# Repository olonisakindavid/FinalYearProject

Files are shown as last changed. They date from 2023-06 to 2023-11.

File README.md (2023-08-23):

# Portable Incubator For Detection Of Coliform In Water Using IoT

## Project Image

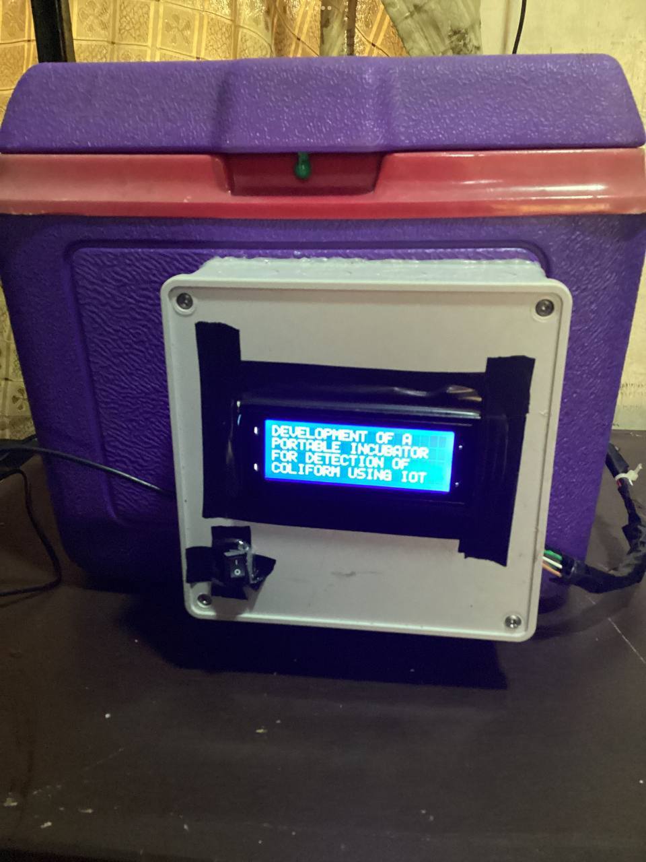
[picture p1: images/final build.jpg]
Project Image


## Description

This repository contains the project "Portable Incubator For Detection Of Coliform In Water Using IoT" created by Olonisakin David and Oguibe Favour. The project focuses on developing a portable incubator device that utilizes Internet of Things (IoT) technology for the detection of coliform bacteria in water.

## Features

- **IoT Connectivity**: The incubator is equipped with IoT capabilities, allowing real-time data transmission and remote monitoring of incubation processes.

- **Coliform Detection**: The device employs cost-effective techniques for detecting coliform bacteria in water samples, contributing to early water quality assessment.

- **Portability**: The incubator is designed to be easily portable, making it convenient for field applications and areas with limited laboratory infrastructure.

## Incubator Images

<div align="center">
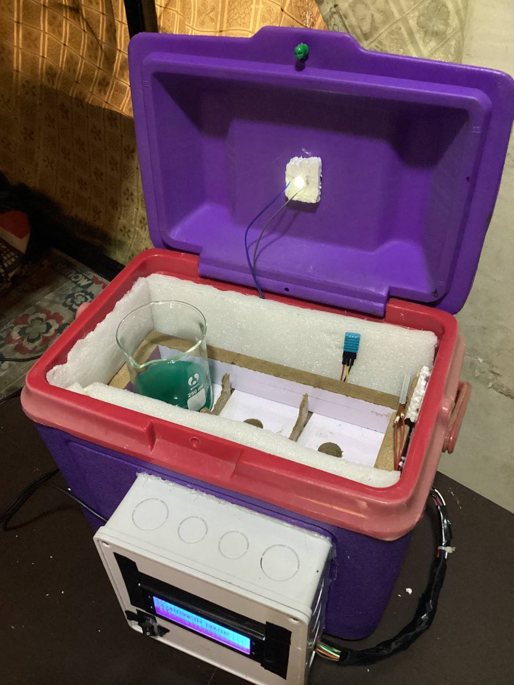
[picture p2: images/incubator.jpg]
Top Open View
  
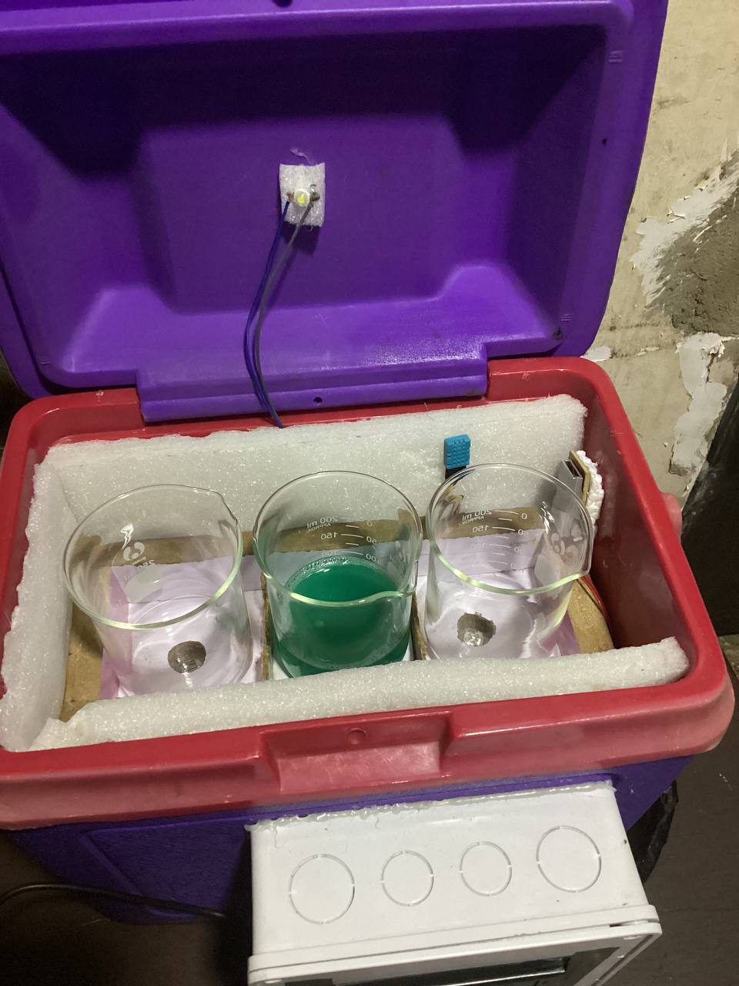
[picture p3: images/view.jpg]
Closed View
  
</div>

## Authors

- Olonisakin David
  Olonisakin David (https://www.linkedin.com/in/olonisakin-david)
- Oguibe Favour
  Oguibe Favour (https://www.linkedin.com/in/favour-oguibe-0a4081195)

## Authors' Image

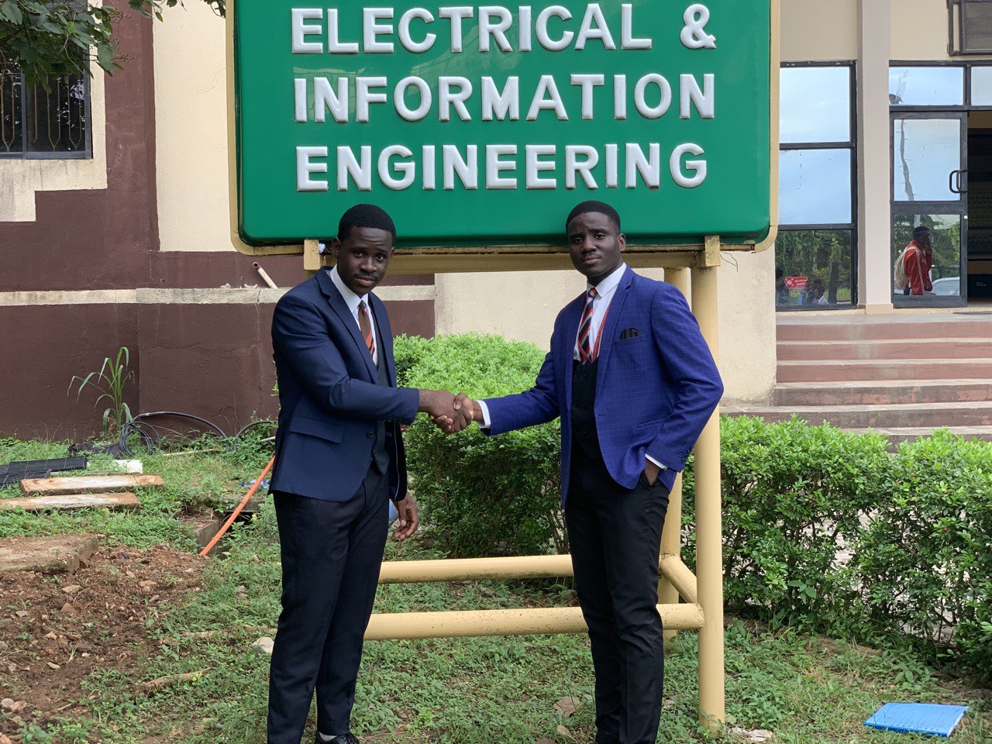
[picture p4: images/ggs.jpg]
Authors' Image


## Blynk Monitoring

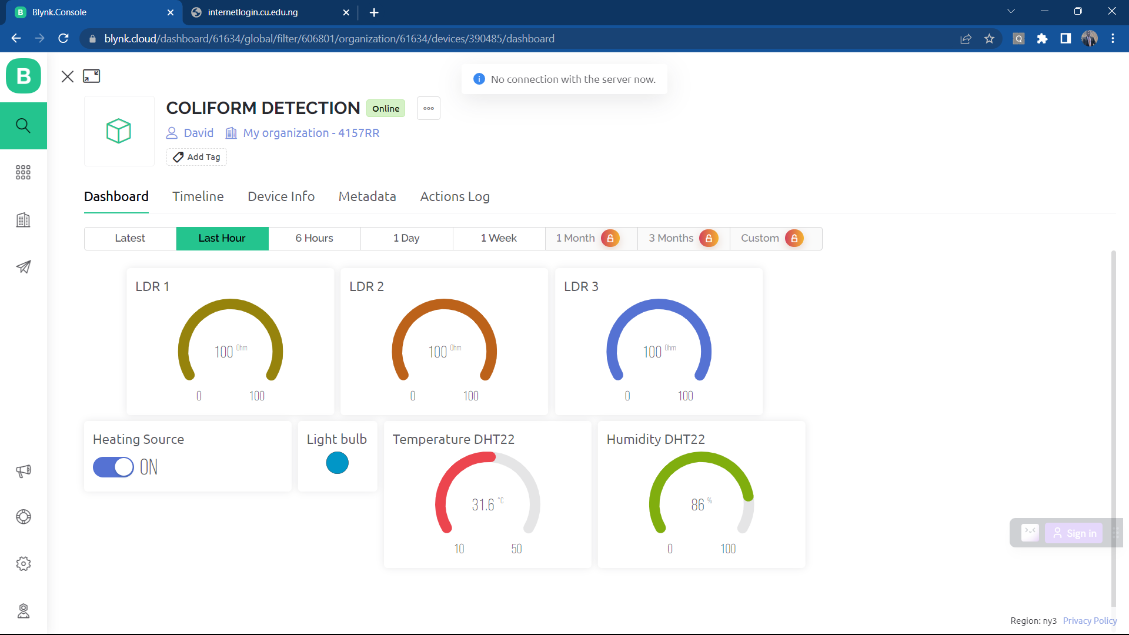
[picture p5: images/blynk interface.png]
Blynk Monitoring


---

**Please Note**: This README will be periodically updated with additional information, usage instructions, and resources as needed.

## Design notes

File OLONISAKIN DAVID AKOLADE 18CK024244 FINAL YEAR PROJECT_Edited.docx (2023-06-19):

DEVELOPMENT OF A PORTABLE INCUBATOR FOR THE DETECTION OF COLIFORM IN WATER USING IOT

BY

OLONISAKIN DAVID AKOLADE

(18CK024244)

A PROJECT REPORT SUBMITTED TO THE DEPARTMENT OF ELECTRICAL & INFORMATION ENGINEERING, IN PARTIAL FULFILLMENT OF THE REQUIREMENTS FOR THE AWARD OF THE BACHELOR OF ENGINEERING DEGREE IN ELECTRICAL AND ELECTRONICS ENGINEERING.

SUPERVISOR:

DR. OSEMWEGIE OMORUYI

JUNE 2023

# DECLARATION

I, OLONISAKIN DAVID AKOLADE (18CK024244), hereby declare that I carried out the work reported in this project in the Department of Electrical and Information Engineering, Covenant University, under the supervision of Dr. Osemwegie Omoruyi. I also solemnly declare that to the best of my knowledge; no part of this report has been submitted here or elsewhere in a previous application for the award of a degree. All sources of knowledge used have been duly acknowledged.

…………………………………………….

OLONISAKIN DAVID AKOLADE

18CK024244

# CERTIFICATION

This is to certify that the project titled “DEVELOPMENT OF A PORTABLE INCUBATOR FOR THE DETECTION OF COLIFORM IN WATER USING IOT” by OLONISAKIN DAVID AKOLADE, meets the requirements and regulations governing the award of the Bachelor of Engineering in Electrical and Electronics Engineering degree of Covenant University and is approved for its contribution to knowledge and literary presentation.

Dr. Osemwegie Omoruyi

(Supervisor) Sign: _________________ Date: ________________

Internal Examiner Sign: _________________ Date: ________________

Dr. Isaac Samuel Sign: _________________ Date: _______________

(Head of Department)

# DEDICATION

This research project is dedicated to my parents, Dr. Rotimi Olonisakin and Mrs. Bolatito Olonisakin who were very understanding and supportive throughout the time taken to complete this project, providing the resources necessary to make this project possible. I also dedicate this project to the countless communities in Nigeria who lack access to clean water.

# ACKNOWLEDGEMENTS

First and foremost, I would like to begin by expressing my deepest gratitude to God for His divine guidance, wisdom, and grace throughout this project. I am forever grateful for His constant presence and blessings in my life.

I would also like to extend my sincere appreciation to my parents for their unwavering love, support, and encouragement. Their sacrifices, guidance, and prayers have been a source of strength and motivation throughout this journey. I am truly blessed to have them as my role models.

I would like to express my heartfelt thanks to my project supervisor, Dr. Osemwegie Omoruyi for His invaluable guidance, expertise, and support. His insightful feedback, constructive criticism, and dedication have been instrumental in shaping the direction and success of this project.

Furthermore, I want to thank the Head of Department, Prof. Isaac Samuel, and all my lecturers for impacting me with knowledge and passing me through various tasks that have, in one way or the other, prepared me for the gallant execution of this project.

Finally, I would also like to acknowledge the support and encouragement of my lovely sisters, Favour and Delight Olonisakin, who have been there for me through thick and thin. Their kind words, motivational messages, and belief in my abilities have helped me to stay focused and motivated.

# ABSTRACT

Having access to clean and safe drinking water is considered a crucial human right, yet millions of individuals continue to live without it. The consumption of water that has been contaminated can increase the risk of experiencing outbreaks of different diseases that are transmitted through water, which are a leading cause of death worldwide. This project aims to develop a portable and low-cost incubator for detecting coliform bacteria in water, which is achieved by using a light-dependent resistor (LDR) and a heating element controlled by an IOT equipped microcontroller (ESP32). The incubator creates a controlled environment for water samples to incubate and for the LDR sensor to detect changes in turbidity, indicating the presence of coliform bacteria. Additionally, a Digital Humidity and Temperature (DHT22) sensor and a heating element helps maintain a temperature range of 35-37°C, the ideal temperature for optimal coliform bacteria growth. The incubator also features a Liquid Crystal Display (LCD) displaying resistance and temperature readings. After the data is collected, it is transferred to the microcontroller and subsequently transmitted to the Blynk application for continuous monitoring and analysis in real-time. The portability and affordability of this incubator makes it appropriate for use in remote areas where access to laboratory equipment is limited. The findings of this study carry significant implications for the advancement of low-cost and portable water quality monitoring systems, potentially leading to improvements in public health.

Keywords: portable incubator, water monitoring, coliform bacteria, light-dependent resistor.

TABLE OF CONTENT

# LIST OF FIGURES

# LIST OF TABLES

# INTRODUCTION

## 1.1 Background of Study

The study was inspired by the need for precise and trustworthy techniques for identifying waterborne infections, especially coliform bacteria, in places with few laboratory facilities. Coliform bacteria are used as a quality gauge for water and are a sign that potentially dangerous diseases may be present. The provision of drinking water is one of the major public health objectives because it is intimately related to human health. Consuming water that contains hazardous chemicals or pathogenic organisms has a major influence on one's health[1].

The lack of low-cost, simple-to-use, and accurate techniques for remote water monitoring and coliform detection is the key issue driving this research. Due to difficulties with transportation, sample storage, and inadequate laboratory facilities, traditional laboratory-based approaches are frequently not practical in remote places. Thus, the creation of a mobile incubator for coliform detection could be the answer to this issue.

The goal of 0074his project is to develop a portable incubator that can quickly and accurately detect coliform bacteria in water using an approach that is both affordable and simple to use. Detection of these organisms consists of, for example, filtering a 100 mL water sample through a membrane followed by incubation of the membrane on selective media at 35 - 37 °C (E. coli) or 44 - 45 °C (TTC) [2] . The issue of restricted access to laboratory facilities for water monitoring and coliform detection can be resolved by the portable incubator, especially in distant locations. The study is important because it may increase access to clean water, especially in locations where waterborne diseases are common. The mobile incubator might also be used for environmental research and monitoring, which would improve water management and public health.

## 1.2 Significance of Study

The development of a portable incubator for remote water monitoring and detection of coliform is an important initiative that can improve access to safe water, particularly in remote areas. Traditional laboratory-based methods for coliform detection are often not feasible in such areas due to transportation, sample storage, and limited laboratory facilities.

This project aims to address the problem of limited access to laboratory facilities by providing a low-cost, easy-to-use, and reliable method for remote water monitoring and coliform detection. The portable incubator is designed to use an LDR and a bulb, where a resistance drop or increase is detected depending on the coliform growth. This data is then sent to the ESP32 for further analysis. Additionally, a DHT 22 sensor is in place to regulate the temperature of the incubator at 35-37 degrees Celsius via the heater. The significance of this study is highlighted below;

1. Improve access to safe water, particularly in remote areas.
2. Enhance public health efforts in identifying and preventing waterborne diseases.
3. Contribute to water management and environmental monitoring research.
4. Increase efficiency in water monitoring by eliminating the need to transport water samples to a laboratory for analysis.
5. Enable citizen science initiatives for community-led efforts towards sustainable water management.

## 1.3 Problem Statement

The current methods for detecting coliform bacteria in water samples require laboratory analysis, which can be time-consuming and resource-intensive. This can limit the ability to effectively monitor water quality, particularly in remote areas. Therefore, there is a need for a portable incubator that can detect coliform bacteria remotely, and enable more efficient and timely water monitoring activities.

## 1.4 Aim and Objectives

Aim: To develop a portable incubator for remote water monitoring and detection of coliform.

Objectives

The objectives of this project are:

i. To design and construct a portable incubator that maintains a temperature range of 35-37°C using a ESP32-powered relay to control the heating element and sensor readings.
ii. To detect coliform bacteria growth using an LDR sensor and a bulb by monitoring the changes in resistance.
iii. To develop a real-time monitoring and data visualization of coliform levels.
iv. To validate the accuracy and effectiveness of the portable incubator in detecting coliform bacteria.

## 1.5 Methodology

The proposed research falls under the field of environmental science and aims to analyze the quality of water samples collected from various sources around Covenant University. The project will utilize the Waterfall model of methodology, an iterative process for creating a system or solving a problem that structures the entire job into segments to ensure precision.

### 1.5.1 Waterfall model of methodology

This project has been completed by following strategy, which is given in Figure 1.1

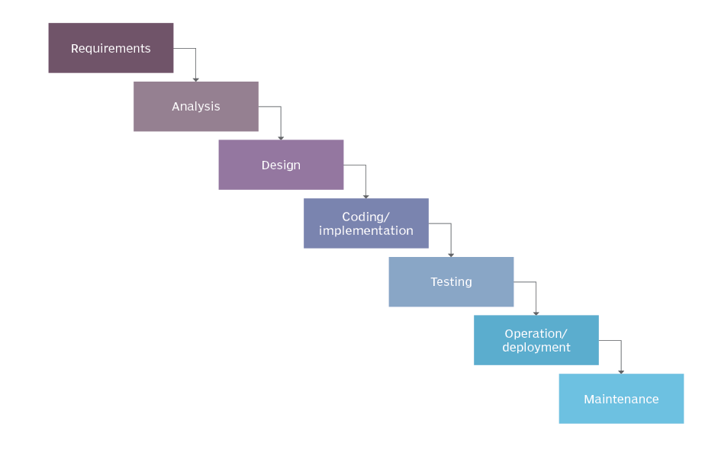
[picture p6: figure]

Figure 1.1: Waterfall model

### 1.5.2 Description of the Waterfall model

The work has been grouped into seven sections;

1 Requirements Gathering Phase: In this phase, the aim and objectives of the project will be defined, and the specific requirements for the research will be gathered.
2 Analysis Phase: In this phase, the water sources around Covenant University will be analyzed, and the most suitable water samples for the experiment will be identified and selected based on specific criteria.
3 Design Phase: In this phase, the portable incubator will be designed, and the DHT22 sensor and LDR will be integrated into the system.
4 Implementation Phase: In this phase, the incubator will be set up, and the selected water samples will be placed in it. The temperature and light exposure within the incubator will be monitored using the DHT22 sensor and LDR, respectively.
5 Testing Phase: In this phase, any changes in the resistance levels of the LDR due to bacterial growth in the water samples will be recorded.
6 Deployment Phase: In this phase, the data collected during the testing phase will be analyzed using statistical methods to determine the presence and concentration of coliform bacteria in the water samples.
7 Maintenance Phase: In this phase, any necessary adjustments to the experiment will be made based on the findings of the study. Finally, conclusions and recommendations will be drawn based on the results obtained.

## 1.6 Scope of Study

The scope of this study is to design and develop a low-cost and portable incubator for remote water monitoring and detection of coliform bacteria. The incubator will utilize a light-dependent resistor (LDR) to detect changes in turbidity, and a DHT22 sensor to maintain a constant temperature of 35-37°C within the incubator. The incubator will be powered by 230 AC – 5V DC power adapter and monitored using ESP32 module. The study will involve designing and constructing the incubator, testing its sensitivity and specificity for detecting turbidity increases, and evaluating its performance in a real-world setting. The study aims to provide a low-cost and effective solution for monitoring water quality in remote areas where access to laboratory equipment is limited.

## 1.7 Limitations of the Study

Limitations associated with this project include:

i. The accuracy of the coliform detection may be affected by factors such as the quality of the water sample or the calibration of the LDR sensor.
ii. The use of an ESP32 microcontroller for data transmission may have limited range and reliability in remote areas with poor internet connectivity.
iii. The incubator may require frequent calibration and maintenance to ensure consistent temperature and humidity levels for accurate readings.
iv. The heating source required to increase the temperature in the incubator uses up a significant amount of power, which makes it impractical to use a battery as a power source.
v. The size and portability of the incubator may limit the amount of water samples that can be tested at once, potentially affecting the scalability of the system.

## 1.8 Project Organization

Chapter One: It provides a general overview of the project, background

information, the project's goal and objectives, the issues it aims to address, and a

brief description of the approach.

Chapter Two: Provides a review of the literature and investigates past relevant

studies on the project's issue. It gives a theoretical framework as well as other ideas

necessary for a complete grasp of the project.

Chapter Three: It discusses the project's methodology, the various components

required with specifications, and the project's design, as well as all of the

components required for innovation, system block diagram representation, and

hardware design.

Chapter Four: It covers the implementation and testing of the project. The project's

practical system design and in-progress photos will be shown. The results of the

project will be discussed.

Chapter Five: The last chapter. It contains the study's conclusions and outcomes. It also displays the project's achievements.

# LITERATURE REVIEW

## 2.1 Introduction

Many researchers have investigated the prevalence of coliform bacteria in various water sources. The existence of coliform bacteria in drinking water is a major public health concern. Although total coliform bacteria are widespread and typically not harmful, the presence of fecal coliforms and E. coli may pose a potential danger to human health. Coliform bacteria are commonly used as water quality indicators and are divided into three categories: total coliforms, fecal coliforms, and E. coli[3] . This chapter provides a comprehensive overview of Coliform bacteria, including the major factors that contribute to their presence in water, the potential health effects of exposure to these bacteria, traditional methods for detecting them in water, relevance of IoT technology in the detection of Coliform bacteria in water and review similar works in the literature.

## 2.2 Coliform Bacteria: A Quick Overview

Coliform bacteria are rod-shaped, non-spore-forming, Gram-negative, oxidase-negative, facultatively anaerobic organisms that have a cell wall appearing pink or red when stained and can survive in both oxygenated and non-oxygenated environments [4]. Coliforms are a type of bacteria that can be found in the digestive systems of animals, including humans, as well as in soil and plants. While generally not harmful, the presence of specific types of coliforms, such as E. coli, in drinking water can indicate that the water may be contaminated with feces, which can pose a risk of infection. If E. coli is found in the water, there is a possibility that other pathogens may also be present, since E. coli itself can be a pathogen. The intestine of warm-blooded mammals is where it typically began [5]. In the past, the presence of the intestinal bacteria known as coliforms has been cited as a sign that a location has been contaminated by sewage from people. Additionally, the feces of affected people contain harmful germs including Shigella and Salmonella[6].

Coliform bacteria are classified into three types that indicate the safety of water and differ in the level of risk. The term "total coliform" encompasses a wide range of bacteria, including those present in fecal matter, which is a subset of all coliforms. E. coli is a type of fecal coliform bacteria. When testing drinking water samples, laboratories check for the presence of total coliform, and if it is detected, the sample is further examined for the presence of E. coli[3] . The presence of total coliform bacteria is commonly observed in nature and does not pose a significant threat. When only total coliform bacteria are detected in drinking water, it suggests that the contamination source is likely environmental [7].

Total Coliform Bacteria: The total coliform bacteria, which are common in the ecosystem and are most commonly found in dirt or plants, are usually safe. If a lab only finds total coliform bacteria in drinking water research, it is likely that the bacteria came from the environment and fecal pollution is rare. However, there is a chance that harmful germs could get inside the system if it is prone to external pollution. As a result, it is vital to find and resolve the contamination's main cause.

Fecal Coliform Bacteria: Fecal coliform bacteria, which are a subgroup of total coliform bacteria, are abundantly found in the intestines and feces of both humans and animals. The identification of fecal coliforms in a water sample is typically indicative of recent fecal contamination, and this poses a higher risk of potential pathogen presence compared to situations where only total coliform bacteria are identified[7].

Escherichia coli: The bulk of E. coli types usually pose little worry and typically live in the guts of humans and warm-blooded animals. E. coli is classed as a subset of fecal coliform germs. However, some kinds of E. coli can make people ill. When E. coli bacteria are found in a potable water sample, it usually means that there has been recent fecal pollution, which boosts the chance that disease-causing germs are present [7]The identification of Escherichia coli in water samples typically indicates fecal matter contamination, along with the potential presence of pathogenic organisms of human origin[7]. Since E. coli can also be a pathogen, there is a possibility that other pathogens will also be present if E. coli is discovered in the water[5]. Escherichia coli bacteria were typically found in sewage discharges from human, animal, and plant sources, in that order. Septic system failure, municipal landfills, and wastewater sludge application to the land are all examples of human sources. Fecal coliform

bacteria also enter from a variety of animal sources, including domestic pets, wildlife, livestock, land application of manure, pasture areas and feedlots[8].

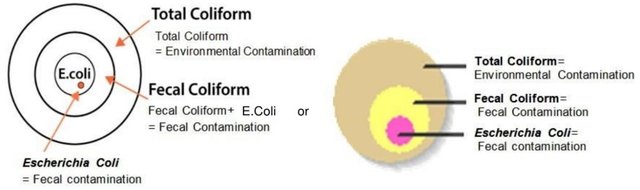
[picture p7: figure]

Figure 2.1: Different Groups of Coliform Bacteria [7]

## 2.3 Significant Factors that promote Coliform Bacteria infestation in water

Water sources containing coliform bacteria pose a significant risk to the public's health and are frequently contaminated by feces due to improper sanitation practices or agricultural activities. It has been claimed that septic tank systems and farm waste are the main contributors to coliform bacteria in drinking water. Septic tank overflow and other related factors contaminating drinking water sources with human feces particularly raise the risk of Coliform contamination. The risk of contracting a waterborne disease can also be increased by the use of pesticides and fertilizers in agriculture, which can reduce the spread of coliform bacteria to water sources. Finding and monitoring coliform bacteria in drinking water is essential for maintaining public health and halting the spread of infectious illnesses.

### 2.3.1 Septic Tank Systems.

One of the most significant issues facing the world today is water contamination. Septic tank effluent intrusion is one of the main sources of groundwater contamination. The main source of harmful viruses and bacteria in the subterranean environment may be septic tank effluent[9]. Contamination of aquifers has become a common problem as a result of excessive groundwater pumping and uncontrolled human wastewater dumping into the groundwater. Groundwater quality can be impacted by residential, business, industrial, and agricultural activities. Groundwater is particularly sensitive in regions with large population densities and extensive human use of the land[10]. Waste is temporarily stored in a septic tank while being pre-treated at that time. There have been reports of septic tanks failing and leaking a lot, harming the ecosystem[11]. Studies have been conducted by various researchers to demonstrate the negative impacts of situating septic tank systems close to drinking water sources. An investigation into groundwater contamination in the Agbowo neighborhood of Ibadan, Nigeria, as well as the effects of septic tank distances from wells was conducted[12]. Septic tanks have been found to fail and leak profusely, causing environmental damage[11] As a result, septic tanks are the primary source of waste that is directly released into groundwater. So, in order to safeguard both the environment and human health, it is essential to monitor water[13]. Replicas of forty (40) ground water samples were collected from groundwater sources at different distances for bacteriological analysis, and it was found that they were all infected with different types of bacteria as well as coliform[12]. The number of feces and total coliforms decreased with increasing distance from septic tanks, and this effect was more pronounced for water supply distance from pollution sources. Because the problem of septic tank contamination of ground water is a national concern rather than a local one in the study region, measures should be taken by developing standards for the isolation of wells from septic tanks and the treatment of well water before use[12]. Consuming groundwater that has been faecally contaminated and not properly treated has been related to disease[14].

Underground water, or the water found below the earth's surface in soil pores and rock formation fractures, has been impacted by the deterioration of the physicochemical and biological qualities of water brought on by industrialization and urbanization, which have grown over time without consideration for the effects on the environment[15]. As a result of population expansion and urbanization, ground and surface water are subject to greater demands. The startling rate of urbanization in Nigeria is reflected in the 10–15% yearly growth rates of the country's main cities[16] hence human activities like enhancing soil fertility, irresponsibly disposing waste, and utilizing pit latrines, soak-away pits, and septic tanks are increasing. In Nigeria, it is challenging to find pipe-borne water, thus many homes have wells that are close by but separate from the septic tank. Only 52% of Nigerians have access to adequate drinking water sources[17]. The most common causes of pollution include the close proximity of septic tanks to wells, the unhygienic use of the wells (for example, some wells have no covers or lids; they are dirty and unkempt, making the water unfit for use, resulting in water-borne diseases), and the unhygienic use of the wells. Additionally, the discharge of solid or liquid waste into pits, abandoned boreholes, stream channels, landfills, or other unlined sites may result in groundwater contamination[18].

The authors of a different study investigated the origins of E. coli contamination in the coastal subtropical climate. They found that septic systems were a substantial source of E. coli and total coliforms in both surface water and sediment. It was evident that septic systems were a substantial source of pollution since there was a positive correlation between the amount of E. coli in sediment and the distance from them. The authors asserted that septic systems are a significant source of fecal contamination in coastal areas and suggested introducing measures to guard against contamination from septic systems[19]. Another study looked at how the presence of septic tanks affects the quality of the borehole water in Port Harcourt, Nigeria[20]. In order to reach their conclusions, the researchers collected water samples from boreholes both close to and distant from septic tanks. Total dissolved solids (TDS), pH, total suspended solids (TSS), and bacterial contamination were all investigated in the water samples (TSS). The researchers found that the water quality in boreholes near sewage tanks was significantly lower than in boreholes farther away from septic tanks. The water samples collected from the vicinity of septic tanks contained higher concentrations of TDS, TSS, and bacterial contamination, including coliform bacteria[20].

Another study used one-way ANOVA (Analysis of Variance) to examine the relationship between fecal coliform contamination and proximity to the septic tank. The results showed that fecal coliform was present in 96 percent of the sampled wells, indicating that the drilled well's biological drinking water quality had been significantly diminished. The excavated well was 53.7 feet away on average from the septic tank. The results of the investigation showed that as the distance between the septic tank and the drilled well rose, the level of fecal coliform contamination dropped. There were strong evidence of fecal pollution in the dug-well water at 50% of the septic tanks within 50 feet[21].

1. Septic tank setback distances from water sources

Since the distance between septic tanks and water sources plays a significant role in the coliform bacteria that cause water to become contaminated, various approaches for estimating setback distances and conditional probabilities have been examined. In the past, the majority of governmental organizations enforced minimum setback distances between septic tanks and drinking-water wells to restrict where septic tanks may be located[22]. How likely is it that a setback distance (such one required by the regulatory body) will be adequate to protect the city's ground water from virus contamination? Given a specific probability level, what setback distance would be necessary to ensure that the ground water would be immune to virus contamination?[23] With little respect for the local geology, hydrology, and meteorology, these setback distances are often required for at least a county-wide area[23]. Various places have different topologies. Therefore, proper setback distance calculations must be made by regulatory agencies in order to ensure that the distance of septic tanks from water sources would give complete assurance that the water is not contaminated with coliform. A study revealed that a setback distance of 40 m would be required for a specific location under consideration in order to be 90% confident that the ground water would be appropriately protected from virus contamination. If one wanted to be 99% sure that the setback was enough to stop viral transmission in places where 15-m distances were first permitted, an 80-m distance would be required[23].

2. Inadequate agriculture practices

Numerous studies have demonstrated how agricultural pollution may significantly contribute to the coliform water contamination. One of the main sources of contamination is the over use of fertilizers, notably those containing nitrogen and phosphorus. According to the National Geographic Society, nutrient contamination brought on by excessive fertilizer use leads to eutrophication, a process that harms both terrestrial and aquatic ecosystems by overburdening them with nutrients[24]. Coliform water contamination is a global problem that threatens the health of both people and animals. Ineffective agricultural techniques have been identified as one of the main sources of this problem. For instance, it is common knowledge that increasing soil fertility with animal manure also increases the quantity of fecal coliform bacteria in the water. Therefore, excessive levels of fecal coliform bacteria and other pathogens can contaminate surface and groundwater when animal dung is improperly handled or applied[25]. Surface water, such as streams and rivers, can be contaminated by runoff from feedlots and farms, and groundwater can be affected by pollutants that seep through the soil layers. People and animals may be exposed to toxins while using contaminated groundwater for irrigation or drinking. Various management strategies can be applied to lessen the quantity of water pollution brought on by agricultural activities. Among these include reduced use of pesticides and fertilizers, conservation tillage, nutrient management programs, and manure management strategies. Additionally, by creating buffer strips or wetlands or increasing irrigation effectiveness, runoff can be reduced and contaminants in surface water can be filtered[26]. Water sources may be impacted by pesticides, herbicides, and fungicides used in agriculture. It is well recognized that these agricultural contaminants deteriorate groundwater and surface water quality[27]. Using contaminated irrigation water and disposing of animal corpses inappropriately are two other poor farming techniques that could cause coliform contamination[28]. Rainfall and flooding are other causes of water contamination. They accomplish this by introducing potentially harmful chemicals and contaminants into water sources from a variety of sources. Studies conducted in the lab and in the field indicate that there are significant numbers of bacteria in water, which are primarily brought on by frequent tidal floods and strong rain events[29]. Inadequate water consumption spurred on by population increase, urban wastewater runoff, hospital waste, and institutional waste are other causes of coliform contamination of water[21].

Poor hygiene habits, such as defecating outside, and poorly maintained wells that have free access make them more susceptible to anthropogenic pollutants[30]

## 2.4 The significance of finding Coliform bacteria in water

Monitoring is the primary line of defense against diseases brought on by dangerous microbes. Effective detection methods are needed in order to control this effect[31].

For the purpose of detecting the presence of contaminants in water, accurate and quick reaction detection technologies are required[32]. Water safety and cleanliness are basic human rights and needs for all living beings[33]. The three most basic uses of water—drinking, food preparation, and personal hygiene—require each person to use at least 7.5 liters of water per day in the home. At least 50 liters of water per person per day are necessary for all requirements related to personal cleanliness, food hygiene, housekeeping, and laundry[34]. However, due to its importance as a way of propagating pathogenic organisms, man is now worried and terrified of it[35]. Animal and human waste is a significant contributor to water pollution, which is extremely hazardous to the health of millions of people worldwide. Waterborne illnesses like cholera, polio, diarrhea, hepatitis, typhoid, dysentery, and gastroenteritis are brought on by these microorganisms that contaminate the water supply[36]–[38]. One of the top 15 global killers is diarrheal disease[39]. More children die from diarrhea than from tuberculosis and malaria combined[34]. Millions of people globally are afflicted by other ailments linked to WASH. Over 800,000 deaths are attributed to inadequate WASH each year, particularly among children under five[40]. Elderly and young people often suffer more from the harmful health effects of drinking water contaminated with E. coli[41]. One of the greatest challenges to advocating for and implementing safe water initiatives is the difficulty of measuring and assessing the microbiological features of water in rural developing communities. Many remote settlements lack the equipment and knowledge necessary to assess the microbiological purity of the water before use. Despite the large number of hazardous microbes, testing for all of them is challenging[42]. In order to reduce the reliance on laboratory testing and avoid the difficulty, expense, and delays associated with sending samples offsite for testing, particularly in situations where the closest laboratory is far away or doesn't have a reliable electricity supply, there is a high desire for simpler, quicker, and less expensive procedures that will allow for more regular testing of water for communities or individual households[43].

## 2.5 Traditional methods of detecting Coliform in water

Drinking water is an oligotrophic system, thus the inability of culture methods to recognize starved and stressed bacterial cells could have serious repercussions by drastically underestimating contamination levels. There are other alternative methods for recognizing coliforms, albeit they are all at different stages of development and implementation. In this overview, cutting-edge and new methodologies are discussed alongside the fundamental principles and accepted practices of traditional methods of Coliform detection. Additionally, based on each method's benefits and drawbacks, the efficacy of finding coliforms in oligotrophic environments, such drinking water, is assessed. Additionally, criteria like detection sensitivity and limit, amount of time needed to collect data, and laboratory costs are taken into account (including skill, labor, and cost)[4].

Traditional methods include membrane filter technique, multiple-tube fermentation technique, enzymatic/defined substrate method and molecular methods.

### 2.5.1 Membrane filter technique

One method for estimating the number of microorganisms in drinking water is the membrane filter technique, which has achieved acceptance in a number of countries. Membrane filter technology is used to keep an eye on water quality. This method comprises running a water sample through a 0.45 mm-pore filter that is sterile and bacteria-retentive. After the filter has been cultivated on a selective medium, the typical colonies on the filter are then counted. Different media and incubation conditions were investigated in order to determine the best procedure for recovering coliforms from water samples. In North America and Europe, respectively, the m-Endo-type media and Tergitol-TTC medium are widely used for drinking water analysis[44]. Coliform bacteria produce yellow-orange colonies on Tergitol-TTC media after 24 to 48 hours of incubation, whereas they produce red colonies with a metallic sheen on an Endo-type medium containing lactose. Although research suggests that m-Endo agar is more effective at producing higher numbers of coliforms, other media, such as MacConkey agar and Teepol medium, have been used in South Africa and the United Kingdom. To determine the number of fecal coliforms present, filters are frequently cultivated for 24 hours at 44.5°C on an improved lactose medium (m-FC)[44].

### 2.5.2 Multiple-tube fermentation technique

Over the past 80 years, the multiple-tube fermentation (MTF) approach has become a popular methodology for enumerating coliforms and monitoring water quality. As part of the technique, a number of tubes with different decimal dilutions of the water sample are introduced. When there is gas generation, acid formation, or significant growth in the test tubes after 48 hours at 35°C, this is a positive presumptive reaction. Lauryl tryptose broths and lactose broths can both be used as presumptive media. Confirmation tests are run on all tubes following the observation of a positive presumptive result. A brilliant green fermentation tube of lactose-bile broth must produce gas within 48 hours at 35°C to pass a confirmation test[4].

The outcomes of the MTF method are expressed using the most probable number (MPN), which is a statistical estimation of the mean number of coliforms. Using this technique, it is possible to determine the coliforms semi-quantitatively. The measurement's level of precision is poor because few tubes were used for the analysis. The likelihood of getting a negative result when using five tubes, each with a volume of 1 ml of the material, is less than 1%.

Despite its limitations, the MTF technique is still widely used and a good way to check water quality. Some of its benefits include simplicity and low expense. However, compared to the defined substrate approach, this technique has a significant disadvantage due to its lengthy incubation period. The MTF technique is a vital instrument for ensuring the safety of drinking water because it can identify both total and fecal coliforms. However, the MTF technique's lack of accuracy, brought on by its reliance on statistical estimates, raises the possibility that it may not be the best technique in circumstances where high precision is required. Alternative approaches with higher accuracy, like PCR-based techniques, may be preferred in such cases.[4]

### 2.5.3 Molecular methods

There are now a variety of molecular methods that can quickly, sensitively, and accurately identify infectious pathogens in clinical samples and assess the microbiological safety of food and water. These methods have been developed over the past 20 years. Without separating or growing the microorganism, these procedures can frequently offer qualitative and quantitative information about the existence and quantity of the targeted microbe in the samples. These methods can also be changed in order to identify a specific pathogenic trait carried by the microorganism. A vast variety of target molecules can be found, with each technique's goal being to give knowledge for the prevention of infectious diseases[45]. The following are the molecular techniques used to find coliforms in drinking water

1. Polymerase chain reaction method

Researchers can swiftly amplify a very little DNA sample (or a portion of it) to a big enough quantity to investigate in detail using the polymerase chain reaction (PCR), which is a technique that is routinely used to produce millions to billions of copies (full or partial) of a given DNA sample[46]. An amplified DNA target segment can now cycle through replication thanks to this reaction. A DNA polymerase (Taq polymerase) catalyzes a chain reaction, and oligonucleotidic primers are utilized in this replication, which can be done in vitro or in situ. The sensitivity of the detection depends on the degree of homology and complementarity between the target and primer as well as the hybridization temperature[44]. The ability to identify coliform bacteria was investigated using gene probe detection and polymerase chain reaction (PCR) amplification of portions of two genes, lacZ and lamB. Salmonella spp. and noncoliform bacteria were not discovered when a section of the lacZ coding area of Escherichia coli was amplified using PCR primers with an annealing temperature of 50 degrees C. However, the procedure did detect E. coli and other coliform bacteria, including Shigella spp. Salmonella, Shigella, and E. coli spp. were all discovered using the selective detection of E. coli by amplification of a section of E. coli lamB using a primer annealing temperature of 50 degrees C[47].

2. Nucleic Acids

Nucleic acid polymers, such as DNA and RNA, are good molecular targets for identifying species and identifying specific phylogenetic sources. Numerous molecular techniques for coliform detection have been developed thanks to the stable genotype properties of nucleic acids[45]. Coliforms in drinking water must be found in order to protect public health, and nucleic acid-based molecular techniques have proven to be a quick, sensitive, and reliable way to do so[44]. Overall, nucleic acid-based molecular approaches provide a number of advantages over traditional culturing methods for the identification of coliforms in drinking water. They don't require labor- or time-intensive culturing methods and can identify coliforms rapidly and precisely. These techniques are essential because they reliably identify the presence and amount of coliforms in water samples, protecting public health, and preventing the spread of infectious diseases [44].

### 2.5.4 Enzymatic method/defined substrate method.

The Colilert-18 is one of the most often used defined substrates for the enzymatic test because it contains the nutritional indicators ONPG and MUG from Defined Substrate Technology (DST), which confirm the presence of E. coli and Coliform bacteria. The US EPA has authorized the reagent as a routine procedure for evaluating treated and tainted water since it may deliver results in just 18 hours. With the use of this reagent, you may attain 100% test accuracy. Colilert-18 reagent will be entirely soluble in water after being shaken into water samples[48]. Other efficient substrates, such those created by the Italian business Liofilchem, are already on the market and are suitable for the detection of coliform in water. Samples are incubated for 18–24 hours at 37°C or for up to 48 hours at room temperature (20–25°C)[49]. Coliforms have the enzyme β-galactosidase, which they use to create gases and acids when the temperature is between 35 and 37 °C, which is ideal for growth[50]. A certain enzyme will produce color or fluorescence when it digests a chromogenic or fluorogenic substrate. These substrates have been used to determine whether or not certain enzymes are present or active in water. In order to identify the presence of b-D-glucuronidase in E. coli, researchers utilized the chromogenic substrate indoxyl-b-D-glucuronide (IBDG). Several commercial tests based on this defined substrate technology were subsequently developed, including Colilert (IDEXX Laboratories, Portland, ME, USA), Colisure (Millipore Corporation, Bedford, MA, USA), and Coli-Quick (IDEXX Laboratories, Portland, ME, USA) (Hach, Loveland, CO, USA)[4].

## 2.6 Internet of Things (IOT): A Quick Overview

The term "Internet of Things" (IoT) refers to a network of actual physical items that have been integrated with sensors, software, and other technologies and are able to communicate with other devices and systems over the internet without the need for manual input. These gadgets include anything from common domestic items to high-tech industrial gear[51]. These objects have the ability to perceive, communicate, interact, and function together without requiring human-to-human or human-to-computer interaction thanks to integrated technology and a network of physical objects[52]. The Internet of Things (IoT) is about more than just connected devices; it's also about the data those devices gather and the immediate, potent insights that can be drawn from it [53]. Internet of Things (IOT) increases productivity since it reduces reliance on humans[54]. This program has been used to develop programs for monitoring ranging from surveillance, healthcare, and the environment all around the world[55].

### 2.6.1 Structure of the Internet of Things (IOT)

Sensors, microcontrollers, and application platforms make up the IOT architecture.

1. Sensors

IoT sensors track environmental changes in real time by detecting the physical environment[56]. The major objectives of IoT sensor networks include (i) receiving important information from the outside physical world, (ii) sampling internal system signals, and (iii) using sensor data to offer relevant information for decision-making[56], [57]. These sensors have nodes built in that are linked to microcontrollers that are in charge of reading and analyzing the data collected by the sensors. Temperature, pressure, humidity, level, accelerometer, gas, gyroscopes, motion sensors, image, optical, RFID, and infrared (IR) sensors are the most often utilized IoT sensors[56]. The small size of the sensor causes technical restrictions in areas like computational power, battery life, networking ability, storage capacity, and memory, despite the fact that sensors have a wide range of applications. This means that these sensors could be very vulnerable to errors, assaults, and simple failure, which could lead to the loss of sensor data and erroneous information[56].

2. Microcontroller

A microcontroller is a small computer with network access and program execution capabilities. The controller manages the collection of numerical data from the sensors, which it can then upload to the cloud or the internet for storage and analysis[58], [59]. Minicomputer- and microcontroller-board-based IoT controllers can be distinguished from one another. Microcontrollers like Arduino are more affordable than minicomputers and can run the same program repeatedly. The ESP is an additional instance of a microcontroller (ESP32, ESP8266). As an alternative, portable, full-featured computing devices that are capable of handling a variety of tasks include minicomputer-type controllers like the Raspberry Pi. While an Arduino board requires additional external hardware in order to connect to the internet, the Raspberry Pi comes with an Ethernet and Wi-Fi network interface built in[59].

3. Application Platform

Without applications, the Internet of Things is meaningless. Applications for the Internet of Things provide reliable communication and real-time message transmission. An application is essentially a piece of software that runs online and, after receiving input from a microcontroller, displays data via a user interface. Some platforms, like Blynk, provide apps for managing and monitoring IoT devices using mobile devices. FreeBoard, Ubidots, and ThingSpeak are three other popular platforms for IoT applications[59].

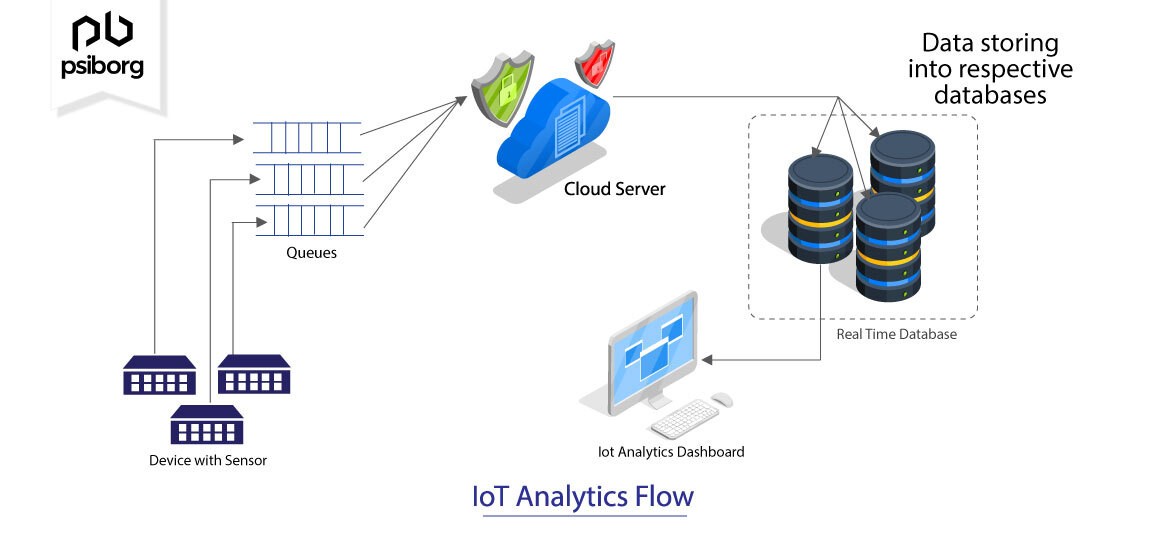
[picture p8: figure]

Figure 2.2: IoT Analytics Flow [60]

### 2.6.2 IOT's relevance for detecting bacteria in water and its utility in detecting coliform

Water samples and the data that go with them are often processed and examined in laboratories. This may take a lot of time and effort and result in less trustworthy results. In light of the situation, it is essential to establish a suitable and organized system to continuously monitor and manage water resources in order to address connected challenges. Thanks to the Internet of Things (IoT), real-time remote measurements may be conducted with little to no human participation, providing a great alternative to conventional, complicated, and unsuccessful techniques for reaching this goal[61]. Due to the harmful health implications of consuming contaminated water, real-time water quality monitoring is now required. The Internet of Things (IoT) domain addresses this problem by providing creative and reasonably priced solutions for the problems of water contamination detection and water quality analysis[62].

The following are some benefits of using IOT for water quality monitoring:

1. Decreased cost of computing: The considerable amount of computing work, like that required by the Ubidots IoT-Platform, is handled by cloud servers. With the passage of this law, any widely used processor-based node (such as the NodeMCU (ESP32) kit) may be used in place of sophisticated microprocessors like the Raspberry Pi 4 Model-B, DE1 SoC FPGA board, etc [63].
2. Hardly any human involvement: IOT systems can increase efficiency by reducing reliance on humans[64].
3. Low cost: IoT solutions are generally more cost-effective than traditional water monitoring techniques since they make use of currently in use, commercially available communication infrastructure, which is also more time-consuming[63].
4. Low power requirements: The local nodes only need to carry out minimal work after shifting the majority of the computing workload to the cloud server, and they can then primarily sleep. This made it possible to operate sensor nodes in far-off places with a little battery.
5. Real-time feedback delivery: The proper water authority and end users can both immediately receive real-time input from these systems via SMS, email, Twitter, Facebook, and other means[63].

## 2.7 Review of related works

This section analyzes experiments that involved the development of an improvised incubator for coliform growth in contaminated water samples as well as the identification of coliform and other types of bacteria in water using Internet of Things (IoT) technology. The next paragraphs concentrate on a few of the numerous research studies that have been carried out in this field.

A sensor-based Water Quality Monitoring System was employed in another study[52] to measure the water's molecular and physical properties, including its pH, temperature, turbidity, and Total Dissolved Solids. (TDS). The authors' IoT-based solution consisted of three main components: a multiparameter water quality analyzer, a means for information transmission, and a computer system unit. Sensors, Wi-Fi wireless transmission, an STM32 single chip microcontroller, and remote water quality monitoring were all included in the proposed system. The data on water quality collected were evaluated using ANOVA-based statistical analysis to identify the key causes of the river Krishna's deteriorating water quality. In order to identify the primary causes of water pollution, the writers gathered and examined real-time data on the river Krishna's water quality using IoT-based water quality monitoring.

An Internet of Things (IoT)-based technique for predicting bacterial contamination in water was proposed by the authors of a study paper[61]. The system places a variety of instruments around the study area, including those that track dissolved oxygen, turbidity, pH level, water temperature, and total dissolved solids, to evaluate the water quality. These sensors transmit the data they have collected to a server using GSM modules, where it is processed and examined. The scientists used machine learning methods to predict the presence of coliform bacteria in the water based on the sensor data collected by the IoT system. The proposed approach provides a more useful and cost-effective alternative to manual lab analysis, which is an expensive and time-consuming process for bacterial prediction. In order to predict the presence of coliform bacteria in water, the authors created an IoT-based system that uses a variety of sensors and machine learning techniques, providing a quick and cheap alternative to traditional lab examination.

A battery-powered incubator that can maintain 35°C±1°C in an atmosphere (incubator) of 25°C for up to 65 hours is described in another study[65] free, open-source design. The objective of this incubator is to provide humanitarian engineers with a quick, simple, and visually pleasing method to assess the microbiological water quality in remote locations. The writers use 3M Petrifilm E. coli/Coliform (EC) Count Plates to determine the presence of E. coli in water samples. These dishes need to be incubated at a temperature that is close to body temperature. In order to meet this need, the portable incubator was developed, and the authors demonstrate that it can maintain the required temperature range for up to 65 hours. However, the use of IoT in the research is not acknowledged by the authors. As has been shown, IoT has the ability to improve water quality monitoring in a number of ways. For example, Internet of Things (IoT) devices could provide real-time data on factors influencing water quality, such as temperature, pH, dissolved oxygen, and turbidity. This data may be sent to a central database for analysis and visualization, allowing for swift and educated decision-making. Additionally, IoT can allow remote water quality monitoring, doing away with the need for labor-intensive manual analysis.

In a different study, the authors used the Internet of Things to monitor and track the water quality in real-time[58]. They suggested a system that uses IoT sensors to measure pH, temperature, and turbidity in addition to other elements of water quality for use in homes. The system's objective is to offer remote internet access for managing and evaluating water purity, for instance through a mobile application. The proposed system uses Big Data Analytics and Machine Learning techniques to analyze water quality data in-depth, allowing the early detection of threats. In conclusion, the research's authors used IoT sensors and big data analytics techniques to measure and track water quality in real time, making it possible to identify risks early enough to prevent them and to manage water quality remotely.

In a different study[48], the authors developed a portable incubator for the development of coliform and E. coli germs using IoT technology. With the aid of this portable incubator, microbiologists can evaluate the quality of the water anywhere—not just in laboratories. The incubator can be used to identify E. coli and coliform bacteria in water samples using both qualitative and quantitative techniques. Two-factor authentication security enables real-time tracking, and the incubator can cut the detection period to just two hours. (2FA). The capability of the device to reach and maintain a predetermined temperature (typically 35–37°C) under various conditions, a procedure known as bacterial growth, determines the device's dependability. The incubation procedure can be carried out manually or automatically using computer vision and Internet of Things (IoT) technology. Data is protected by encryption techniques in the incubator, and the connection between the device and Wi-Fi is also secure. The outcomes of their experiment can also be observed in real time using IOT apps. In conclusion, the researchers developed a movable E. coli and coliform bacteria incubator using IoT technology that can detect the presence of these bacteria in water samples using both qualitative and quantitative techniques. Because it is dependable, secure, and can cut the detection time to just two hours, the incubator is an essential tool for microbiologists to use when conducting water quality checks all over the world.

In a different study[66], the authors describe a method for building a movable, affordable incubator for drinking water microbiological testing. The incubator prototype can be modified to handle a variety of materials and volumes and has a demountable design that makes carrying it easy. It can be used in grid-powered, established labs as well as remote areas with solar or automobile batteries. The design uses components that are typically available, can work in a variety of outdoor settings, and maintains the advantages of more expensive laboratory-based models. In order to assess the microbes in drinking water, the writers wished to address the need for a portable, affordable incubator. A range of culture-based microbiological methods, such as membrane filtration and cultivation to assess the potability of drinking water, can be used in the incubator. Overall, the authors' work suggests that their design may provide a practical and affordable alternative for the incubation of microbial colonies in the lab and the field. Their approach has the potential to be extensively applied in low-resource areas where it may be difficult to obtain specialized equipment. However, they did not incorporate any kind of IOT into their architecture.

The authors of another study [67] proposed a low-cost light detecting unit-based turbidity instrument for monitoring water cloudiness. The system makes use of an Intel Galileo 2 processor and a server for web-based tracking. The Turbidity Detection Unit is made up of a polyvinyl chloride (PVC) conduit, a Light Dependent Resistor (LDR), and a Light Emitting Diode (LED). The turbidity system is based on the idea that the amount of suspended matter and the amount of light it dissipates are directly correlated

Finally, the authors of a different study paper[68] propose an intelligent Internet of Things-based system for tracking water quality indicators. The device is designed to monitor four physical water quality parameters: temperature, pH, electric conductivity, and turbidity. Sensors, an Arduino microcontroller, an ESP8266 Wi-Fi module, and a cloud database for data storage and analysis make up the proposed system. The device operates by using sensors to collect data from the water sample and transmit it to the Arduino. Using the ESP Wi-Fi module, data is analyzed by the microcontroller and sent to a cloud database. In order to provide useful information on the water quality, the data is saved and examined in the cloud database. The recommended system is effective and economical and can be used to track metrics for water quality in real-time. The overall suggestion of the research paper is to put in place a smart water quality monitoring system that uses IoT to constantly track important water quality indicators. This technique can help reduce potential contamination exposure while ensuring the availability of clean potable water sources.

# SYSTEM ANALYSIS AND DESIGN

## 3.1 Introduction

This chapter provides a comprehensive review of the materials, tools, and designs utilized to complete the development of the portable incubator. It offers a detailed explanation of the project's programming, circuit design, and construction methods, including a discussion of the components chosen and the reasoning behind those choices. The chapter also showcases the project's flowchart and algorithm and includes information on the methodology and calculation employed during the building process.

## 3.2 Components

This project employs three categories of components: electrical, mechanical, and chemical. The electrical components encompass a Light Dependent Resistor (LDR), a DHT22 temperature and humidity sensor, a relay, an ESP32 microcontroller, an LED bulb, a 220-12V (AC-DC) power adapter, a buck converter, a Liquid Crystal Display (LCD), and a potentiometer. The mechanical components consist of the incubator and the beakers utilized for holding the water samples under investigation. The chemical component pertains to the substrate named water detect coliform.

### 3.2.1 ESP 32

The ESP 32 is an affordable microcontroller that has Wi-Fi and dual-mode Bluetooth built-in. It acts as both the microcontroller and Wi-Fi module, controlling the relay switch and interfacing with sensors. When connected to a Local Area Network (LAN), it enables real-time access to readings through the Blynk platform.

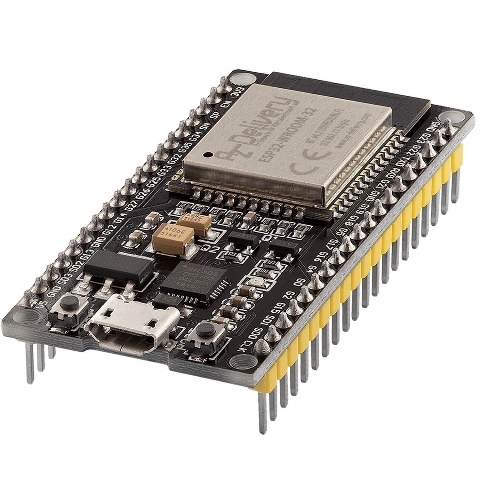
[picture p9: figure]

Figure 3.1: Expressif Systems Processor (ESP) 32

### 3.2.2 Light Dependent Resistor (LDR)

An LDR, also called a photo resistor, photocell, or photoconductor, is a type of sensor that responds to changes in light by altering its resistance. When light falls on an LDR, its resistance changes. The intensity of the light reaching the LDR is inversely proportional to its resistance. The LDR is used to determine the turbidity levels of the water sample being tested. Since the water sample is clear initially, more light reaches the LDR, causing a decrease in its resistance. However, if the water sample contains coliform bacteria, after approximately 16 hours of incubation, it turns blue. As a result, the LDR receives less light, causing an increase in its resistance value.

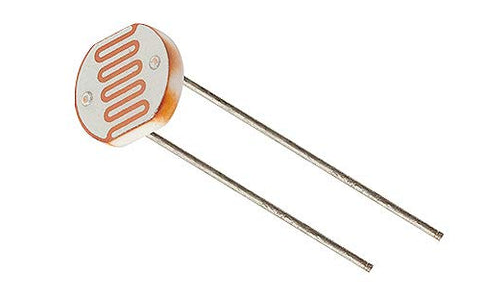
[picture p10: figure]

Figure 3.2: Light Dependent Resistor (LDR)

### 3.2.3 Relay

A relay is an electronic device that can be switched on or off when an external voltage (AC or DC) is applied across its control terminals. In this project, the relay is utilized to control the heating pad, which helps maintain the desired temperature range of 35-37℃ inside the incubator. The heating pad is connected to the relay, which is in turn connected to the ESP32. The ESP32 turns the relay on or off based on the temperature readings obtained from the DHT22 sensor, thereby regulating the temperature inside the incubator.

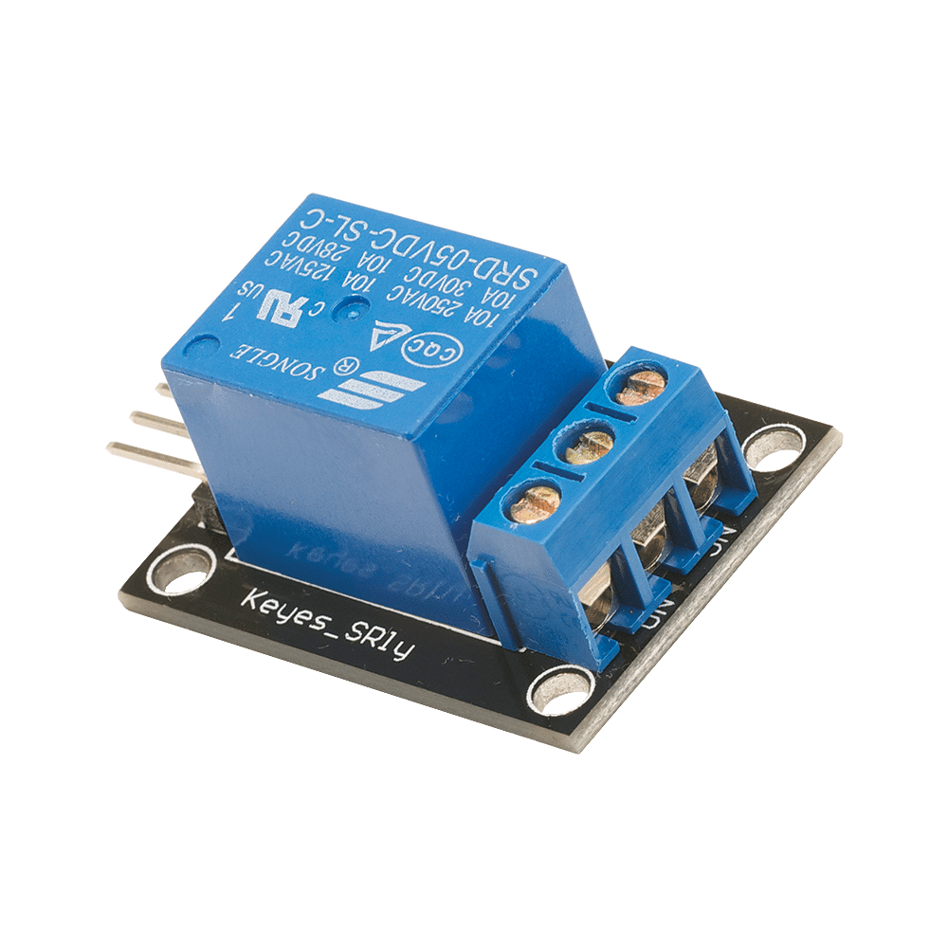
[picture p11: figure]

Figure 3.3: Relay

### 3.2.4. DC-DC Converter

A DC-DC converter is an electronic device that can increase or decrease the voltage of a direct current power source to match a desired voltage level. In this project, a 5V buck converter is used to step down the voltage from the 220V AC to 12V DC power adapter to the 5V level needed to power the various components of the system.

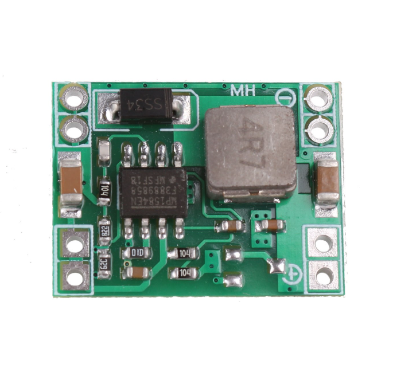
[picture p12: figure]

Figure 3.4: DC-DC Buck Converter

### 3.2.5 Electrical Heating Element

The incubator utilizes an electrical heating pad as its source of heat, which is controlled by the relay. The relay is triggered on and off by the microcontroller, depending on the temperature readings from the DHT22 sensor. The heating pad plays a crucial role in maintaining the temperature range required for the coliform bacteria's optimal growth in the water samples, which is between 35-37℃.

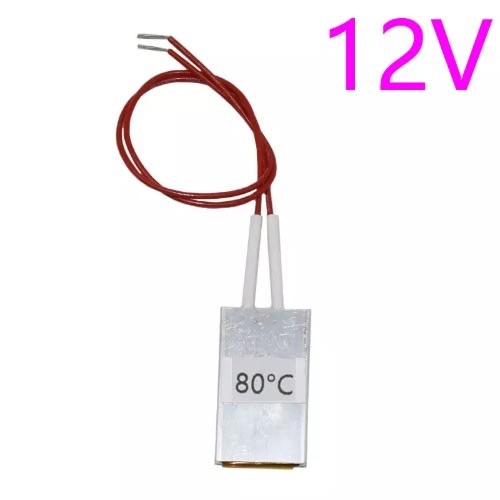
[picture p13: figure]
12V 80 Degrees Celsius PTC Heating Element.

Figure 3.5: Heating Source

### 3.2.6 LED Bulb

The LED bulb is used as the lighting source. It supplies the LDR with the sufficient light required to determine the turbidity levels of the water samples.

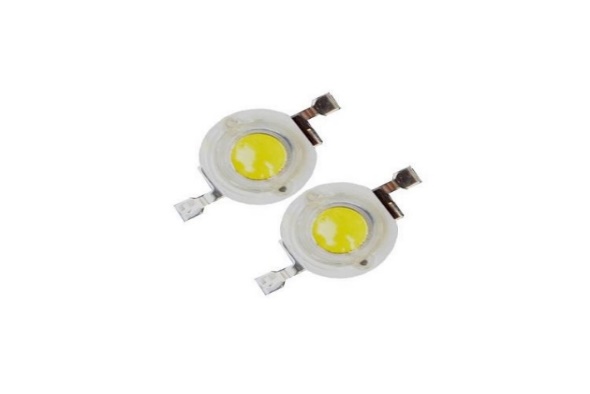
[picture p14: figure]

Figure 3.6: LED Bulb

### 3.2.7 Potentiometer

A potentiometer is a type of variable resistor that can manually adjust the flow of current in a circuit. In this project, a potentiometer is used to control the brightness of the LED bulb. This is important because if the bulb is too bright, it could cause the LDR to become saturated and produce a constant or maximum output voltage, making it difficult to distinguish between transparent water and water with moderate turbidity. By adjusting the brightness with the potentiometer, the LDR can accurately detect the turbidity levels in the water samples.

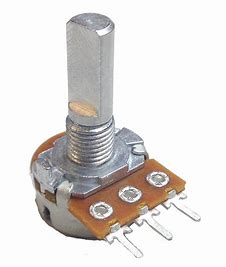
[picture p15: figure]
Image result for potentiometer

Figure 3.7: Potentiometer

### 3.2.8 DHT22 Temperature and Humidity Sensor

The DHT22 sensor is utilized to obtain data on the temperature and humidity levels within the incubator. Its significance lies in ensuring that the temperature remains within the 35-37℃ range. The ESP32 is connected to this sensor for interfacing purposes.

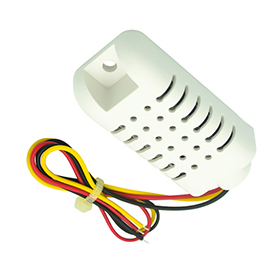
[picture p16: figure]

Figure 3.8: DHT 22

### 3.2.9 Liquid Crystal Display (LCD)

For this project, a 20x4 (20 characters, 4 rows) LCD display is utilized to provide a user-friendly interface for monitoring real-time data readings from various sensors. The LCD display effectively shows temperature and humidity levels within the incubator, as well as the resistance readings of the Light Dependent Resistors. It is interfaced with the ESP32 microcontroller to display the data readings on the screen. The real-time data presented on the LCD enables users to monitor the progress of the incubation process and ensure the optimal conditions necessary for the growth of coliform bacteria.

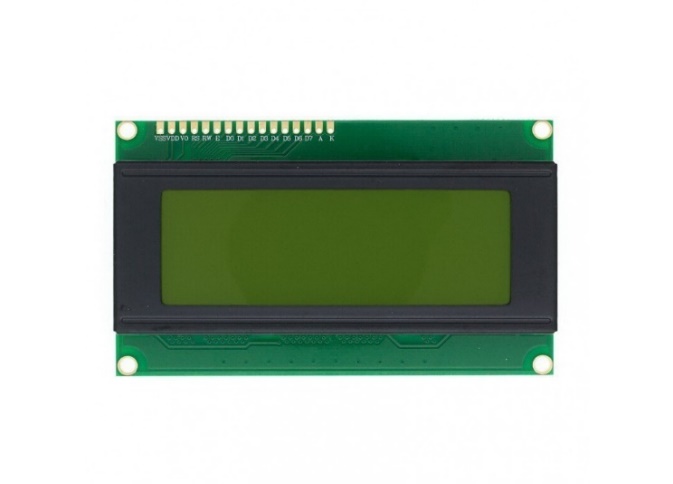
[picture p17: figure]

Figure 3.9: Liquid Crystal Display

### 3.2.10 I2C Serial Interface Adapter Module

The LCD 20x4 display used in this project is connected to the ESP32 microcontroller using I2C communication protocol. This allows for a simpler and more efficient data transfer between the microcontroller and the LCD display. The I2C interface reduces the number of pins required for communication, making it easier to interface with other components in the project.

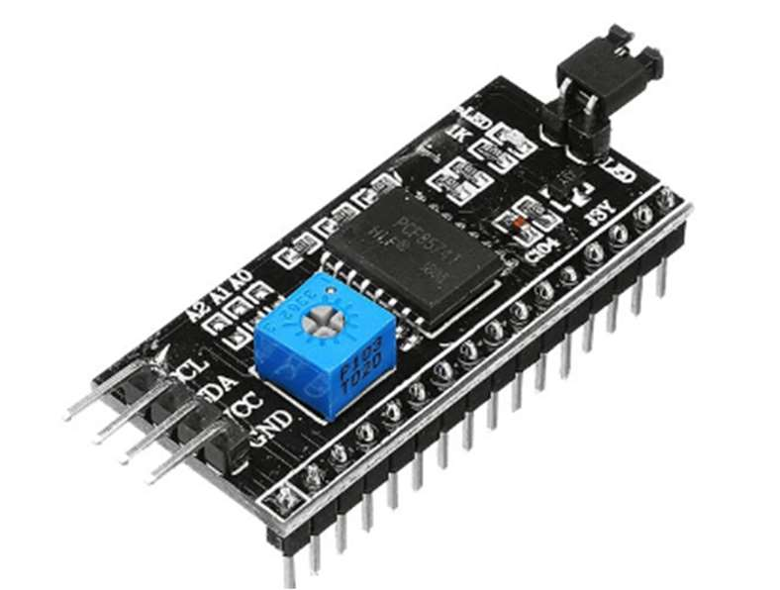
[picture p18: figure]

Figure 3.10: I2C Serial Interface Adapter Module

### 3.2.11 Incubator

The incubator is an essential tool in detecting Coliform bacteria in water samples. Its importance lies in its ability to provide a controlled environment that promotes the growth of Coliform bacteria, necessary for their detection. The incubator ensures accurate and reliable results by maintaining constant temperature and humidity conditions, reducing the risk of false negatives. Additionally, the use of an incubator provides a standardized procedure for Coliform detection in water, allowing for consistent comparison of results across various samples and testing centers. In summary, the incubator is a critical component in the detection of Coliform in water, offering a dependable and consistent method for bacteria growth and detection.

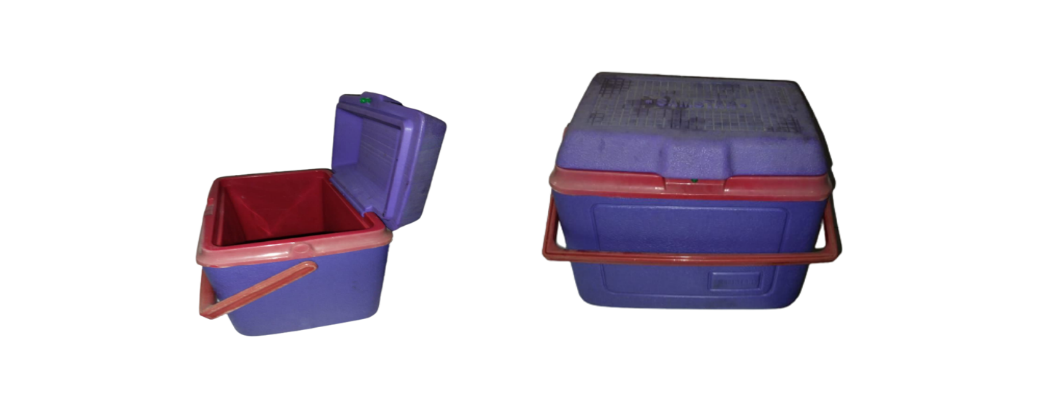
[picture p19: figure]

Figure 3.11: Incubator

### 3.2.12 Beaker

The beakers are utilized to contain the water samples for testing. They are transparent and enable light to pass through the water sample to the LDR. Additionally, they have markings that allow for accurate measurement of the volume of water being tested in milliliters (ml).

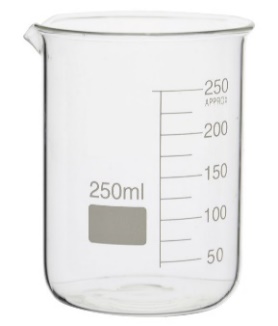
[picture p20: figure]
BFC Borosilicate Glass Beaker - 250ml: Buy Online at Best Price in ...

Figure 3.12: Beaker

### 3.2.13 Water Detect Coliform Powder

The chemical being used for detecting coliform bacteria in water samples is a crucial component of our project. It is the only substance capable of detecting the presence of coliforms, which generate acids and gases through β-galactosidase enzyme activity at their optimal growth temperature of 35-to-37-degree Celsius(°C). The chemical works by breaking down a chromogenic or fluorogenic substrate, resulting in the production of color or fluorescence. Specifically, the powder changes the color of water samples from a clear and transparent appearance to a dark greenish hue, indicating the presence of coliforms. This color change is important for our project as it allows the Light Detecting Resistors to detect a decrease in light intensity when the water changes color, which indicates the presence of coliforms in the sample.

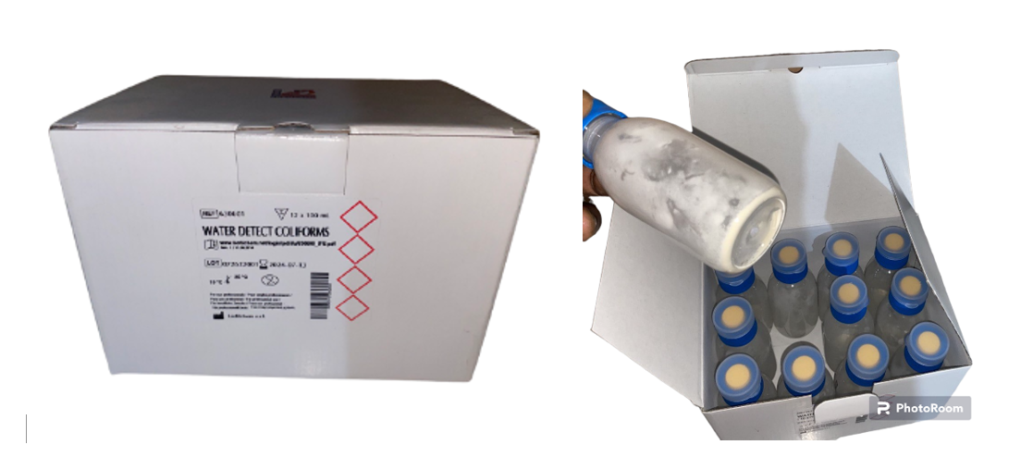
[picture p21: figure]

Figure 3.13: Water Detect Coliform Powder

### 3.2.14 Power Supply Adapter

The incubator's components are powered by a power supply adapter, which includes a rectifying circuit that converts a 220V AC power supply to a 12V DC power supply suitable for our components.

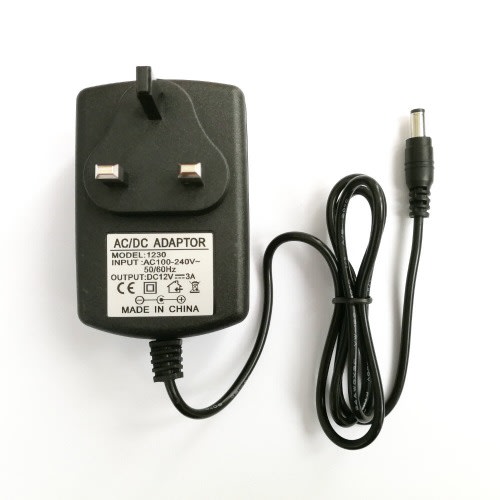
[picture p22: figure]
Power Supply Adapter - 220v Ac -12v Dc 3a.

Figure 3.14: Power Supply Adapter

## 3.3 Design specification

### 3.3.1 Systems Block Diagram

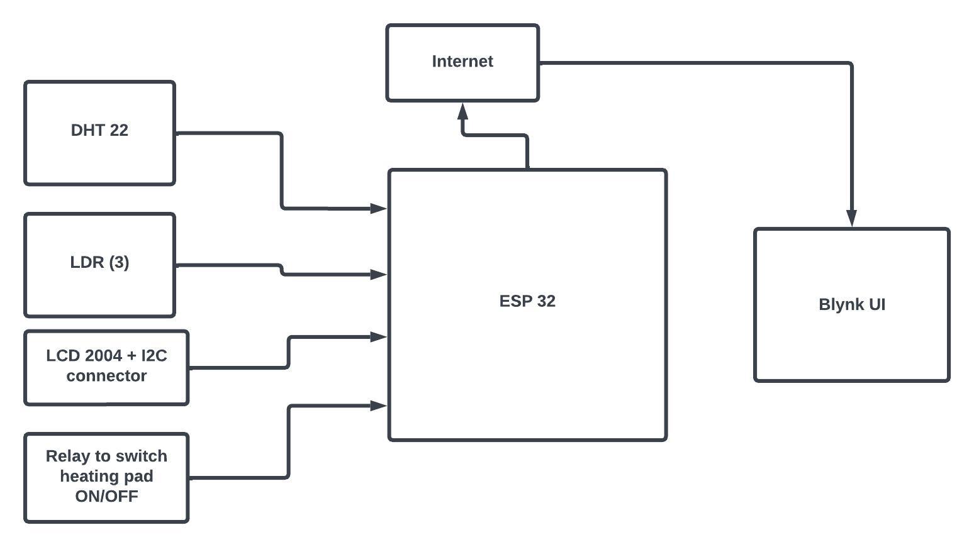
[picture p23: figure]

Figure 3.15: Systems Block Diagram

### 3.3.2 Circuit Diagram

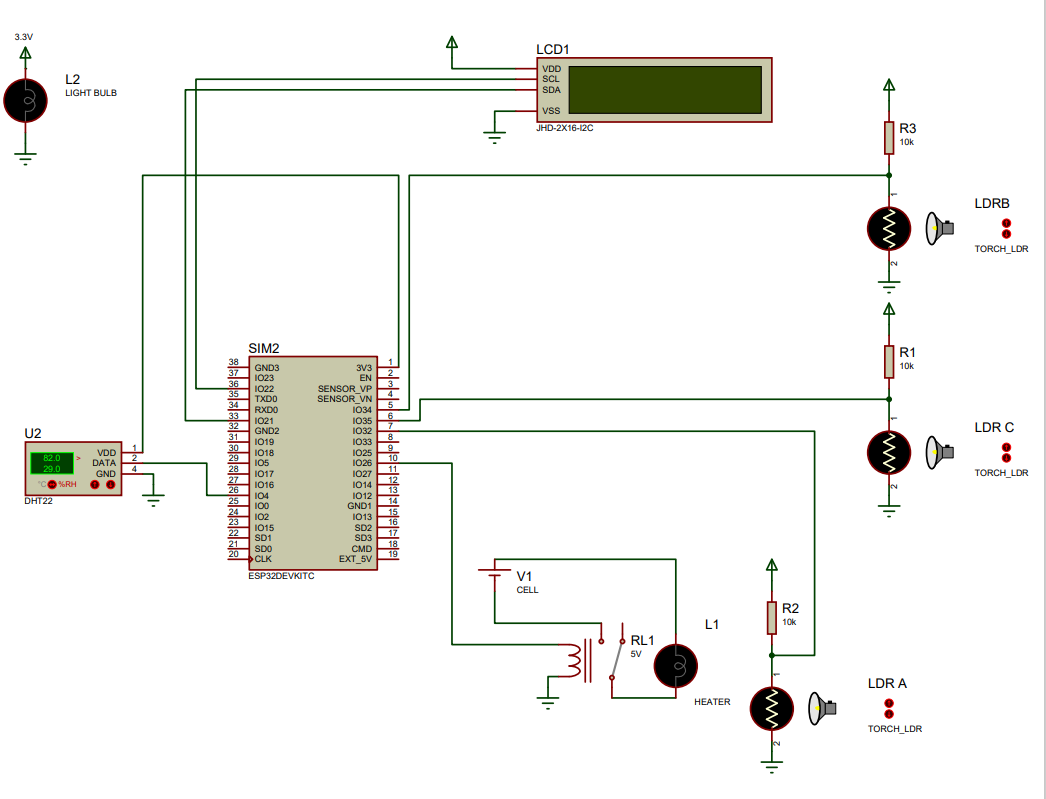
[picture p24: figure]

Figure 3.16: Circuit Diagram

### 3.3.3 Systems Flowchart

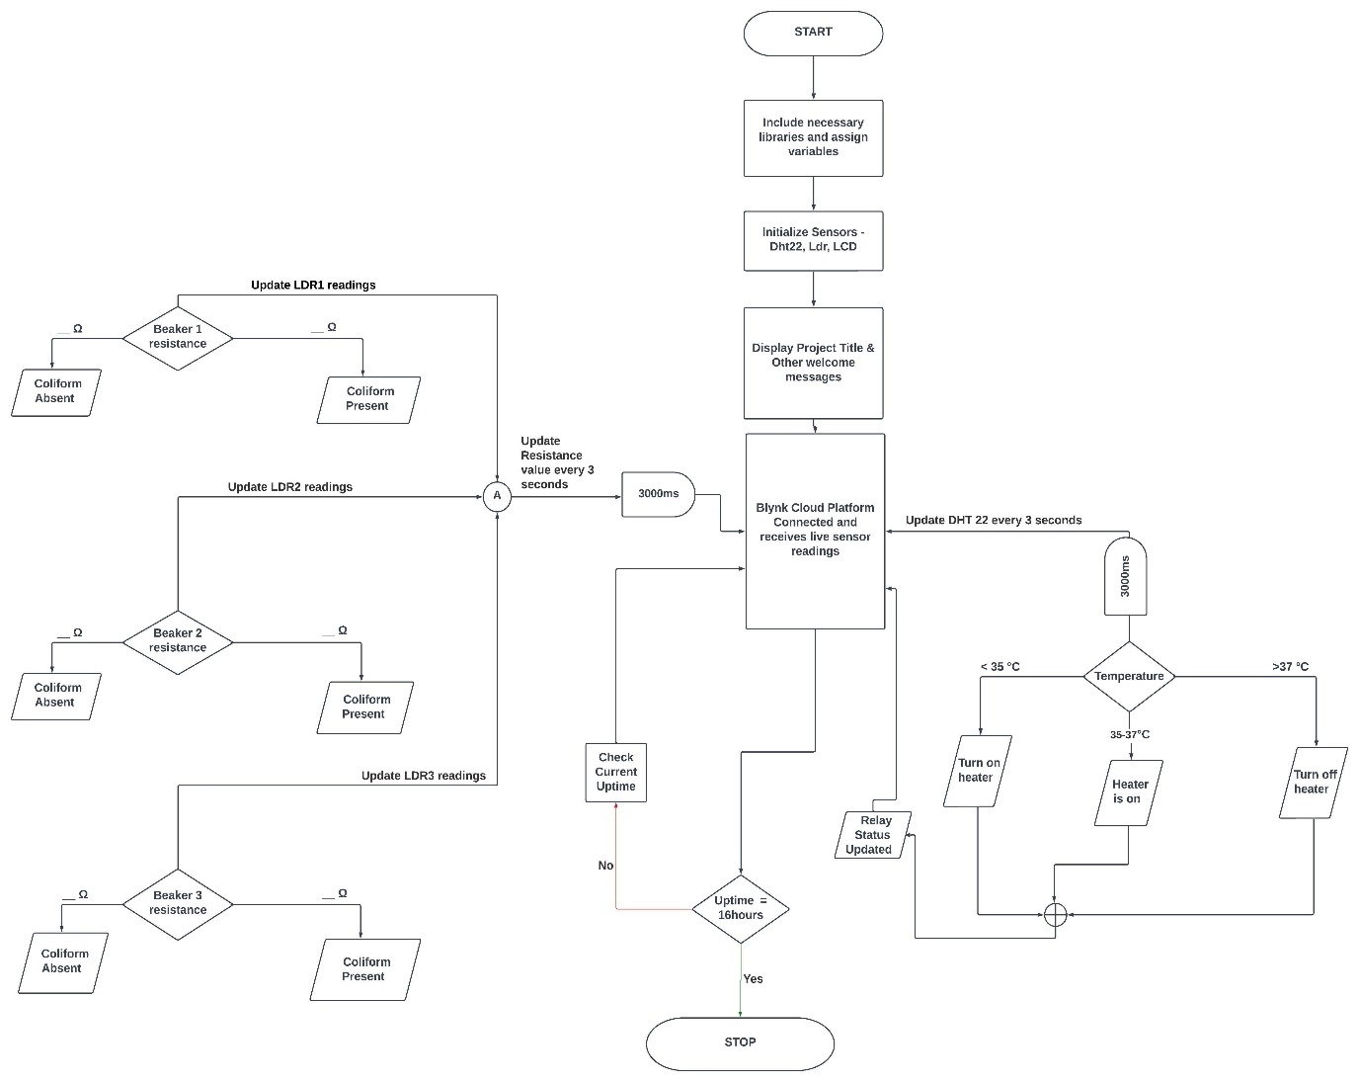
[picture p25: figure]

Figure 3.17: Systems Flowchart

### 3.3.4 Electrical Calculations

Heat transfer calculations

In order to determine the appropriate rating for the heating element required for the incubator, it is important to consider the amount of heat energy needed to raise the temperature of both the water and air inside the incubator to the desired level. Using the specific heat capacity formula,

Q = m x c x ∆θ 3.1

Where:

Q is the amount of energy (in joules)

m is the mass of water (in kilograms)

c is the specific heat capacity of water (in J/kg.k)

∆θ is the change in temperature (in kelvin, K)

There are three beakers in total, each containing 100ml of water, making a total of 300ml. Converting 300ml to mass gives:

Density = Mass/Volume

Mass = Density x Volume

Density of water = 1g/cm³ or 1g/ml, therefore, mass of water in incubator = 1g/ml x 300ml = 300g or 0.3kg

The specific heat capacity of water is approximately 4190J/kg.k Assuming the initial temperature of the water is room temperature 20°C (293k), and we want to raise it to 37°C (310k), ΔT would be 17kelvin. Therefore, the heat energy required to raise the temperature of 100ml of water is:

Q = 0.1 kg * 4190J/kg.k * 17k = 7.123kJ

Since there are three beakers, the total heat energy required to raise the temperature of all the water is:

Q_total = 3 x 7.123kJ = 21.369kJ

We also need to account for the heat energy required to raise the temperature of the air inside the incubator, in addition to that of the water. To calculate the amount of heat energy required to raise the temperature of a volume of air, the following equation can be used:

Q = m x cp x ∆θ

Where:

m = mass of air

cp = Specific heat capacity of air

∆θ = change in temperature

The incubator has internal dimensions of 270mm x 140mm x 200mm. Therefore, volume of incubator = Length x Breadth x Height = 0.27m x 0.14m x 0.2m = 0.00756m³. We need to raise the temperature inside the incubator from 20℃ (293k) to 35℃ (308k). ∆θ will be (308k – 293k = 15kelvin). The mass of air can be calculated using the density of air (approximately 1.28 kg/m³) and the volume of the incubator:

Density = Mass/Volume

Mass = Density x Volume

m = 1.28 kg/m³ * 0.00756m³ = 0.009677kg

The specific heat capacity of air is approximately 1005 J/kg·K. Therefore, the heat energy required to raise the temperature of the air inside the incubator is:

Q = 0.009677kg * 1005 J/kg·K * 15 = 145.88J

The total heat energy required to raise the temperature of the water and air inside the incubator is:

Qtotal = 21.369kJ + 145.88J = 21.514kJ

To calculate the power rating required for the PTC heating element, we also need to consider the time it takes to raise the temperature. Let's assume we want to raise the temperature in 20 minutes or 1200 seconds. Therefore, the power rating required for the PTC heating element is gotten by using the formula Q = pt

P = Qtotal / t = 21.514kJ / 1200 = 17.9 watts appx 18 watts

Hence, a PTC element rated for about 18watts will be sufficient to raise the ambient temperature in the incubator to 35-37℃ in 20 minutes. A lower rating heating element could alternatively be used, as the polystyrene foam used to pad the walls of the incubator will enhance insulation.

COMPONENT | VOLTAGE RATING | CURRENT DRAW
Espressif Systems Processor (ESP) 32 | 5v | 240mA
Relay | 5v | 160mA
Liquid Crystal Display (LCD) | 4.5v-5.5v | 120mA
Heating Element | 12v | 1670mA
LED Bulb | 3.4v | 350mA

## 3.4 Description of Software Requirements

The programming of the entire system will be done using the Arduino C/C++ language on the Arduino Integrated Development Environment (IDE), followed by compilation and uploading to the microcontroller. The software required for this project is outlined below.

### 3.4.1 Arduino Integrated Development Environment (IDE)

The Arduino Integrated Development Environment (IDE), an open-source software, simplifies programming and uploading of code to the microcontroller board. It is compatible with various operating systems including Windows, Mac Operating System X, and Linux. The user interface was developed using Java and free and open-source tools like Lua Processing. Our project's Arduino board programming is written in C++, and the IDE software translates our readable human program codes into machine language. Before uploading to the microcontroller board, the IDE checks the source code for errors to ensure proper functionality.

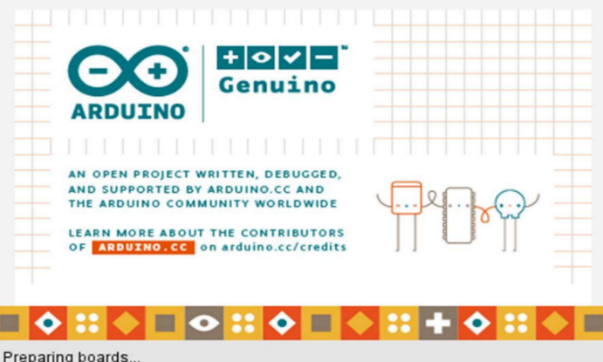
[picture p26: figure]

Figure 3.18: Arduino Integrated Development Environment (IDE)

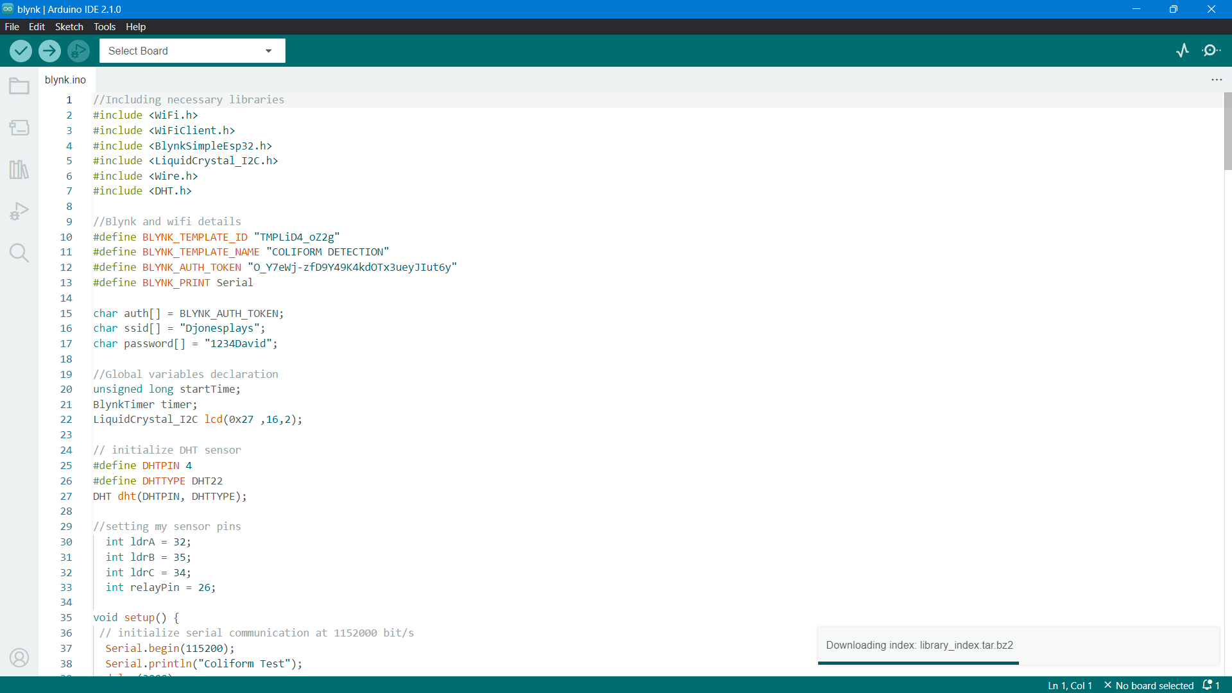
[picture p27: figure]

Figure 3.19: Arduino Integrated Development Environment (IDE) Code Snippet

### 3.4.2 Blynk

Blynk is a versatile platform that enables users to create mobile applications that control and monitor devices over the internet. One of the key advantages of Blynk is its user-friendly interface, which makes it easy for users to monitor and control various IoT devices from their smartphones. In this particular project, Blynk plays a critical role in facilitating remote monitoring of the incubator's temperature and water quality parameters using a mobile device.

By integrating the ESP 32 with the Blynk platform, users can remotely monitor the temperature of the incubator and the water quality parameters in real-time. Blynk also allows users to set up alerts and notifications that can be sent to their smartphones if the temperature or water quality parameters fall outside the acceptable range. This feature ensures that users can respond quickly to any deviations from ideal conditions and prevent damage to the organisms being cultured in the incubator.

In summary, Blynk's user-friendly and convenient interface makes it an ideal platform for remotely monitoring and controlling the incubator's temperature and water quality parameters. By using Blynk in conjunction with the ESP 32, users can ensure that optimal conditions are maintained for the organisms being cultured in the incubator.

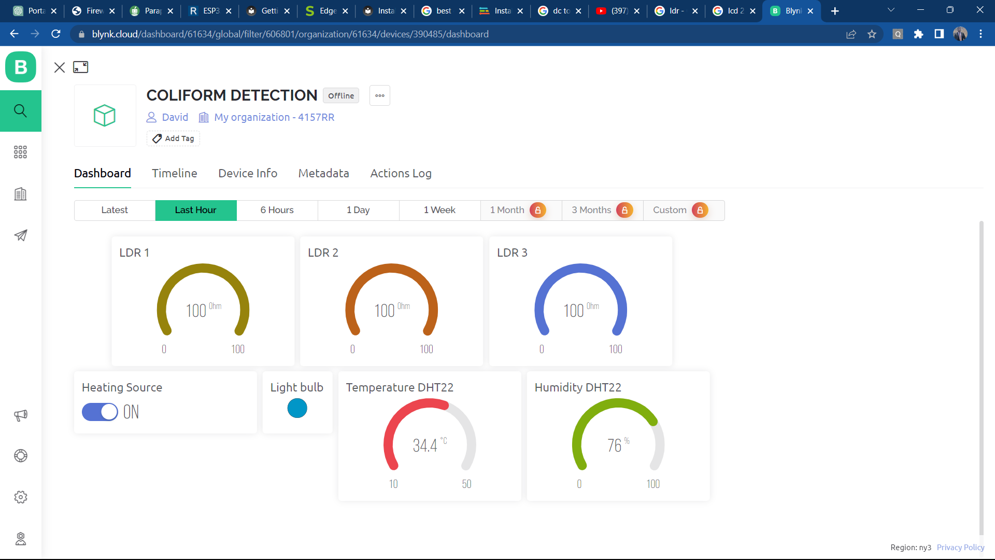
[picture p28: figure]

Figure 3.20: Blynk Application

## 3.5 Conclusion

This chapter provides a comprehensive overview of the construction process of this project. It explains in detail the different components utilized, the circuitry, block diagrams, algorithms, and flowcharts employed. Moreover, it describes the architecture and techniques of the system, giving practical examples. The chapter also outlines the implementation procedures, including the proposed model and the development approach to be followed.

# RESULTS AND DISCUSSIONS

## 4.1

# CONCLUSION

## 5.1

# REFERENCES

[1] A. Sarker, S. Dash, M. M. Hoque, S. Ahmed, and M. R. Shaheb, “Assessment of microbial quality of water in popular restaurants in Sylhet city of Bangladesh,” Bangladesh Journal of Agricultural Research, vol. 41, no. 1, pp. 115–125, 2016, doi: 10.3329/bjar.v41i1.27677.

[2] A. Schertenleib, J. Sigrist, M. N. D. Friedrich, C. Ebi, F. Hammes, and S. J. Marks, “Construction of a low-cost mobile incubator for field and laboratory use,” JoVE (Journal of Visualized Experiments), no. 145, p. e58443, 2019.

[3] “Coliform Bacteria and Drinking Water,” no. April, 2011.

[4] P. Pal, “Detection of Coliforms in Drinking Water and its Effect on Human Health - A Review,” International Letters of Natural Sciences, vol. 17, pp. 122–131, 2014, doi: 10.18052/www.scipress.com/ilns.17.122.

[5] L. K. Bhardwaj and T. Jindal, “Evaluation of Coliform and Faecal Coliform Bacteria in the Lakes of Broknes and Grovnes Peninsula, East Antarctica,” Nature Environment and Pollution Technology, vol. 21, no. 5, pp. 2025–2034, 2022, doi: 10.46488/NEPT.2022.v21i05.002.

[6] P. Taylor, M. V Yates, S. R. Yates, and C. P. Gerba, “Critical Reviews in Environmental Control Modeling microbial fate in the subsurface environment,” no. March 2015, pp. 37–41, doi: 10.1080/10643388809388339.

[7] L. Niyoyitungiye, A. Giri, and M. Ndayisenga, “Assessment of Coliforms Bacteria Contamination in Lake Tanganyika as Bioindicators of Recreational and Drinking Water Quality,” South Asian Journal of Research in Microbiology, no. June, pp. 9–16, 2020, doi: 10.9734/sajrm/2020/v6i330150.

[8] F. M. Khan and R. Gupta, “Escherichia coli (e. coli) as an indicator of fecal contamination in groundwater: A review,” Environmental Science and Engineering, no. October, pp. 225–235, 2020, doi: 10.1007/978-3-030-45263-6_21.

[9] M. V. Yates and S. R. Yates, “Modeling microbial fate in the subsurface environment,” Critical Reviews in Environmental Control, vol. 17, no. 4, pp. 307–344, 1988, doi: 10.1080/10643388809388339.

[10] “EFFECT OF SEPTIC TANKS CONTAMINATION ON GROUNDWATER QUALITY AROUND ELEMENTARY SCHOOL IN IBADAN , OYO STATE NIGERIA,” no. March, 2023.

[11] S. Rafael, G. Lenn, and F. Yekeh, “Impact Of Constructing Septic Tanks in Close Proximity to Boreholes ( Ground Water ): The Case Of Kesselly Boulevard Community in Montserrado County , Original Research Paper Health Science IMPACT OF CONSTRUCTING SEPTIC TANKS IN CLOSE PROXIMITY TO,” no. June, 2021.

[12] V. O. Adetunji and I. A. Odetokun, “Groundwater contamination in Agbowo community , Ibadan Nigeria : Impact of septic tanks distances to wells,” vol. 7, no. 3, pp. 159–166, 2011.

[13] C. Y. Lin, M. H. Abdullah, B. Musta, A. Z. Aris, and S. M. Praveena, “Assessment of selected chemical and microbial parameters in groundwater of Pulau Tiga, Sabah, Malaysia,” Sains Malays, vol. 39, no. 3, pp. 337–345, 2010.

[14] “Guidelines for Canadian Drinking Water Quality: Guideline Technical Document – Enteric Viruses - Canada.ca.” https://www.canada.ca/en/health-canada/services/publications/healthy-living/guidelines-canadian-drinking-water-quality-guideline-technical-document-enteric-viruses.h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 (accessed Mar. 30, 2023).

[15] E. O. Longe and M. R. Balogun, “Groundwater quality assessment near a municipal landfill, Lagos, Nigeria,” Research Journal of Applied Sciences, Engineering and Technology, vol. 2, no. 1, pp. 39–44, 2010.

[16] K. Yusuf, “Groung Water in Lagos.Pdf.” [Online]. Available: http://www.docsdrive.com/pdfs/ansinet/jas/2007/1780-1784.pdf

[17] E. O. Orebiyi, J. A. Awomeso, O. A. Idowu, O. Martins, O. Oguntoke, and A. M. Taiwo, “Assessment of pollution hazards of shallow well water in Abeokuta and environs, southwest, Nigeria,” Am J Environ Sci, vol. 6, no. 1, pp. 50–56, 2010, doi: 10.3844/ajessp.2010.50.56.

[18] U. A. P. & Dr. O. a A. A, “Exploratory Survey of Geochemical Aspects of Underground Water in Ehime Mbano Area Se Nigeria,” Global Journals of Research in Engineering, 11(4), vol. 11, no. 4, pp. 15–22, 2011.

[19] H. M. Solo-gabriele, M. A. Wolfert, T. R. Desmarais, and C. J. Palmer, “Sources of Escherichia coli in a Coastal Subtropical Environment,” vol. 66, no. 1, pp. 230–237, 2000.

[20] P. Harcourt, “The Effect of Septic Tank Locations on Borehole Water Quality in,” vol. 4, no. 5, 2014.

[21] “Management Plan to Reduce the Adverse Effects of Proximity of Dug Wells and Septic Tanks in Urban Area to Diminish Coliform Contamination,” vol. 7, no. 3, 2016.

[22] R. J. Perkins, “Septic tanks, lot size and pollution of water table aquifers,” J Environ Health, vol. 46, no. 6, pp. 298–304, 1984.

[23] M. V. Yates and S. R. Yates, “Septic Tank Setback Distances: A Way to Minimize Virus Contamination of Drinking Water,” Groundwater, vol. 27, no. 2. pp. 202–208, 1989. doi: 10.1111/j.1745-6584.1989.tb00441.x.

[24] “Environmental Impacts of Agricultural Modifications.” https://education.nationalgeographic.org/resource/environmental-impacts-agricultural-modifications/ (accessed Mar. 30, 2023).

[25] J. A. Entry and N. Farmer, “Movement of Coliform Bacteria and Nutrients in Ground Water Flowing through Basalt and Sand Aquifers,” J Environ Qual, vol. 30, no. 5, pp. 1533–1539, 2001, doi: 10.2134/jeq2001.3051533x.

[26] N. Sasakova et al., “Pollution of Surface and Ground Water by Sources Related to Agricultural Activities,” vol. 2, no. July, 2018, doi: 10.3389/fsufs.2018.00042.

[27] “Agricultural Contaminants | U.S. Geological Survey.” https://www.usgs.gov/mission-areas/water-resources/science/agricultural-contaminants (accessed Mar. 30, 2023).

[28] “Poor Farming Practices & How They Affect Your Food – Thriving Yard.” https://thrivingyard.com/poor-farming-practices-how-they-affect-your-food/ (accessed Mar. 30, 2023).

[29] P. K. Weiskel, B. L. Howes, and G. R. Heufelder, “Coliform Contamination of a Coastal Embayment: Sources and Transport Pathways,” Environ Sci Technol, vol. 30, no. 6, pp. 1872–1881, 1996, doi: 10.1021/ES950466V.

[30] A. O. Sojobi, “Evaluation of groundwater quality in a rural community in North Central of Nigeria,” Environ Monit Assess, vol. 188, no. 3, pp. 1–17, Mar. 2016, doi: 10.1007/S10661-016-5149-Y.

[31] P. Rajapaksha, A. Elbourne, S. Gangadoo, R. Brown, D. Cozzolino, and J. Chapman, “A review of methods for the detection of pathogenic microorganisms,” Analyst, vol. 144, no. 2, pp. 396–411, Jan. 2019, doi: 10.1039/C8AN01488D.

[32] S. N. Zulkifli, H. A. Rahim, and W.-J. Lau, “Detection of contaminants in water supply: A review on state-of-the-art monitoring technologies and their applications,” Sens Actuators B Chem, vol. 255, pp. 2657–2689, 2018.

[33] A. Verma, “Environmental Ethics : Need to Rethink Environmental Ethics : Need to Rethink,” no. July, pp. 1–4, 2020.

[34] M. Pal, Y. Ayele, A. Hadush, S. Panigrahi, and V. J. Jadhav, “Air & Water Borne Diseases Public Health Hazards Due to Unsafe Drinking Water,” vol. 7, no. 1, pp. 1–6, 2018, doi: 10.4172/2167-7719.1000138.

[35] P. Martins, N. O. Forstinus, and N. E. Ikechukwu, “Water and Waterborne Diseases : A Review Water and Waterborne Diseases : A Review,” no. January, 2016, doi: 10.9734/IJTDH/2016/21895.

[36] M. N. Iqbal and A. Ashraf, “Water Quality a Priority for Profitable Fish Farming,” PSM Biological Research, vol. 5, no. 2, pp. 92–94, 2020.

[37] A. S. Yusuff, W. John, and A. C. Oloruntoba, “Review on prevalence of waterborne diseases in Nigeria,” J Adv Med Life Sci, vol. 1, no. 2, pp. 1–3, 2014.

[38] “Drinking-water.” https://www.who.int/en/news-room/fact-sheets/detail/drinking-water (accessed Mar. 31, 2023).

[39] A. D. Lopez and C. D. Mathers, “Measuring the global burden of disease and epidemiological transitions: 2002–2030,” Ann Trop Med Parasitol, vol. 100, no. 5–6, pp. 481–499, 2006.

[40] W. J. W. Supply and S. M. Programme, Progress on drinking water and sanitation: 2014 update. World Health Organization, 2014.

[41] K. Khan et al., “Prevalent fecal contamination in drinking water resources and potential health risks in Swat, Pakistan,” Journal of Environmental Sciences, pp. 1–12, 2017, doi: 10.1016/j.jes.2017.12.008.

[42] M. J. Allen, S. C. Edberg, J. L. Clancy, and S. E. Hrudey, “Drinking water microbial myths,” Crit Rev Microbiol, vol. 41, no. 3, pp. 366–373, 2015.

[43] R. Bain, R. Johnston, and T. Slaymaker, “Drinking water quality and the SDGs,” NPJ Clean Water, vol. 3, no. 1, pp. 7–9, 2020, doi: 10.1038/s41545-020-00085-z.

[44] P. Servais, J. Baudart, and A. Rompre, “Detection and enumeration of coliforms in drinking water : current methods and emerging approaches,” vol. 49, pp. 31–54, 2002.

[45] K. Gilbride, Molecular Methods for the Detection of Waterborne Pathogens. Elsevier, 2013. doi: 10.1016/B978-0-444-59543-0.00008-6.

[46] “Polymerase chain reaction - Wikipedia.” https://en.wikipedia.org/wiki/Polymerase_chain_reaction (accessed Mar. 31, 2023).

[47] “Detection of coliform bacteria in water by polymerase chain reaction and gene probes | Applied and Environmental Microbiology.” https://journals.asm.org/doi/full/10.1128/aem.56.2.307-314.1990 (accessed Mar. 31, 2023).

[48] S. F. Hussin and Z. Saari, “The Portable Incubator For E. coli and Coliform Bacterial Growth Using IoT,” Advances in Computing and Intelligent System, vol. 2, no. 1, 2020.

[49] M. Principle, T. Procedure, I. Results, and S. Life, “Water Detect Coliforms,” pp. 2–4, 2016.

[50] “Coliform bacteria - Wikipedia.” https://en.wikipedia.org/wiki/Coliform_bacteria (accessed Mar. 31, 2023).

[51] “The Internet of Things (IoT): An Overview - Internet Society.” https://www.internetsociety.org/resources/doc/2015/iot-overview/ (accessed Mar. 30, 2023).

[52] P. M. Pujar, H. H. Kenchannavar, R. M. Kulkarni, and U. P. Kulkarni, “Real - time water quality monitoring through Internet of Things and ANOVA - based analysis : a case study on river Krishna,” Appl Water Sci, 2020, doi: 10.1007/s13201-019-1111-9.

[53] “What is IoT (Internet of Things)? | Microsoft Azure.” https://azure.microsoft.com/en-us/resources/cloud-computing-dictionary/what-is-iot/ (accessed Mar. 30, 2023).

[54] M. J. Mudumbe and A. M. Abu-Mahfouz, “Smart water meter system for user-centric consumption measurement,” in 2015 IEEE 13th international conference on industrial informatics (INDIN), IEEE, 2015, pp. 993–998.

[55] K. Upadhyay, A. K. Yadav, and P. Gandhi, “A review of internet of things from Indian perspective,” Engineering Vibration, Communication and Information Processing: ICoEVCI 2018, India, pp. 621–632, 2019.

[56] R. Krishnamurthi, A. Kumar, D. Gopinathan, A. Nayyar, and B. Qureshi, “An overview of IoT sensor data processing, fusion, and analysis techniques,” Sensors, vol. 20, no. 21, p. 6076, 2020.

[57] S. Sanyal and P. Zhang, “Improving quality of data: IoT data aggregation using device to device communications,” IEEE Access, vol. 6, pp. 67830–67840, 2018.

[58] S. A. H. Almetwally, M. K. Hassan, and M. H. Mourad, “Real Time Internet of Things (IoT) Based Water Quality Management System,” Procedia CIRP, vol. 91, pp. 478–485, 2020, doi: 10.1016/j.procir.2020.03.107.

[59] M. Singh and S. Ahmed, “IoT based smart water management systems: A systematic review,” Mater Today Proc, vol. 46, pp. 5211–5218, 2021.

[60] “Data Analysis and Visualization in an IOT Dashboard.” https://psiborg.in/data-analysis-and-visualization-in-an-iot-dashboard/ (accessed Mar. 31, 2023).

[61] H. Khurshid et al., “Bacterial prediction using internet of things (IoT) and machine learning,” Environ Monit Assess, vol. 194, no. 2, p. 133, 2022.

[62] U. Ahmed, R. Mumtaz, H. Anwar, S. Mumtaz, and A. M. Qamar, “Water quality monitoring: from conventional to emerging technologies,” Water Supply, vol. 20, no. 1, pp. 28–45, 2020.

[63] F. Jan, N. Min-Allah, and D. Düştegör, “Iot based smart water quality monitoring: Recent techniques, trends and challenges for domestic applications,” Water (Basel), vol. 13, no. 13, p. 1729, 2021.

[64] N. S. Kamaruidzaman and S. N. Rahmat, “Water monitoring system embedded with internet of things (IoT) device: a review,” in IOP conference series: Earth and environmental science, IoP Publishing, 2020, p. 12068.

[65] B. T. Heligman et al., “The design and usage of a portable incubator for inexpensive in-field water analysis,” Journal of Humanitarian Engineering, vol. 6, no. 2, 2018.

[66] A. Schertenleib, J. Sigrist, M. N. D. Friedrich, C. Ebi, F. Hammes, and S. J. Marks, “Construction of a Low-cost Mobile Incubator for Field and Laboratory Use Construction of a Low-cost Mobile Incubator for Field and Laboratory Use,” no. March, 2019, doi: 10.3791/58443.

[67] S. N. Ibrahim, A. L. Asnawi, N. Abdul Malik, N. F. Mohd Azmin, A. Z. Jusoh, and F. N. Mohd Isa, “Web based Water Turbidity Monitoring and Automated Filtration System: IoT Application in Water Management.,” International Journal of Electrical & Computer Engineering (2088-8708), vol. 8, no. 4, 2018.

[68] S. Manoharan, G. Sathiyaraj, K. Thiruvenkadakrishnan, G. V Vetriselvan, and P. Kishor, “Water quality analyzer using IoT,” Int. J. Innov. Technol. Explor. Eng, vol. 8, pp. 34–37, 2019.

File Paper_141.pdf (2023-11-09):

The 2nd International Conference on Multidisciplinary Engineering and Applied Sciences (ICMEAS-2023)

979-8-3503-5883-4/23/$31.00 ©2023 IEEE

# Development Of A Portable Incubator For The Detection Of Coliform In Water Using Iot

Olonisakin David Akolade, Oguibe Favour Oziomachuwku, Omoruyi Osemwegie Department of Electrical and Information Engineering Covenant University,
Ota, Ogun State, Nigeria.
olonisakin.david@stu.cu.edu.ng oguibe.favour@stu.cu.edu.ng osemwegie.omoruyi@covenantuniversity.edu.ng

Abstract—Ensuring clean and safe drinking water is a fundamental human right, yet many lack access, leading to waterborne diseases that claim lives globally. This project aims to create an affordable, portable coliform bacteria detection incubator. It employs a light-dependent resistor (LDR) and an IoT-enabled microcontroller (ESP32) to maintain ideal conditions for incubation. The system uses a Digital Humidity and Temperature (DHT11) sensor and heating element to sustain a 35-37°C temperature range, optimal for coliform bacteria growth. An integrated Liquid Crystal Display (LCD) records resistance and temperature data.
Collected | information | is | transferred | to | the
microcontroller and streamed to the Blynk app for real-time monitoring. This innovation's portability and costeffectiveness make it suitable for remote regions with limited access to laboratory equipment. Significantly, it holds promise for advancing low-cost, portable water quality monitoring systems, potentially enhancing public health.

Keywords— portable incubator, coliform bacteria , water monitoring, light-dependent resistor, public health

I. INTRODUCTION
The research was inspired by the need for precise and trustworthy techniques for identifying waterborne infections, especially coliform bacteria, in places with few laboratory facilities. Coliform bacteria are used as a quality gauge for water and are a sign that potentially dangerous diseases may be present[1]. Ensuring the availability of safe drinking water stands as a key priority in public health efforts because it is intimately related to human health. Consuming water that contains hazardous chemicals or pathogenic organisms has a major influence on one's health[2].
The lack of low-cost, simple-to-use, and accurate techniques for remote water monitoring and coliform detection is the key issue driving this research. Due to difficulties with transportation, sample storage, and inadequate laboratory facilities, traditional laboratory-based approaches are frequently not practical in remote places. Thus, the creation of a mobile incubator for coliform detection could be the answer to this issue.
The project is aimed towards developing a portable incubator that can quickly and accurately detect coliform bacteria in water using an approach that is both affordable and simple to use. One approach to detect these organisms involves filtering a 100 mL water sample through a membrane. Subsequently, the filtered membrane is incubated on specialized media at temperatures ranging from 35 to 37 °C for E. coli or 44 to 45 °C for TTC[3]. The issue of restricted access to laboratory facilities for water monitoring and coliform detection can be resolved by the portable incubator, especially in distant locations. The study is important because it may increase access to clean water, especially in locations where waterborne diseases are common. The mobile incubator might also be used for environmental research and monitoring, which would improve water management and public health.

II. OVERVIEW OF EXISTING WATER QUALITY DETECTION METHODS
Diverse techniques for identifying waterborne contaminants have been developed and put to use in the effort to guarantee safe and clean drinking water. The merits and demerits of water quality detection technologies are highlighted in this chapter. This chapter lays the stage for the proposed construction of a portable incubator for the detection of coliform bacteria in water using IoT technology by addressing the drawbacks of present methods. The following are the existing water quality detection approaches:
a. Culture-Based Methods: To detect coliform bacteria and other microbes using traditional methods, water samples are cultured on specific media. These procedures deliver precise findings, but they frequently call for specialized facilities, knowledgeable staff, and protracted incubation times. Additionally, the requirement for sterile conditions may restrict their applicability in places with limited resources.
b. Membrane Filter Method: This technique entails passing a water specimen through a sterilized, bacteria-retaining 0.45-millimeter pore filter. Typical colonies on the filter are then counted after the filter has been cultured on a selective medium. Although this approach is more sensitive than direct culture, it still requires lengthy incubation times and poses a danger of cross-contamination[4]
c. Enzymatic Method: Coliforms possess the enzyme -galactosidase, which produces acids and gases at their optimum growth temperatures of 35 to 37 degrees Celsius (°C). Color or fluorescence is produced when a certain enzyme breaks down a chromogenic or fluorogenic substrate. These chemicals have been utilized to identify the presence or activity of specific enzymes in water. While it offers quicker results, it may lack specificity and sensitivity for certain strains[5].
d. Polymerase Chain Reaction Method (PCR): PCRbased techniques are used to rapidly detect DNA sequences specific to coliform bacteria. However, they require sophisticated equipment, skilled operators, and are generally better suited for centralized laboratories[6].

The prevalent traditional methods now in use have a significant flaw in terms of their time-intensive nature. This inherent trait frequently causes extended incubation periods, which slows the prompt dissemination of results. A further obstacle to conducting and gaining access to water quality evaluations is the urgent need for individuals with specialized training and well-equipped specialist laboratories. This situation is made worse in rural or underdeveloped areas where the lack of such resources presents a serious obstacle[7]. Equally important is the significant obstacle created by the construction and maintenance of centralized laboratories. Particularly for towns endowed with little economic resources, the cost burden associated with acquiring the necessary equipment and maintaining the infrastructure required for thorough water quality investigation can be extremely onerous. The implementation of a thorough water quality examination consequently becomes a challenging task. It becomes clear that a paradigm shift towards more effective, accessible, and affordable approaches for monitoring water quality is essential in light of these numerous limitations. Such a change will not only hasten the release of important findings but also democratize access to precise water quality evaluation across various geographic and economic contexts.
Proposed Solution: Portable Incubator for Coliform Detection
This project seeks to create a portable incubator outfitted with IoT technology for the quick and accurate identification of coliform bacteria in water, drawing inspiration from the difficulties seen in current methods for determining the quality of the water. The proposed incubator aims to overcome the limitations of conventional methods by utilizing IoT's capabilities
a. Real-time monitoring: The use of IoT allows for remote data transfer and continuous monitoring, which minimizes response times and the requirement for physical presence[8].
b. Field Applicability: Traditional techniques for assessing water quality are typically only
performed in laboratories. With this portable incubator, testing for the presence of Coliform bacteria may be done anywhere and is not limited to a laboratory[9].
c. User-Friendly: The design intends to streamline usage, enabling testing at the community level and accessibility to non-specialist users.
d. Cost-Effective: The suggested incubator aims to provide a more affordable option for monitoring water quality by avoiding the need for costly laboratory facilities[10].

III. SYSTEM DESIGN AND METHODOLOGY
The design was done with an ESP 32 microcontroller for data transmission of the sensor reading: LDR, DHT11, PTC heater controlled by a relay to BLYNK for visualization and a 12v Dc Power supply unit to power the incubator. The system is fully covered as shown in Figure 1:

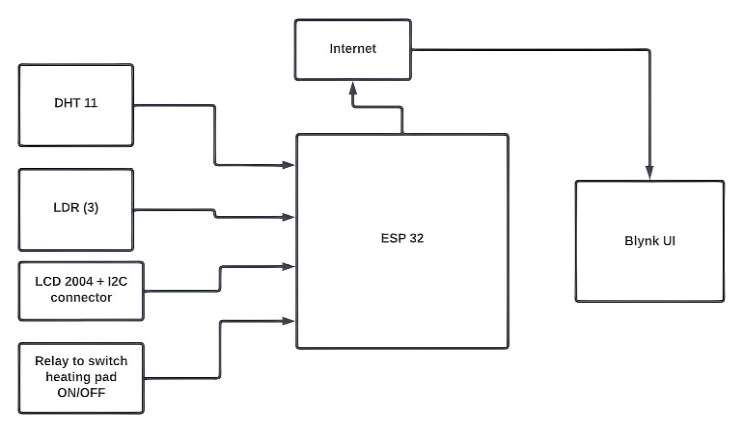
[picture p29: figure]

Figure 1: Overview of Interaction of Component parts of the Portable Incubator


Figure 2: Flowchart for the Portable Incubator


Figure 3: Circuit Diagram for the Portable Incubator

IV. IMPLEMENTATION AND TESTING
For system implementation the ESP32 is selected as the controller of choice. The testing phase comes after the actual system has been implemented based on the system design.
The building of the Portable incubator is shown in Figure 4


Figure 4: Building the Portable Incubator

The connections in the incubator are shown in Figure 5


Figure 5: Electrical Connections

The powder used for detection of coliform is shown in Figure 6


Figure 6: Coliform Detect Powder

Mixture of the coliform detect powder with our water sample
The test results of the incubation is shown in Figure 7


Golden hue | Darkish green(after 16hours of incubation)

Figure 7: Test Results

Results for Test 1 is shown in Figure 8


Figure 8: Test 1- Beaker Placement on LDR1

In this test, the beaker containing the contaminated water sample was placed directly on top of LDR 1. The LDR's response to the presence of coliform-contaminated water was recorded, and the resulting resistance readings were observed. The experiment provided insights into how LDR 1 detected the contamination based on the proximity of the sample.

Results for Test 2 is shown in Figure 9


Figure 9: Test 2 - Beaker Placement on LDR2
For the second test, the same contaminated water sample beaker was placed on top of LDR 2. The LDR's response was again recorded, and the resistance readings were compared to the readings obtained in Test 1. This comparison helped assess whether different LDR locations within the incubator affected the detection process.
Results for Test 3 is shown in Figure 10


Figure 10: Test 3 - Beaker Placement on LDR3
In the third test, the contaminated water sample beaker was positioned on LDR 3. Just like in the previous tests, the LDR readings were captured, and the variations were analyzed. This test provided further data on the relationship between LDR location and the accuracy of coliform detection.

The Blynk app collected the incubator readings in real time as shown in Figure 11


Figure 11: Blynk GUI used for real-time monitoring

V. CONCLUSION
This paper presents an effective mode of detecting coliform in water using Iot. This provides a quick and cheaper alternative to traditional lab examination. We achieved the following:
a. Successful design and construction of the portable incubator establishing a controlled environment, ensuring precise temperature control within the necessary range for coliform growth and detection.
b. The integrated LDR sensor demonstrated its capability to monitor coliform presence and growth through changes in resistance. Calibrated LDR readings, correlated with coliform levels, enabled real-time monitoring via the user-friendly Blynk app.
c. The Blynk app proved invaluable for remote data analysis and visualization, empowering informed decision-making based on readily available coliform level information.
By achieving these milestones, this project significantly contributes to SDG 6, addressing water sanitation and quality, and facilitating the overall improvement of water management practices.

VI. ACKNOWLEDGEMENT
The authors will like to thank Covenant University for covering the costs of this study.

REFERENCES
[1] S. T. Odonkor and J. K. Ampofo, “Escherichia coli as an indicator of bacteriological quality of water: an overview,” Microbiol Res (Pavia), vol. 4, no. 1,
p. 2, Jun. 2013, doi: 10.4081/mr.2013.e2.
[2] “Coliform Bacteria and drinking water,” 2016.
[3] WHO Press. Geneva. (2011), “World Health Organization (WHO). Guidelines for Drinking Water Quality, 4th Edition”.
[4] A. Rompré, P. Servais, J. Baudart, M.-R. De-Roubin, and P. Laurent, “Detection and enumeration of coliforms in drinking water: current methods and
emerging | approaches.” | [Online]. | Available:
www.elsevier.com/locate/jmicmeth
[5] P. Pal, “Detection of Coliforms in Drinking Water and its Effect on Human Health - A Review,” International Letters of Natural Sciences, vol. 17, pp. 122–131, Jun. 2014, doi: 10.18052/www.scipress.com/ilns.17.122.
[6] C. P. G. and T. J. G. Ian L. Pepper, Environmental Microbiology: A Laboratory Manual, 4th edition. 2014.
[7] A. Schertenleib, J. Sigrist, M. N. D. Friedrich, C. Ebi, F. Hammes, and S. J. Marks, “Construction of a Low-cost Mobile Incubator for Field and Laboratory Use,” J Vis Exp, no. 145, Mar. 2019, doi: 10.3791/58443.
[8] H. Khurshid et al., “Bacterial prediction using internet of things (IoT) and machine learning,” Environ Monit Assess, vol. 194, no. 2, Feb. 2022, doi: 10.1007/s10661-021-09698-4.
[9] Siti Farah Binti Hussin and Zainolrin Bin Saari, “Portable Incubator For E.coli and Coliform

Bacterial GrowthUsing IoT,” 2020. [Online]. Available:
https://www.researchgate.net/publication/34633188 9
[10] F. Jan, N. Min-Allah, and D. Düştegör, “Iot based smart water quality monitoring: Recent techniques, trends and challenges for domestic applications,” Water (Switzerland), vol. 13, no. 13. MDPI AG, Jul. 01, 2021. doi: 10.3390/w13131729.

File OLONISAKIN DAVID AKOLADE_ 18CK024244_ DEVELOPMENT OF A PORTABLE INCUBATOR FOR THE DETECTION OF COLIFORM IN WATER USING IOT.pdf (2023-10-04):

DEVELOPMENT OF A PORTABLE INCUBATOR FOR THE

DETECTION OF COLIFORM IN WATER USING IOT

BY

OLONISAKIN DAVID AKOLADE
(18CK024244)

A PROJECT REPORT SUBMITTED TO THE DEPARTMENT OF

ELECTRICAL & INFORMATION ENGINEERING, IN PARTIAL

FULFILLMENT OF THE REQUIREMENTS FOR THE AWARD

OF THE BACHELOR OF ENGINEERING DEGREE IN

ELECTRICAL AND ELECTRONICS ENGINEERING.

SUPERVISOR:

DR. OSEMWEGIE OMORUYI

JUNE 2023

ii

DECLARATION

I, OLONISAKIN DAVID AKOLADE (18CK024244), hereby declare that I carried

out the work reported in this project in the Department of Electrical and Information

Engineering, Covenant University, under the supervision of Dr. Osemwegie Omoruyi.

I also solemnly declare that to the best of my knowledge; no part of this report has been

submitted here or elsewhere in a previous application for the award of a degree. All

sources of knowledge used have been duly acknowledged.

OLONISAKIN DAVID AKOLADE

18CK024244

iii

CERTIFICATION
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

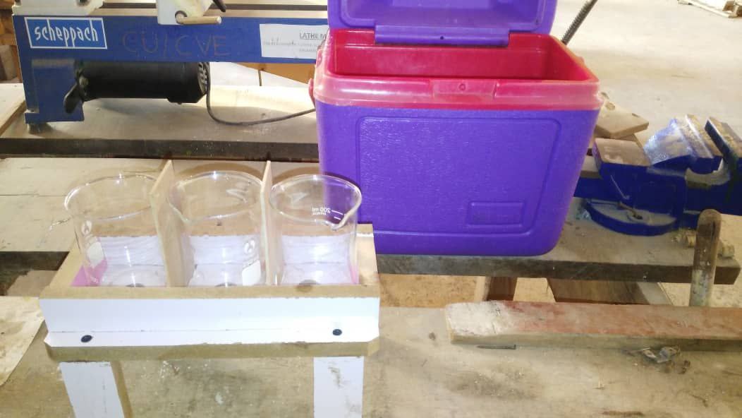
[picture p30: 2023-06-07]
incubator- 3.jpg

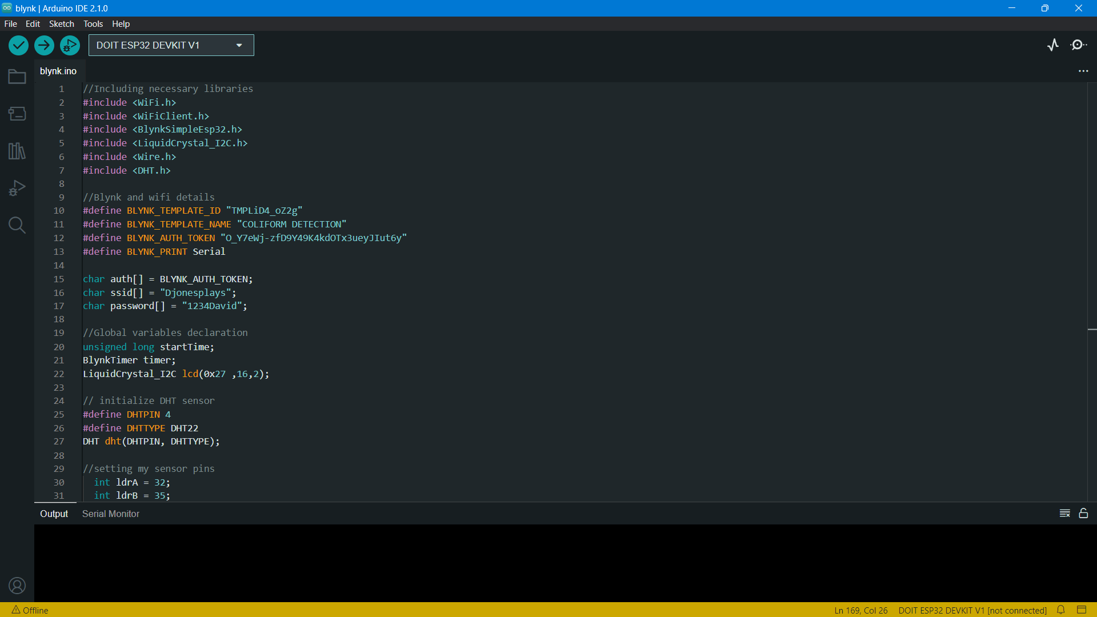
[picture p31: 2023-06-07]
code snippet - beginning.png

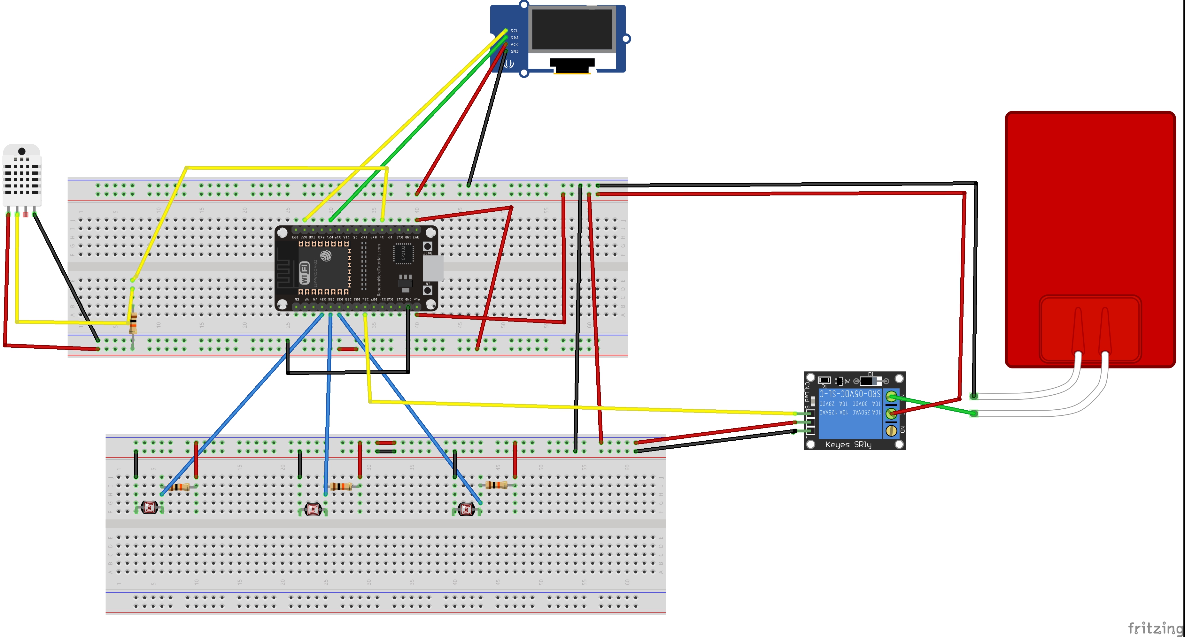
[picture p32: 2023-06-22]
CircuitDiagram - fritzing_bb.jpg

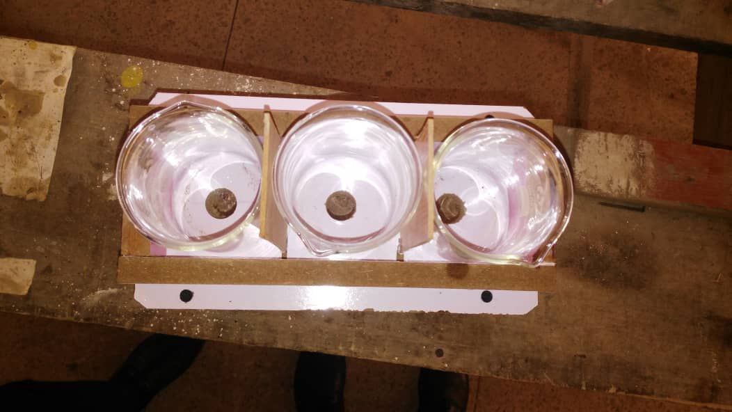
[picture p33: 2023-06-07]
top view of beaker.jpg

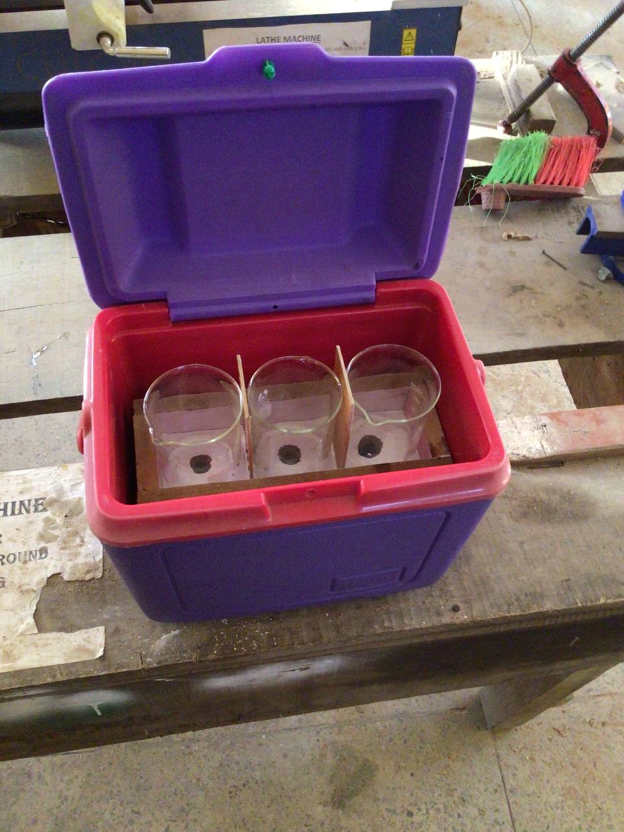
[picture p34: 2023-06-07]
incubator.jpg

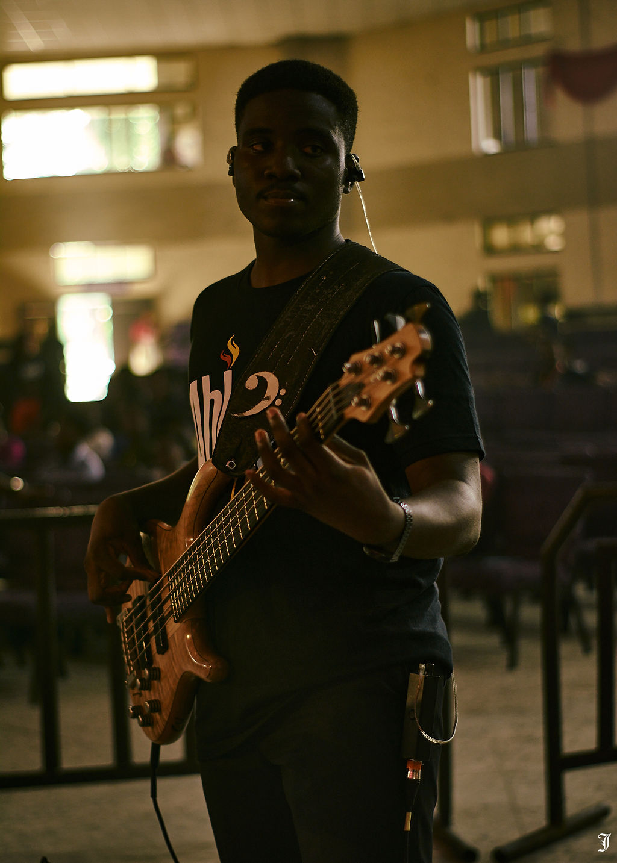
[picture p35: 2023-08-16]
GAS_9604.jpg

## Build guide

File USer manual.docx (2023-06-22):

DEVELOPMENT OF A PORTABLE INCUBATOR FOR THE DETECTION OF COLIFORM IN WATER USING IOT

BY

OLONISAKIN DAVID AKOLADE

(18CK024244)

&

OGUIBE FAVOUR OZIOMACHUKWU

(18CK024232)

User Manual

Table of Content

# Introduction

Welcome to the user manual for our state-of-the-art Portable Incubator for Coliform Detection. This guide will walk you through the setup process, usage instructions, and provide important information to ensure optimal performance. By following this manual, you'll become a pro at using our incubator and monitoring coliform bacteria in water samples. Let's get started!

# Guidelines/Directions

## Power Supply

i Connect the provided adapter to the power source (230V) by plugging in the cord, as the other end is soldered inside the incubator.
ii Our provided adapter is a 230VAC - 5V DC adapter, specifically designed for this incubator.
iii In the unlikely event that the provided adapter malfunctions, it is recommended to replace it with another adapter with the same specifications: 230V AC -5V DC, capable of handling a maximum current of 3A.

## Switching On the Incubator

i Press the power button to switch on the incubator.
ii The LCD screen will display an initial welcome message.

## Establishing a Connection

i The ESP32 will connect to a hotspot for data transmission.
ii Create a 2.4GHz hotspot with the following details:
iii Hotspot Name: Coliform
iv Hotspot Password: bacteria

## Visualizing Sensor Readings

Access the Blynk application to monitor sensor readings in real-time.

Visit https://blynk.cloud/dashboard/login on your device's web browser.

## Blynk Login Credentials

Use the following login credentials to access the Blynk application:

Username: olonisakind@gmail.com

Password: coliformbacteria

## Visual Guidelines:

Refer to the attached pictures for visual instructions and guidance.

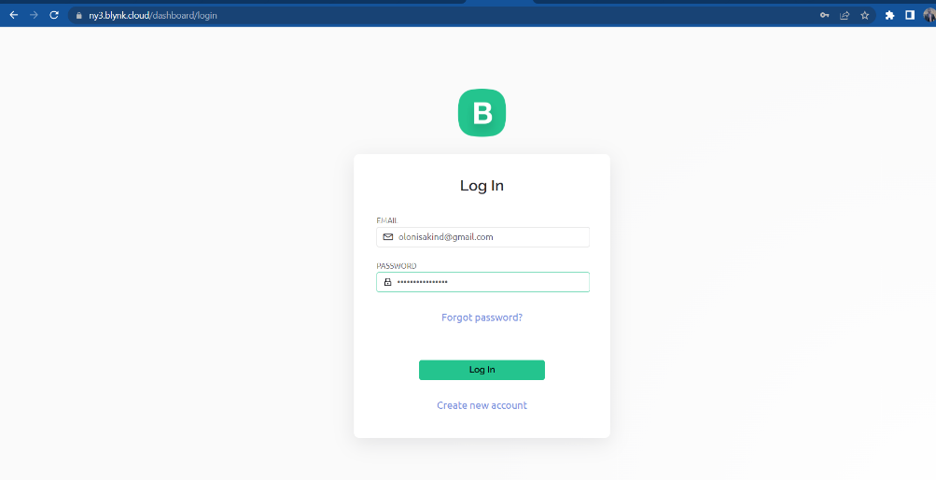
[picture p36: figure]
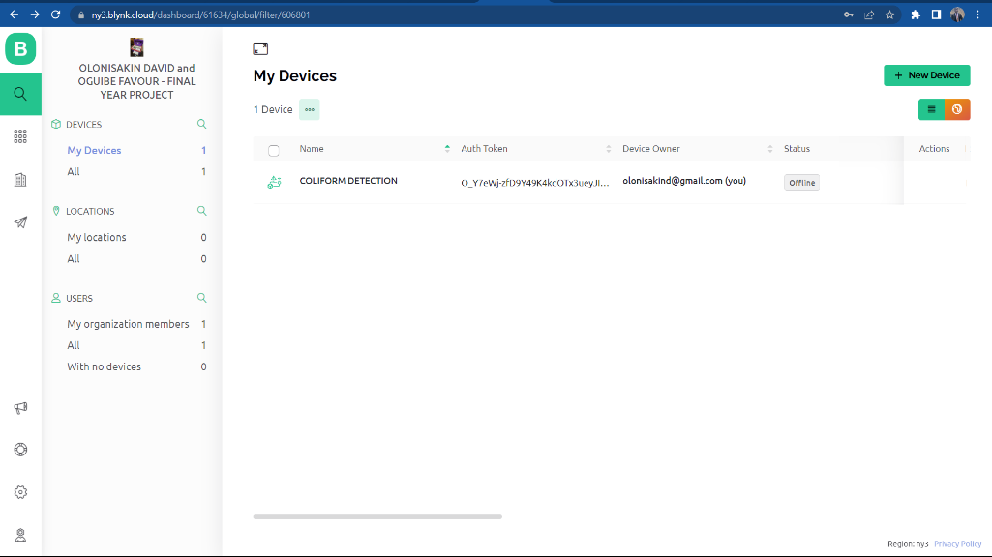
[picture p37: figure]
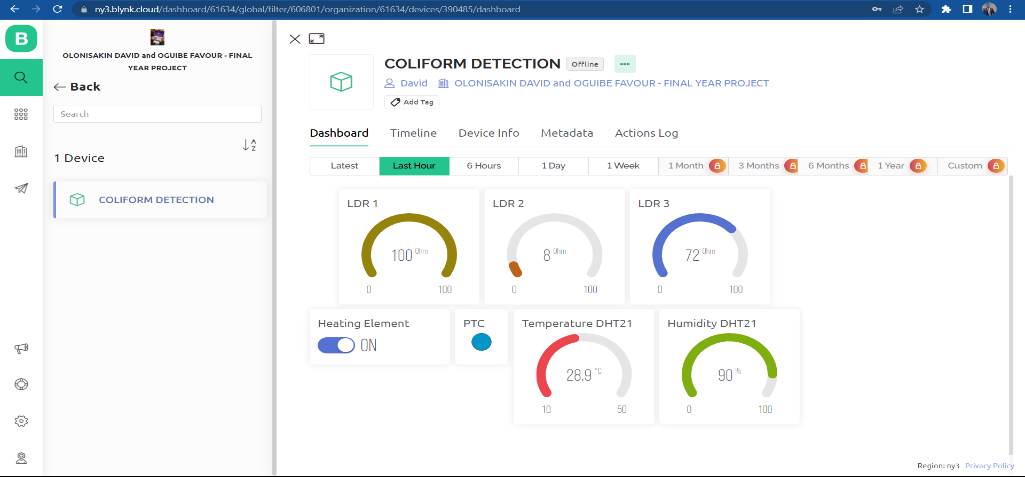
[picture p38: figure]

# Precautions

i Always use the provided 230V-5V adapter to power the incubator.
ii In the event of adapter malfunction, replace it with another adapter with the same specifications: 230V-5V, capable of handling a maximum current of 3A.
iii Do not use adapters with different voltage or current specifications.
iv Avoid exposing the incubator to water or other liquids.
v Keep the incubator away from extreme temperatures and direct sunlight.
vi Ensure proper ventilation during operation.
vii Follow electrical safety guidelines and use a stable power source.

# Summary

When all is done well you should have your incubator working as the image attached below:

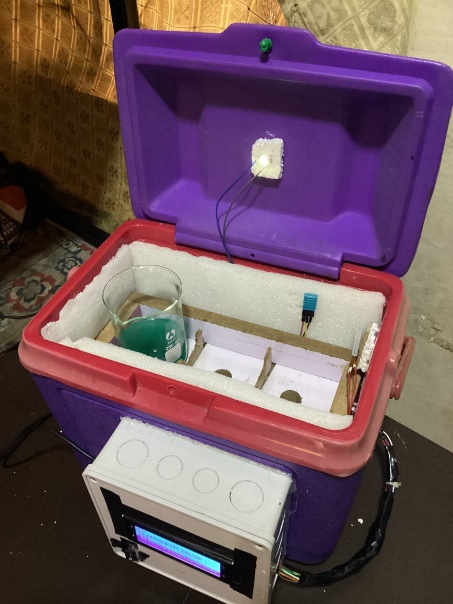
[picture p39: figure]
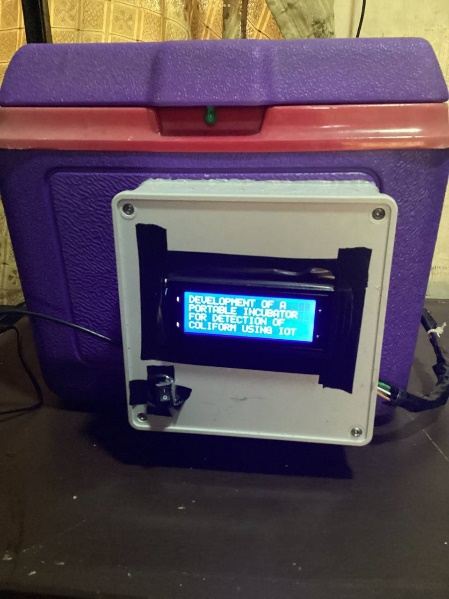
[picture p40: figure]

Congratulations! You are now equipped with the necessary knowledge to operate our Portable Incubator for Coliform Detection. By following the guidelines and precautions provided in this manual, you can effectively monitor sensor readings and contribute to improved water quality assessment. If you have any further questions or need assistance, please refer to this manual or reach out to us on linkeldn

# GitHub Link

For accessing the project files, including the code and other related files, visit the

GitHub repository: https://github.com/olonisakindavid/FinalYearProject

You can explore the repository to find detailed information about the project implementation and access the necessary resources.

# Using Coliform Detect Powder for Testing

We used a Coliform Detect Powder for testing, which can be purchased from liofilchem, an online store based in Italy. Visit their website for more information. http://www.liofilchem.net/

To perform the test, mix the Coliform Detect Powder with a 100ml water sample in a beaker. After incubating for 16 hours, observe a bluish-green color to indicate the presence of coliform bacteria. You can continue using Blynk and the LCD for visualization during the incubation process.

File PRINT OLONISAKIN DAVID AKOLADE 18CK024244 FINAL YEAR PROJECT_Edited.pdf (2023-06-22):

DEVELOPMENT OF A PORTABLE INCUBATOR FOR THE

DETECTION OF COLIFORM IN WATER USING IOT

BY

OLONISAKIN DAVID AKOLADE
(18CK024244)

A PROJECT REPORT SUBMITTED TO THE DEPARTMENT OF

ELECTRICAL & INFORMATION ENGINEERING, IN PARTIAL

FULFILLMENT OF THE REQUIREMENTS FOR THE AWARD

OF THE BACHELOR OF ENGINEERING DEGREE IN

ELECTRICAL AND ELECTRONICS ENGINEERING.

SUPERVISOR:

DR. OSEMWEGIE OMORUYI

JUNE 2023

ii

DECLARATION

I, OLONISAKIN DAVID AKOLADE (18CK024244), hereby declare that I carried

out the work reported in this project in the Department of Electrical and Information

Engineering, Covenant University, under the supervision of Dr. Osemwegie Omoruyi.

I also solemnly declare that to the best of my knowledge; no part of this report has been

submitted here or elsewhere in a previous application for the award of a degree. All

sources of knowledge used have been duly acknowledged.

OLONISAKIN DAVID AKOLADE

18CK024244

iii

CERTIFICATION

This is to certify that the project titled “DEVELOPMENT OF A PORTABLE

INCUBATOR FOR THE DETECTION OF COLIFORM IN WATER USING

IOT” by Olonisakin David Akolade, meets the requirements and regulations governing

the award of the Bachelor of Engineering in Electrical and Electronics Engineering

degree of Covenant University and is approved for its contribution to knowledge and

literary presentation.

Supervisor 1: | Sign: _________________ | ____________________
Name: Dr. Osemwegie Omoruyi | Date:
Internal Examiner: | Sign: _________________ | ____________________
Name: | Date:
Head of Department: | Sign: _________________ | ____________________
Name: Dr. Isaac Samuel | Date:

iv

DEDICATION

This research project is dedicated to my parents, Dr. Rotimi Olonisakin and Mrs.

Bolatito Olonisakin who were very understanding and supportive throughout the time

taken to complete this project, providing the resources necessary to make this project

possible. I also dedicate this project to the countless communities in Nigeria who lack

access to clean water.

v

ACKNOWLEDGEMENTS

First and foremost, I would like to begin by expressing my deepest gratitude to God for

His divine guidance, wisdom, and grace throughout this project. I am forever grateful

for His constant presence and blessings in my life.

I would also like to extend my sincere appreciation to my parents for their unwavering

love, support, and encouragement. Their sacrifices, guidance, and prayers have been a

source of strength and motivation throughout this journey. I am truly blessed to have

them as my role models.

I would like to take this opportunity to express my deepest appreciation and gratitude

to my exceptional project partner, Oguibe Favour Ozioma. Together, with a

harmonious blend of teamwork, unwavering dedication, and the power of prayers, we

successfully transformed our shared idea into a remarkable reality.

I would like to express my heartfelt thanks to my project supervisor, Dr. Osemwegie

Omoruyi for His invaluable guidance, expertise, and support. His insightful feedback,

constructive criticism, and dedication have been instrumental in shaping the direction

and success of this project.

Furthermore, I want to thank the Head of Department, Dr. Isaac Samuel, and all my

lecturers for impacting me with knowledge and passing me through various tasks that

have, in one way or the other, prepared me for the gallant execution of this project.

Finally, I would also like to acknowledge the support and encouragement of my lovely

sisters, Favour and Delight Olonisakin, who have been there for me through thick and

thin. Their kind words, motivational messages, and belief in my abilities have helped

me to stay focused and motivated.

vi

ABSTRACT

Having access to clean and safe drinking water is considered a crucial human right, yet millions of individuals continue to live without it. The consumption of water that has been contaminated can increase the risk of experiencing outbreaks of different diseases that are transmitted through water, which are a leading cause of death worldwide. This project aims to develop a portable and low-cost incubator for detecting coliform bacteria in water, which is achieved by using a light-dependent resistor (LDR) and a heating element controlled by an IOT equipped microcontroller (ESP32). The incubator creates a controlled environment for water samples to incubate and for the LDR sensor to detect changes in turbidity, indicating the presence of coliform bacteria. Additionally, a Digital Humidity and Temperature (DHT11) sensor and a heating element helps maintain a temperature range of 35-37°C, the ideal temperature for optimal coliform bacteria growth. The incubator also features a Liquid Crystal Display (LCD) displaying resistance and temperature readings. After the data is collected, it is transferred to the microcontroller and subsequently transmitted to the Blynk application for continuous monitoring and analysis in real-time. The portability and affordability of this incubator makes it appropriate for use in remote areas where access to laboratory equipment is limited. This study carries significant implications for the advancement of low-cost and portable water quality monitoring systems, potentially leading to improvements in public health.

Keywords: portable incubator, coliform bacteria , water monitoring, light-dependent resistor.

vii

TABLE OF CONTENT

DECLARATION | ii
CERTIFICATION | iii
DEDICATION | iv
ACKNOWLEDGEMENTS | v
ABSTRACT | vi
TABLE OF CONTENT | vii
LIST OF TABLES | x
LIST OF FIGURES | xi
LIST OF ABBREVIATIONS | xiii
CHAPTER ONE | 1
INTRODUCTION | 1
1.1 Background of Study | 1
1.2 Significance of Study | 2
1.3 Problem Statement | 2
1.4 Aim and Objectives | 2
1.5 Methodology | 2
1.5.1 Waterfall Model of Methodology | 3
1.5.2 Description of the Waterfall model | 3
1.6 Scope of Study | 4
1.7 Limitations of the Study | 5
1.8 Project Organization | 5
CHAPTER TWO | 7
LITERATURE REVIEW | 7
2.1 Introduction | 7
2.2 Coliform Bacteria: A Quick Overview | 7
2.3 Significant Factors that promote Coliform Bacteria infestation in water | 9
2.3.1 Septic Tank Systems. | 10
2.4 The significance of finding Coliform bacteria in water | 15
2.5 Traditional methods of detecting Coliform in water | 16
2.5.1 Membrane filter method | 17
2.5.2 Multiple-tube fermentation technique | 17
2.5.3 Molecular methods | 18
2.5.4 Enzymatic method/defined substrate method. | 20
2.6 Internet of Things (IOT): A Quick Overview | 21
2.6.1 Structure of the Internet of Things (IOT) | 22

viii

2.6.2 IOT's relevance for detecting bacteria in water and its utility in detecting
coliform | 24
2.7 Review of related works | 25
2.8 Summary | 29
CHAPTER THREE | 30
SYSTEM ANALYSIS AND DESIGN | 30
3.1 Introduction | 30
3.2 Components | 30
3.2.1 ESP 32 | 30
3.2.2 Light Dependent Resistor (LDR) | 31
3.2.3 Relay | 31
3.2.4. DC-DC Buck Converter | 32
3.2.5 PTC Electrical Heating Element | 33
3.2.6 LED Bulb | 33
3.2.7 DHT11 Temperature and Humidity Sensor | 34
3.2.8 Liquid Crystal Display (LCD) | 34
3.2.9 I2C Serial Interface Adapter Module | 35
3.2.10 Incubator | 35
3.2.11 Beaker | 36
3.2.12 Water Detect Coliform Powder | 36
3.2.13 Power Supply Adapter | 37
3.2.14 10k resistors | 38
3.2.15. Polyethylene foam | 38
3.4 Description of Software Requirements | 39
3.4.1 Arduino Integrated Development Environment (IDE) | 39
3.4.2 Blynk | 40
3.3 Design specification | 42
3.3.1 Systems Block Diagram | 42
3.3.2 Circuit Diagram | 42
3.3.3 Systems Algorithm | 43
3.3.4 Systems Flowchart | 45
3.3.5 Electrical Calculations | 45
3.5 Conclusion | 49
CHAPTER FOUR | 50
RESULTS AND DISCUSSIONS | 50
4.1 Introduction | 50
4.2 Hardware Implementation | 51

ix

4.2.1 DHT 11 sensor and PTC heating element testing | 53
4.2.2 Relay and PTC heating element connection | 55
4.3 LDR calibration and testing | 58
4.3.1 Calibration and Mapping of LDRs | 59
4.3.2 Final results | 63
4.4 Bill Of Engineering Material and Evaluation (B.E.M.E) | 67
4.5 Summary | 67
CHAPTER FIVE | 68
CONCLUSIONS AND RECOMMENDATIONS | 68
5.1 Conclusion | 68
5.2 Achievements | 69
5.3 Challenges encountered | 69
5.4 Recommendations | 70
REFERENCES | 72

x

LIST OF TABLES

Table 3.1: Component Voltage and Current Values | 48
Table 4.1: Bill Of Engineering Material and Evaluation (B.E.M.E) | 67

xi

LIST OF FIGURES

Figure 1.1: Waterfall model | 3
Figure 2.1: Different Groups of Coliform Bacteria [7] | 9
Figure 2.2: IoT Analytics Flow [60] | 23
Figure 3.1: Expressif Systems Processor (ESP) 32 | 31
Figure 3.2: Light Dependent Resistor (LDR) | 31
Figure 3.3: Relay | 32
Figure 3.4: DC-DC Buck Converter | 32
Figure 3.5: Heating Source | 33
Figure 3.6: LED Bulb | 33
Figure 3.7: DHT 11 | 34
Figure 3.8: Liquid Crystal Display | 34
Figure 3.9: I2C Serial Interface Adapter Module | 35
Figure 3.10: Incubator | 36
Figure 3.11: Beaker | 36
Figure 3.12: Water Detect Coliform Powder | 37
Figure 3.13: Power Supply Adapter | 37
Figure 3.14: 10k resistors | 38
Figure 3.15: Polyethylene foam | 38
Figure 3.16: Arduino Integrated Development Environment (IDE) | 39
Figure 3.17: Arduino Integrated Development Environment (IDE) Code Snippet | 40
Figure 3.18: Blynk Application | 41
Figure 3.19: Systems Block Diagram | 42
Figure 3.20: Circuit Diagram | 42
Figure 3.21: Systems Flowchart | 45

xii

Figure 4.1: Inside of incubator with base padded with polyethylene foam | 51
Figure 4.2: Beaker stand | 52
Figure 4.3: LDR legs attached to base of beaker | 52
Figure 4.4: Internal image of incubator showing wiring to the outside | 53
Figure 4.5: DHT pin configuration | 54
Figure 4.6: DHT 11 to ESP32 wiring diagram | 54
Figure 4.7: Single Channel relay pin-out Diagram | 55
Figure 4.8: Image of code showing heating element conditions | 56
Figure 4.9: Relay to heater connection diagram | 57
Figure 4.10: Image showing final soldering and wiring | 57
Figure 4.11: Voltage divider circuit for LDR | 58
Figure 4.12: Serial monitor readings of LDR resistance readings while LED off | 59
Figure 4.13: Code showing mapped LDR resistance values | 60

Figure 4.14: Water sample containing coliform bacteria mixed with water detect

coliform powder | 61
Figure 4.15 : Water sample after 16 hours of incubation | 62

Figure 4.16: Color of water sample uninfected with coliform bacteria after 16 hours of

incubation | 62

Figure 4.17: LDR readings when beaker with contaminated water was placed on each

LDR | 63
Figure 4.18: Showing results when sample beaker is on LDR 1 | 64
Figure 4.19: Showing results when sample beaker is on LDR 2 | 65
Figure 4.20: Showing results when sample beaker is on LDR 3 | 66

xiii

LIST OF ABBREVIATIONS

AC: Alternating Current

DC: Direct Current

DHT: Digital Humidity and Temperature

EEPROM: Electrically Erasable Programmable Read-Only Memory

E. coli: Escherichia coli

ESP: Expressif Systems Processor

GPIO: General Purpose Input Output

I2C: Inter Integrated Circuit

IDE: Integrated Development Environment

IOT: Internet of Things

LCD: Liquid Crystal Display

LDR: Light Dependent Resistor

LED: Light Emitting Diode

OS: Operating System

PTC: Positive Temperature Coefficient

### 1. CHAPTER ONE

INTRODUCTION

### 1.1 Background of Study

The research was inspired by the need for precise and trustworthy techniques for

identifying waterborne infections, especially coliform bacteria, in places with few

laboratory facilities. Coliform bacteria are used as a quality gauge for water and are a

sign that potentially dangerous diseases may be present. Ensuring the availability of

safe drinking water stands as a key priority in public health efforts because it is

intimately related to human health. Consuming water that contains hazardous

chemicals or pathogenic organisms has a major influence on one's health[1].

The lack of low-cost, simple-to-use, and accurate techniques for remote water

monitoring and coliform detection is the key issue driving this research. Due to

difficulties with transportation, sample storage, and inadequate laboratory facilities,

traditional laboratory-based approaches are frequently not practical in remote places.

Thus, the creation of a mobile incubator for coliform detection could be the answer to

this issue.

The project is aimed towards developing a portable incubator that can quickly and

accurately detect coliform bacteria in water using an approach that is both affordable

and simple to use. One approach to detect these organisms involves filtering a 100 mL

water sample through a membrane. Subsequently, the filtered membrane is incubated

on specialized media at temperatures ranging from 35 to 37 °C for E. coli or 44 to 45

°C for TTC[2]. The issue of restricted access to laboratory facilities for water

monitoring and coliform detection can be resolved by the portable incubator, especially

in distant locations. The study is important because it may increase access to clean

water, especially in locations where waterborne diseases are common. The mobile incubator might also be used for environmental research and monitoring, which would

improve water management and public health.

### 1.2 Significance of Study

The development of a portable incubator for remote water monitoring and detection of

coliform is an important initiative that can improve access to safe water, particularly in

remote areas. Traditional laboratory-based methods for coliform detection are often not

feasible in such areas due to transportation, sample storage, and limited laboratory

facilities.

This project aims to address the problem of limited access to laboratory facilities by

providing a low-cost, easy-to-use, and reliable method for remote water monitoring and

coliform detection. The portable incubator is designed to use a LDR and a light bulb,

where a resistance drop or increase is detected depending on the coliform growth.

Afterward, this data is transmitted to the ESP32 for additional analysis. Additionally, a

DHT 11 sensor is in place to regulate the temperature of the incubator at 35-37 degrees

Celsius via the heater. The significance of this study is highlighted below;

1. Improve access to safe water, particularly in remote areas.
2. Enhance public health efforts in identifying and preventing waterborne

diseases.

3. Contribute to water management and environmental monitoring

research.

4. Increase efficiency in water monitoring by eliminating transportation of

water samples for analysis in a laboratory

5. Enable citizen science initiatives for community-led efforts towards

sustainable water management.

### 1.3 Problem Statement

The current methods for detecting coliform bacteria in water samples require laboratory

analysis, which can be time-consuming and resource-intensive. This can limit the

ability to effectively monitor water quality, particularly in remote areas. Therefore,

there is a need for a portable incubator that can detect coliform bacteria remotely, and

enable more efficient and timely water monitoring activities.

### 1.4 Aim and Objectives

Aim: To develop a portable incubator for remote water monitoring and detection of

coliform.

Objectives

The project has the following objectives:

i. To develop and construct a portable incubator capable of maintaining a specific

temperature range of 35-37°C using a ESP32-powered relay to control the

heating element and sensor readings.

ii. | To detect coliform bacteria growth using an LDR sensor and a bulb by
| monitoring the changes in resistance.
iii. | To develop a real-time monitoring and data visualization of coliform levels.
iv. | To validate the accuracy and effectiveness of the portable incubator in detecting
| coliform bacteria.

### 1.5 Methodology

The proposed research falls under the field of environmental science and seeks to

examine the quality of water samples that are already contaminated with coliform

bacteria. The project will utilize the Waterfall model of methodology, an iterative process for creating a system or solving a problem that structures the entire job into

segments to ensure precision.

### 1.5.1 Waterfall Model of Methodology

This project has been successfully accomplished by implementing the following

strategy:

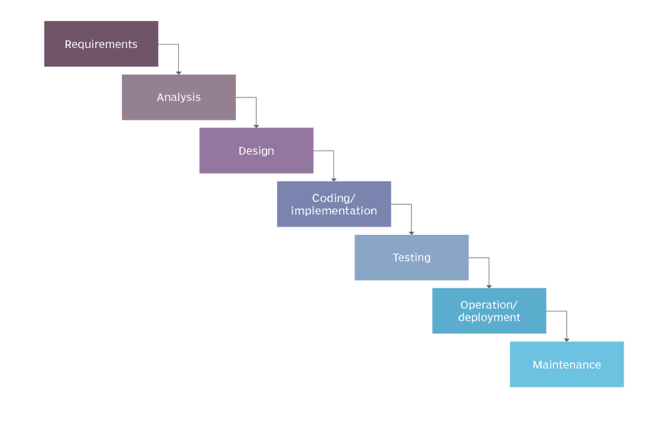
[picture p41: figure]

Figure 1.1: Waterfall model

### 1.5.2 Description of the Waterfall model

The work has been grouped into seven sections;

1 | Requirements Gathering Phase: In this phase, the aim and objectives of the project
| will be defined, and the specific requirements for the research will be gathered.
2 | Analysis Phase: In this phase, the water samples containing coliform will be
| analyzed, and the most suitable water samples for the experiment will be identified
| and selected based on specific criteria.

3 | Design Phase: In this phase, the portable incubator will be designed, and the
| DHT11 sensor and LDR will be integrated into the system.
4 | Implementation Phase: In this phase, the incubator will be set up, and the selected
| water samples will be placed in it. The temperature and light exposure within the
| incubator will be monitored using the DHT11 sensor and LDR, respectively.
5 | Testing Phase: In this phase, any changes in the resistance levels of the LDR due
| to bacterial growth in the water samples will be recorded.
6 | Deployment Phase: The data acquired during the testing phase will undergo
| statistical analysis to identify and quantify the existence of coliform bacteria in the
| water samples. Statistical methods will be employed to assess the presence and
| concentration of coliform bacteria based on the collected data.
7 | Maintenance Phase: During this phase, any required modifications to the
| experiment will be implemented in response to the discoveries and outcomes of
| the investigation. Finally, conclusions and suggestions will be drawn based on the
| results obtained.

### 1.6 Scope of Study

The primary focus of this research is to conceive and create an economical and easily

transportable incubator tailored for remote monitoring of water quality and

identification of coliform bacteria. The incubator will utilize a light-dependent resistor

(LDR) to detect changes in turbidity, and a DHT11 sensor to maintain a consistent

temperature of 35-37°C inside the incubator. The incubator's operation will rely on a

230 AC – 5V DC power supply and monitored using ESP32 module. The study will

involve designing and constructing the incubator, testing its sensitivity and specificity

for detecting turbidity increases, and evaluating its performance in a real-world setting.

The study aims to provide a cost-effective and efficient solution for monitoring water

quality in remote areas where access to laboratory equipment is limited.

### 1.7 Limitations of the Study

Limitations associated with this project include:

i. The precision of coliform detection might be influenced by various factors,

including the quality of the water sample and the calibration of the LDR sensor.

ii. | The use of an ESP32 microcontroller for data transmission may have limited
| range and reliability in remote areas with poor internet connectivity.
iii. | The incubator may require frequent calibration and maintenance to ensure
| consistent temperature and humidity levels for accurate readings.
iv. | The heating source required to increase the temperature in the incubator uses
| up a significant amount of power, which makes it impractical to use a battery
| as a power source.
v. The size and portability of the incubator may limit the amount of water samples
| that can be tested at once, potentially affecting the scalability of the system.

### 1.8 Project Organization

The report is structured into five chapters, each contributing to a comprehensive

understanding of the project. Chapter One serves as a broad introduction, providing a

general perspective on the research, contextual background, specific goals and

objectives, targeted issues, and a concise outline of the chosen methodology. In Chapter

Two, a thorough literature review is presented, delving into relevant studies to establish

a theoretical framework and provide additional insights crucial for a comprehensive

grasp of the project. Chapter Three focuses on the project's methodology, discussing

the necessary components, specifications, design considerations, and innovations, including system block diagram representation and hardware design. Moving on to

Chapter Four, the implementation and testing of the project are covered, showcasing

the practical system design and featuring in-progress photos. This chapter also entails

a comprehensive examination and analysis of the project's findings and outcomes.

Finally, Chapter Five serves as the concluding chapter, summarizing the study's

conclusive remarks, outcomes, and displaying the project's achievements.

### 2. CHAPTER TWO

LITERATURE REVIEW

### 2.1 Introduction

Many researchers have investigated the prevalence of coliform bacteria in various

sources of water. Coliform bacteria existence in drinking water is a huge public health

concern. Although total coliform bacteria are widespread and typically not harmful, the

presence of fecal coliforms and E. coli may pose a potential danger to human health.

Coliform bacteria, including total coliforms, fecal coliforms, and E. coli, are frequently

employed as indicators of water quality. [3] . This chapter provides a comprehensive

overview of Coliform bacteria, including the major factors that contribute to their

presence in water, the potential health effects of exposure to these bacteria, traditional

methods for detecting them in water, relevance of IoT technology in the detection of

Coliform bacteria in water and review similar works in the literature.

### 2.2 Coliform Bacteria: A Quick Overview

Coliform bacteria are rod-shaped, non-spore-forming, Gram-negative, oxidase-

negative, facultatively anaerobic organisms that have a cell wall appearing pink or red

when stained and can survive in both oxygenated and non-oxygenated environments

[4]. Coliforms are a class of bacteria that are present in soil, plants, and the digestive

tracts of all animals, including humans. While most coliforms are harmless, the

presence of certain coliforms, like E. coli, in drinking water might signal that the water

may be polluted with feces, which increases the risk of illness. The presence of

additional pathogens is possible if E. coli is discovered in the water, since E. coli itself

can be a pathogen. The intestine of warm-blooded mammals is where it typically began

[5]. In the past, the presence of the intestinal bacteria known as coliforms has been

cited as a sign that a location has been contaminated by sewage from people.

Additionally, the feces of affected people contain harmful germs including Shigella

and Salmonella[6].

Coliform bacteria are classified into three types that indicate the safety of water and

differ in the level of risk. The term "total coliform" encompasses a wide range of

bacteria, including those present in fecal matter, which is a subset of all coliforms. One

variety of fecal coliform bacteria is E. coli. When testing drinking water samples,

laboratories check for the presence of total coliform, and if it is detected, the sample is

further examined see whether it contains E. coli[3]. Total coliform bacteria presence is

commonly observed in nature and does not pose a significant threat. Drinking water

contamination is most likely environmental when only total coliform bacteria are found

in it[7].

1. Total Coliform Bacteria: The common bacteria in the ecosystem known as total

coliforms is usually found in dirt or plants, and is widely regarded safe. If a laboratory

only observes total coliform bacteria in drinking water research, then it is likely that

the bacteria came from the environment and fecal pollution is rare. However, there is

a chance that harmful germs could get inside the system if it is prone to external

pollution. As a result, It is crucial to identify and address the primary cause of the

contamination.

2. Fecal Coliform Bacteria: In the intestines and feces of both humans and animals,

fecal coliform bacteria, a subtype of total coliform bacteria, are prevalent. The

identification of fecal coliforms in a water sample is typically indicative of recent fecal

contamination, and this poses a higher risk of potential pathogen presence compared to

situations where just total coliform bacteria are identified[7].

3. Escherichia coli: The bulk of E. coli types usually pose little worry and typically live

in the intestines of warm-blooded creatures like humans. E. coli is a subset of fecal

coliform germs. However, some kinds of E. coli can make people ill. When E. coli

bacteria are found in a portable water sample, it usually means that there has been

recent fecal pollution, which boosts the chance that disease-causing germs are present

[7]. The identification of E. coli in water samples typically indicates contamination

with feces, along with the potential existence of human-originating harmful organisms

[7]. Since E. coli can also be a pathogen, there is a possibility that other pathogens will

also be present if E. coli is discovered in the water[5]. Escherichia coli bacteria were

typically found in sewage discharges from human, animal, and plant sources, in that

order. Septic system failure, municipal landfills, and wastewater sludge application to

the land are all examples of human sources. Numerous animal sources, including

domestic pets, wild animals, cattle, the spreading of manure on land, pastures, and

feedlots, can release fecal coliform bacteria into the environment[8].

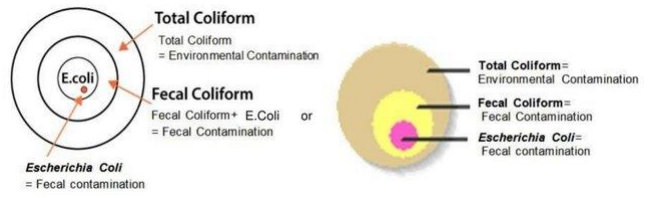
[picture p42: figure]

Figure 2.1: Different Groups of Coliform Bacteria [7]

### 2.3 Significant Factors that promote Coliform Bacteria infestation in

water

Water sources containing coliform bacteria pose a significant risk to the public's health

and are frequently contaminated by feces due to improper sanitation practices or

agricultural activities. It has been claimed that septic tank systems and farm waste are the main contributors to coliform bacteria in drinking water. Septic tank overflow and

other related factors contaminating drinking water sources with human feces

particularly raise the risk of Coliform contamination. The risk of contracting a

waterborne disease can also be increased by the use of pesticides and fertilizers in

agriculture, which can reduce the spread of coliform bacteria to water sources. To

protect public health and stop the spread of infectious diseases, coliform bacteria must

be found and monitored in drinking water.

2.3.1 Septic Tank Systems.

Water contamination is one of the biggest problems in the world today. Septic tank

effluent intrusion is one of the main causes of groundwater contamination. the principal

origin of harmful viruses and bacteria in the subterranean environment may be septic

tank effluent[9]. Contamination of aquifers has become a common problem as a result

of excessive groundwater pumping and uncontrolled human wastewater dumping into

the groundwater. Groundwater quality can be impacted by residential, business,

industrial, and agricultural activities. Groundwater is particularly sensitive in regions

with large population densities and extensive human use of the land[10].

Waste is temporarily stored in a septic tank while being pre-treated at that time.

There have been reports of septic tanks failing and leaking a lot, harming the ecosyste

m[11]. Researchers from several fields have done studies to show the detrimental

effects of situating septic tank systems close to drinking water sources. An examination

investigating the impacts of septic tank distances from wells and groundwater

contamination in the Agbowo suburb of Ibadan, Nigeria, was done[12]. Septic tanks

have been proven to malfunction and leak a lot, harming the environment [11].

Therefore, septic tanks are the primary source of waste that is directly released into

groundwater. Monitoring of water is therefore crucial to protect both the environment and human health[13]. Forty (40) ground water samples were replicated, and they were

taken from groundwater sources at different distances for bacteriological analysis, and

it was found that they were all infected with different types of bacteria as well as

coliform[12]. The number of feces and total coliforms decreased with increasing

distance from septic tanks, and this effect was more pronounced for water supply

distance from pollution sources. Because the problem of septic tank contamination of

ground water is a national concern rather than a local one in the study region, Standards

should be created for the separation of wells from septic tanks and the pretreatment of

well water[12]. Consuming groundwater that has been faecally contaminated and not

properly treated has been related to disease[14].

Underground water, or the water found below the earth's surface in soil pores and rock

formation fractures, has been impacted by the degradation of water's physicochemical

and biological properties brought on by industrialization and urbanization, which have

grown over time without consideration for the effects on the environment[15]. As a

result of population expansion and urbanization, ground and surface water are subject

to greater demands. The startling rate of urbanization in Nigeria is reflected in the 10–

15% yearly growth rates of the country's main cities[16] hence human activities like

enhancing soil fertility, irresponsibly disposing waste, and utilizing pit latrines, soak-

away pits, and septic tanks are increasing. In Nigeria, pipe-borne water is hard to find,

thus a lot of homes use wells that are close by but separate from septic tank.

Adequate drinking water sources are accessible to only 52% of the population in

Nigeria[17]. The proximity of septic tanks to wells and the unsanitary conditions in the

area around the wells are the main causes of contamination. Some wells are poorly

maintained and lack sufficient coverings or lids, making the water unfit for

consumption and raising the possibility of waterborne infections, and the unhygienic use of the wells. Additionally, the discharge of solid or liquid waste into pits, stream

channels, abandoned boreholes, landfills, or other unlined sites may result in

groundwater contamination[18].

The authors of a different study investigated the origins of E. coli contamination in

the coastal subtropical climate. They found that septic systems were a substantial

source of E. coli and total coliforms in both surface water and sediment. It was

evident that septic systems were a substantial source of pollution since there was a

positive correlation between the amount of E. coli in sediment and the distance from

them. The authors asserted that septic systems are a significant source of fecal

contamination in coastal areas and suggested introducing measures to guard against

contamination from septic systems[19].

Another study looked at how the presence of septic tanks affects the quality of the bor

ehole water in Port Harcourt, Nigeria[20]. In order to reach their conclusions, the

researchers collected water samples from boreholes both close to and distant from

septic tanks. Total dissolved solids (TDS), pH, total suspended solids (TSS), and

bacterial contamination were all investigated in the water samples (TSS). The

researchers found that the water quality in boreholes near sewage tanks was

significantly lower than in boreholes farther away from septic tanks. The water

samples collected from the vicinity of septic tanks contained higher concentrations of

TDS, TSS, and bacterial contamination, including coliform bacteria[20].

Another study used one-way ANOVA (Analysis of Variance) looked into the

connection between fecal coliform contamination and proximity to the septic tank. The

findings revealed that 96 percent of the examined wells had fecal coliform, indicating

that the drilled well's biological drinking water quality had been significantly

diminished. The excavated well was 53.7 feet away on average from the septic tank.

The results of the investigation showed that as the distance between the septic tank and

the drilled well rose, fecal coliform contamination level dropped. There were strong

evidence of fecal pollution in the dug-well water at 50% of the septic tanks within 50

feet[21].

### 1. Septic tank setback distances from water sources

Since the distance between septic tanks and water sources plays an important role in

coliform bacteria which causes water to become contaminated, various approaches for

estimating setback distances and conditional probabilities have been examined. To

place restrictions on the permitted places for septic tank placement, government

agencies have implemented laws stipulating minimum setback lengths between septic

tanks and drinking-water wells[22]. How likely is it that a setback distance (such one

required by the regulatory body) will be adequate to protect the city's ground water

from virus contamination? Given a specific probability level, what setback distance

would be necessary to ensure that the ground water would be immune to virus

contamination?[23] With little respect for the local geology, hydrology, and

meteorology, these setback distances are often required for at least a county-wide

area[23]. Various places have different topologies. Therefore, proper setback distance

calculations must be made by regulatory agencies to be able to guarantee that the

distance of septic tanks from water sources would give complete assurance that the

water is not contaminated with coliform. A study revealed that a setback distance of 40

m would be required for a specific location under consideration in order to be 90%

confident that the ground water would be appropriately protected from virus

contamination. If one wanted to be 99% sure that the setback was enough to stop viral

transmission in places where 15-m distances were first permitted, an 80-m distance

would be required[23].

### 2. Inadequate agriculture practices

Numerous studies have demonstrated how agricultural pollution may significantly

contribute to the coliform water contamination. One of the main sources of

contamination is the over use of fertilizers, notably those containing nitrogen and

phosphorus. According to the National Geographic Society, nutrient contamination

brought on by excessive fertilizer use leads to eutrophication, a process that harms both

terrestrial and aquatic ecosystems by overburdening them with nutrients[24]. Coliform

water contamination is a global problem that threatens the health of both people and

animals. Ineffective agricultural techniques have been identified as one of the main

sources of this problem. For instance, it is common knowledge that increasing soil

fertility with animal manure also increases the quantity of fecal coliform bacteria in the

water. Therefore, excessive fecal coliform bacteria levels and other pathogens can

contaminate surface and groundwater when animal dung is improperly handled or

applied[25]. Surface water, such as streams and rivers, can be contaminated by runoff

from feedlots and farms, and groundwater can be affected by pollutants that seep

through the soil layers. People and animals may be exposed to toxins while using

contaminated groundwater for irrigation or drinking. Different management techniques

can be used to reduce the amount of water pollution caused by agricultural activities.

Among these include reduced use of pesticides and fertilizers, conservation tillage,

nutrient management programs, and manure management strategies. Additionally, by

creating buffer strips or wetlands or increasing irrigation effectiveness, runoff can be

reduced and contaminants in surface water can be filtered[26]. Water sources may be

impacted by pesticides, herbicides, and fungicides used in agriculture. It is well

recognized that these agricultural contaminants deteriorate groundwater and surface

water quality[27]. Using contaminated irrigation water and disposing of animal corpses inappropriately are two other poor farming techniques that could cause coliform

contamination[28]. Rainfall and flooding are other causes of water contamination.

They accomplish this by introducing potentially harmful chemicals and contaminants

into water sources from a variety of sources. Studies conducted in the lab and in the

field indicate that there are significant numbers of bacteria in water, which are

primarily brought on by frequent tidal floods and strong rain events[29]. Inadequate

water consumption spurred on by population increase, urban wastewater runoff,

hospital waste, and institutional waste are other causes of coliform contamination of

water[21].

Poor hygiene habits, such as defecating outside, and poorly maintained wells that have

free access make them more susceptible to anthropogenic pollutants[30]

### 2.4 The significance of finding Coliform bacteria in water

Monitoring is the primary line of defense against diseases brought on by dangerous

microbes. Effective detection techniques are required to manage this effect[31].

To determine whether there are any pollutants in the water, accurate and quick reaction

detection technologies are required[32]. Water safety and cleanliness are basic human

rights and needs for all living beings[33]. The three most basic uses of water—drinking,

food preparation, and personal hygiene—require each person at home to use 7.5 liters

of water per day at least. A minimum water consumption of 50 liters per person per

day is necessary to meet the requirements for personal hygiene, food hygiene,

housekeeping, and laundry purposes[34]. However, due to its importance as a way of

propagating pathogenic organisms, man is now worried and terrified of it[35]. Animal

and human waste is a significant contributor to water pollution, which is extremely

hazardous to the health of millions of people worldwide. Waterborne illnesses like

cholera, polio, diarrhea, hepatitis, typhoid, dysentery, and gastroenteritis are brought on by these microorganisms that contaminate the water supply[36]–[38]. One of the

top 15 global killers is diarrheal disease[39]. More children die from diarrhea than from

tuberculosis and malaria combined[34]. Millions of people globally are afflicted by

other ailments linked to WASH. Over 800,000 deaths are attributed to inadequate

WASH each year, particularly among children under five[40]. Elderly and young

people often suffer more from the harmful health effects of drinking water

contaminated with E. coli[41]. The difficult work of assessing and analyzing the

microbiological features of water in rural developing areas is one of the major barriers

to promoting and implementing safe water projects. Many remote populations lack the

necessary tools and knowledge to evaluate the microbiological purity of water before

using it. Despite the large number of hazardous microbes, testing for all of them is

challenging[42]. To reduce dependence on laboratory testing and overcome the

challenges of cost, logistics, and time delays associated with sending samples offsite

for analysis, especially in remote areas lacking reliable access to electricity or nearby

laboratories, there is a strong demand for simpler, faster, and cost-effective methods

that enable frequent water testing at the community or household level.[43]

### 2.5 Traditional methods of detecting Coliform in water

Drinking water is an oligotrophic system, thus the inability of culture methods to

recognize starved and stressed bacterial cells could have serious repercussions by

drastically underestimating contamination levels. There are other alternative methods

for recognizing coliforms, albeit they are all at different stages of development and

implementation. In this overview, cutting-edge and new methodologies are discussed

alongside the fundamental principles and accepted practices of traditional methods of

Coliform detection. Additionally, based on each method's benefits and drawbacks, the

efficacy of finding coliforms in oligotrophic environments, such drinking water, is assessed. Additionally, criteria like detection sensitivity and limit, amount of time

needed to collect data, and laboratory costs are taken into account (including skill,

labor, and cost)[4].

Traditional methods include membrane filter method, multiple-tube fermentation

method, enzymatic/defined substrate method and molecular methods.

### 2.5.1 Membrane filter method

The membrane filter method is one way for calculating the quantity of microorganisms

in drinking water which has achieved acceptance in a number of countries. Membrane

filter technology is used to keep an eye on water quality. This method comprises

running a water sample through a 0.45 mm-pore filter that is sterile and bacteria-

retentive. After the filter has been cultivated on a selective medium, the typical colonies

on the filter are then counted. To find the optimum method for recovering coliforms

from water samples, various media and incubation conditions were examined. The

Tergitol-TTC medium and the m-Endo-type media, respectively, are frequently used

for drinking water analysis in North America and Europe[44]. After 24 to 48 hours of

incubation, coliform bacteria form yellow-orange colonies on Tergitol-TTC media,

whereas they create metallic-looking red colonies on an Endo-type medium that

contains lactose. While studies indicate that m-Endo agar is associated with greater

efficacy in cultivating higher quantities of coliforms, alternative media like

MacConkey agar and Teepol medium have been utilized in South Africa and the United

Kingdom. In the determination of fecal coliform counts, filters are commonly

incubated for 24 hours at 44.5°C on an enhanced lactose medium known as m-FC[44].

### 2.5.2 Multiple-tube fermentation technique

Over the past 80 years, the multiple-tube fermentation (MTF) approach has become a

popular methodology for enumerating coliforms and monitoring water quality. In this method, multiple test tubes containing various dilutions of the water sample are

employed. The occurrence of gas generation, acid formation, or noticeable growth in

the test tubes after a 48-hour incubation period at 35°C indicates a positive presumptive

reaction. Both lauryl tryptose broths and lactose broths can serve as presumptive media.

Confirmation tests are conducted on all tubes once a positive presumptive result is

observed. To pass a confirmation test, a brilliant green fermentation tube containing

lactose-bile broth must exhibit gas production within 48 hours at 35°C[4].

The multiple tube fermentation method outcomes are expressed using the most

probable number (MPN), which is a statistical estimation of the mean number of

coliforms. Using this technique, it is possible to determine the coliforms semi-

quantitatively. The measurement's level of precision is poor because few tubes were

used for the analysis. The likelihood of getting a negative result when using five tubes,

each with a volume of 1 ml of the material, is less than 1%.

Despite its limitations, the MTF technique is still widely used and a good way to check

water quality. Some of its benefits include simplicity and low expense. However,

compared to the defined substrate approach, this technique has a significant

disadvantage due to its lengthy incubation period. The MTF technique is a vital

instrument for ensuring the safety of drinking water because it can identify both total

and fecal coliforms. However, the MTF technique's lack of accuracy, brought on by its

reliance on statistical estimates, raises the possibility that it may not be the best

technique in circumstances where high precision is required. Alternative approaches

with higher accuracy, like PCR-based techniques, may be preferred in such cases.[4]

### 2.5.3 Molecular methods

There are currently several molecular techniques available that enable rapid,

sensitive, and precise identification of pathogenic microorganisms in clinical samples and assessment of the microbiological safety of food and water. These methods have

been developed and refined over the past two decades. Unlike traditional approaches

that involve isolation and cultivation of microorganisms, these molecular techniques

allow for qualitative and quantitative analysis of the target microorganism without the

need for growth. Moreover, these methods can be customized to detect specific

pathogenic traits carried by the microorganism. Various target molecules can be

utilized, and the ultimate objective of these techniques is to provide valuable insights

for the prevention of infectious diseases[45]. The following are the molecular

techniques used to find coliforms in drinking water

1. Polymerase chain reaction method

The polymerase chain reaction (PCR), a method that is frequently used to make

millions to billions of copies (full or partial) of a given DNA sample, allows researchers

to quickly amplify a very small DNA sample (or a portion of it) to a huge enough

quantity to analyze in depth.[46]. An amplified DNA target segment can now cycle

through replication thanks to this reaction. Oligonucleotide primers are used for

replication in a chain reaction that is started by a DNA polymerase, specifically Taq

polymerase. Both in vitro and in situ replication methods are possible. The degree of

complementarity and homology between the target sequence and the primer, as well as

the temperature at which hybridization occurs, affect the sensitivity of the detection

method.[44]. By using gene probe detection and PCR amplification of particular

portions from two genes, lacZ and lamB, the identification of coliform bacteria was

investigated. Salmonella spp. and non-coliform bacteria were not found when

Escherichia coli's lacZ coding area was amplified using PCR primers with an annealing

temperature of 50 degrees C. However, this technique was successful in detecting

Shigella spp. as well as other coliform bacteria. The identification of Salmonella,

Shigella, and E. coli species was accomplished by selectively amplifying a segment of

E. coli lamB at an annealing temperature of 50 degrees C[47].
2. Nucleic Acids

For accurate identification of certain phylogenetic sources and species identification,

DNA and RNA, particularly nucleic acid polymers, are very suitable molecular targets.

Numerous molecular techniques for coliform detection have been developed thanks to

the stable genotype properties of nucleic acids[45]. Coliforms in drinking water must

be found in order to protect public health, and nucleic acid-based molecular methods

has established itself to be a quick, sensitive, and reliable way to do so[44]. Overall,

nucleic acid-based molecular approaches provide a number of advantages over

traditional culturing methods in order to recognize coliforms in drinking water. They

don't require labor- or time-intensive culturing methods and can identify coliforms

rapidly and precisely. These techniques are essential because they reliably identify the

presence and amount of coliforms in water samples, protecting public health, and

preventing the spread of infectious diseases [44].

2.5.4 Enzymatic method/defined substrate method.

The Colilert-18 is one of the most often used defined substrates for the enzymatic test

because it contains the nutritional indicators ONPG and MUG from Defined Substrate

Technology (DST), which establishes E. coli and Coliform bacteria presence. The US

EPA has authorized the reagent as a routine procedure for evaluating treated and tainted

water since it may deliver results in just 18 hours. With the use of this reagent, you

may attain 100% test accuracy. Colilert-18 reagent will be entirely soluble in water

after being shaken into water samples[48]. Other efficient substrates, such those created

by the Italian business Liofilchem, are already on the market and are good indicators

of coliform in water. Incubation of samples is done for 18–24 hours at 37°C or close to 48 hours at room temperature (20–25°C)[49]. Coliforms have the enzyme β-

galactosidase, which they use to create gases and acids when the temperature is

between 35 and 37 °C, which is ideal for growth[50]. A certain enzyme will produce

color or fluorescence when it digests a chromogenic or fluorogenic substrate. These

substrates have been used to determine whether or not certain enzymes are present or

active in water. To detect the existence of b-D-glucuronidase in E. coli, scientists

employed a chromogenic substrate called indoxyl-b-D-glucuronide (IBDG). Various

commercial tests based on this specific substrate technology were subsequently

created, such as Colilert (IDEXX Laboratories, Portland, ME, USA), Colisure

(Millipore Corporation, Bedford, MA, USA), and Coli-Quick (IDEXX Laboratories,

Portland, ME, USA) (Hach, Loveland, CO, USA)[4].

### 2.6 Internet of Things (IOT): A Quick Overview

The phrase "Internet of Things" (IoT) refers to a network of physical things that are

integrated with sensors, software, and other technologies, enabling them to connect and

communicate with other devices and systems via the internet without requiring human

intervention. These devices cover a wide range of products, from standard domestic

appliances to cutting-edge industrial machinery[51]. These objects have the ability to

perceive, communicate, interact, and function together without requiring human-to-

human or human-to-computer interaction thanks to integrated technology and a

network of physical objects[52]. IoT is about more than just connected devices; it's also

about the data those devices gather and the immediate, potent insights that can be drawn

from it [53]. Internet of Things (IOT) increases productivity since it reduces reliance

on humans[54]. This program has been used to develop programs for monitoring

ranging from surveillance, healthcare, and the environment all around the world[55].

### 2.6.1 Structure of the Internet of Things (IOT)

Sensors, microcontrollers, and application platforms make up the IOT architecture.

1. Sensors

IoT sensors track environmental changes in real time by detecting the physical

environment[56]. IoT sensor networks' main objectives cover three areas: (i) gathering

important data from the outside physical world; (ii) sampling internal system signals;

and (iii) using sensor data to deliver appropriate information for decision-making[56],

[57]. These sensors have nodes built in that are linked to microcontrollers that are in

charge of reading and analyzing the data collected by the sensors. The most often used

IoT sensors are those that measure temperature, pressure, humidity, level,

accelerometer, gas, gyroscopes, motion, picture, and optical properties, as well as RFID

(Radio Frequency Identification) and infrared (IR) sensors[56]. The small size of the

sensor causes technical restrictions in areas like computational power, networking

ability, battery life, storage capacity, and memory, despite the fact that sensors have a

wide range of applications. This means that these sensors could be very vulnerable to

errors, assaults, and simple failure, which could lead to the loss of sensor data and

erroneous information[56].

2. Microcontroller

A microcontroller is a small computer with network access and program execution

capabilities. The controller manages the collection of numerical data from the sensors,

which it can then upload to the cloud or the internet for storage and analysis[58], [59].

Minicomputer- and microcontroller-board-based IoT controllers can be distinguished

from one another. Microcontrollers like Arduino are more affordable than

minicomputers and can run the same program repeatedly. The ESP is an additional

instance of a microcontroller (ESP32, ESP8266). As an alternative, portable, full-featured computing devices that are capable of handling a variety of tasks include

minicomputer-type controllers like the Raspberry Pi. While an Arduino board requires

additional external hardware in order to link up with the internet, the Raspberry Pi

comes with an Ethernet and Wi-Fi network interface built in[59].

3. Application Platform

Without applications, IOT is of no meaning. Applications for Internet of Things

provide reliable communication and real-time message transmission. An application is

essentially a piece of software that runs online and, after receiving input from a

microcontroller, displays data via a user interface. Platforms such as Blynk offer

mobile applications that enable the management and monitoring of IoT devices via

mobile devices. Additionally, FreeBoard, Ubidots, and ThingSpeak are three other

well-known platforms utilized for IoT applications [59].

Figure 2.2: IoT Analytics Flow [60]

### 2.6.2 IOT's relevance for detecting bacteria in water and its utility in

detecting coliform

Water samples and the data that go with them are often processed and examined in

laboratories. This may take a lot of time and effort and result in less trustworthy results.

In light of the situation, it is essential to establish a suitable and organized system for

continuous monitoring and management of water resources in order to address

connected challenges. Internet of Things (IoT) enables the collection of real-time

remote measurements which may be conducted with little to no human participation,

providing a great alternative to conventional, complicated, and unsuccessful techniques

for reaching this goal[61]. Due to the harmful health implications of consuming

contaminated water, real-time monitoring of water quality is now required. IoT domain

addresses this problem by providing creative and reasonably priced solutions for the

problems of water contamination detection and water quality analysis[62].

The following are some benefits of using IOT for water quality monitoring:

1. Decreased cost of computing: The considerable amount of computing work,

like that required by the Ubidots IoT-Platform, is handled by cloud servers.

With the passage of this law, any widely used processor-based node (such as

the NodeMCU (ESP32) kit) may be used in place of sophisticated

microprocessors[63].

2. Hardly any human involvement: IOT systems can increase efficiency by

reducing reliance on humans[64].

3. Low cost: IoT solutions are generally more cost-effective than traditional water

monitoring techniques since they make use of currently in use, commercially

available communication infrastructure, which is also more time-

consuming[63].

### 4. Low power requirements: The local nodes only need to carry out minimal work

after shifting the majority of the computing workload to the cloud server, and

they can then primarily sleep. This made it possible to operate sensor nodes in

far-off places with a little battery.

5. Real-time feedback delivery: The proper water authority and end users can both

immediately receive real-time input from these systems via SMS, email,

Twitter, Facebook, and other means[63].

### 2.7 Review of related works

This section analyzes experiments that involved the development of an improvised

incubator for coliform growth in contaminated water samples as well as the

identification of coliform and other types of bacteria in water using Internet of Things

(IoT) technology. The next paragraphs concentrate on a few of the numerous research

studies that have been carried out in this field.

A sensor-based Water Quality Monitoring System was employed in another study[52]

to measure the water's molecular and physical properties, including its pH, temperature,

turbidity, and Total Dissolved Solids. (TDS). The authors' IoT-based solution consisted

of three crucial components: a multiparameter water quality analyzer, a means for

information transmission, and a computer system unit. Sensors, Wi-Fi wireless

transmission, an STM32 single chip microcontroller, and remote water quality

monitoring were all included in the proposed system. The data on water quality

collected were evaluated using ANOVA-based statistical analysis to identify the key

causes of the river Krishna's deteriorating water quality. The authors used a water

quality monitoring system based on the Internet of Things (IoT) to gather and evaluate

current data on the river Krishna's water state in order to identify the primary causes of

water contamination.

IoT-based technique for predicting bacterial contamination in water was proposed by

the authors of a study paper[61]. The setup entails placing a variety of equipment in

the study area, including sensors for determining total dissolved solids, pH level,

turbidity, and dissolved oxygen. These tools are used to evaluate and keep track of the

water's quality. These sensors transmit the data they have collected to a server using

GSM modules, where it is processed and examined. The scientists used machine

learning methods to predict coliform bacteria presence in the water based on the sensor

data collected by the IoT system. The proposed approach provides a more useful and

cost-effective alternative to manual lab analysis, which is an expensive and time-

consuming process for the prediction of bacteria. To predict coliform presence bacteria

in water, the authors created an IoT-based system that uses a variety of sensors and

machine learning techniques, providing a quick and cheap alternative to traditional lab

examination.

An incubator powered by batteries that effectively sustains a temperature range of

approximately 35°C with a tolerance of ±1°C of 25°C for up to 65 hours is described

in another study[65] free, open-source design. The objective of this incubator is to

provide humanitarian engineers with a quick, simple, and visually pleasing method to

evaluate the quality of microbes in water in remote locations. To confirm the presence

of E. coli in the water samples, the authors used 3M Petrifilm E. coli/Coliform (EC)

Count Plates. These dishes need to be incubated at a temperature that is in close

proximity to body temperature. In order to meet this need, the portable incubator was

developed, and the authors demonstrate that it can maintain the required temperature

range for up to 65 hours. However, the use of IoT in the research is not acknowledged

by the authors. As has been shown, IoT has the ability to improve water quality

monitoring in various ways. Using temperature, pH level, dissolved oxygen, and turbidity as an example, Internet of Things (IoT) sensors can provide real-time

information about these factors that affect water quality. This data may be sent to a

database for adequate analysis and visualization, allowing for swift and educated

decision-making. Additionally, IoT can allow remote water quality monitoring, doing

away with the need for labor-intensive manual analysis.

In a different study, the writer used IoT to monitor and track the water quality in real-

time[58]. They suggested a system that uses IoT sensors to measure pH, temperature,

and turbidity in addition to other elements of water quality for use in homes. The

system's objective is to offer remote internet access for managing and evaluating water

purity, for instance through a mobile application. The proposed system uses Big Data

Analytics and Machine Learning techniques to analyze water quality data in-depth,

allowing the early detection of threats. In conclusion, the research's authors used IoT

sensors and big data analytics techniques to measure and track water quality in real

time, making it possible to identify risks early enough to prevent them and to manage

water quality remotely.

In a different study[48], the authors developed a portable incubator for the development

of coliform and E. coli germs using IoT technology. With the aid of this portable

incubator, microbiologists can evaluate the quality of the water anywhere—not just in

laboratories. Using qualitative and quantitative techniques, the incubator is able to

identify E. coli in water samples as well as coliform bacteria. Two-factor authentication

security enables real-time tracking, and the incubator can cut the detection period to

just two hours. (2FA). The capability of the device to reach and maintain a

predetermined temperature (typically 35–37°C) under various conditions, a procedure

known as bacterial growth, determines the device's dependability. The incubation

procedure can be carried out manually or automatically via Internet of Things (IoT)

technology and computer vision. Data is protected by encryption techniques in the

incubator, and the connection between the device and Wi-Fi is also secure. The

outcomes of their experiment can also be observed in real time using IOT apps. In

conclusion, the researchers developed a movable E. coli and coliform bacteria

incubator using IoT technology that can identify the presence of these bacteria in water

samples using both qualitative and quantitative techniques. Because it is dependable,

secure, and can cut the detection time to just two hours, the incubator is an essential

tool for microbiologists to use when conducting water quality checks all over the world.

In a different study[66], the authors describe a method for building a movable,

affordable incubator for drinking water microbiological testing. The incubator

prototype can be modified to handle different materials as well as volumes and has a

disassemblabe design that makes carrying it easy. This may be used in grid-powered,

laboratories as well as remote areas with solar or automobile batteries. The design uses

components that are typically available, can work in a variety of outdoor settings, and

maintains the advantages of more expensive laboratory-based models. In order to

assess the microbes in drinking water, the writers wished to address the need for a

portable, affordable incubator. A variety of culture-based microbiological techniques,

including membrane filtration and culturing, are used to determine if water is fit for

human consumption, can be used in the incubator. Overall, the authors' work suggests

that their design may provide a practical and affordable alternative for the incubation

of microbial colonies in the lab and the field. Their approach has the potential to be

extensively applied in low-resource areas where it may be difficult to obtain specialized

equipment. However, they did not incorporate any kind of IOT into their architecture.

The authors of another study [67] proposed a low-cost light detecting unit-based

turbidity instrument for monitoring water cloudiness. The system makes use of an Intel

Galileo 2 processor and a server for web-based tracking. The Turbidity Detection Unit

is made up of a polyvinyl chloride (PVC) conduit, and a Light Emitting Diode (LED),

a Light Dependent Resistor (LDR). The turbidity system relies on the idea that the

amount of suspended matter and the amount of light it dissipates are directly correlated

The authors propose a clever Internet of Things (IoT)-based system for monitoring

water quality indicators in another research publication [68]. The device is designed to

monitor four physical water quality parameters: Turbidity, temperature, electric

conductivity, pH. An Arduino microcontroller, Sensors, an ESP8266 Wi-Fi module,

and a cloud database for data storage and analysis make up the proposed system. The

device operates by using sensors to collect data from the water sample and transmit it

to the Arduino. Using the ESP Wi-Fi module, data is analyzed by the microcontroller

and sent to a cloud database. To furnish valuable insights into water quality, the

collected data is saved and examined in the cloud database. The recommended system

is effective and economical and can be used for real-time monitoring of water quality.

The overall suggestion of the research paper is to put in place a smart water quality

monitoring system that implements IoT to constantly track important water quality

indicators. This technique can help reduce potential contamination exposure while

ensuring the availability of clean potable water sources.

### 2.8 Summary

This study investigates ongoing and completed projects that are relevant to the subject

at hand. By analyzing these projects, it has been possible to identify enhanced and more

efficient approaches specifically related to the project being examined.

### 3. CHAPTER THREE

SYSTEM ANALYSIS AND DESIGN

### 3.1 Introduction

This section provides a comprehensive review of the materials, tools, and designs

utilized to complete the development of the portable incubator. It offers a detailed

explanation of the project's programming, circuit design, and construction methods,

including a discussion of the components chosen and the reasoning behind those

choices. The chapter also showcases the project's flowchart and algorithm and

includes information on the methodology and calculation employed during the

building process.

### 3.2 Components

This project employs three categories of components: electrical, mechanical, and

chemical. The electrical components encompass a Light Dependent Resistor (LDR), a

DHT11 temperature and humidity sensor, a relay, an ESP32 microcontroller, an LED

bulb, a 220-12V (AC-DC) power adapter, a buck converter, a Liquid Crystal Display

(LCD), and a potentiometer. The mechanical components consist of the incubator and

the beakers utilized for holding the water samples under investigation. The chemical

component pertains to the substrate named water detect coliform.

### 3.2.1 ESP 32

The ESP 32 is an affordable microcontroller that has Wi-Fi and dual-mode Bluetooth

built-in. It acts as both the microcontroller and Wi-Fi module, controlling the relay

switch and interfacing with sensors. When connected to a Local Area Network

(LAN), it enables real-time access to readings through the Blynk platform.

Figure 3.1: Expressif Systems Processor (ESP) 32

### 3.2.2 Light Dependent Resistor (LDR)

This is also known as a photo resistor, photocell, or photoconductor, is a sensor that

responds to light changes by altering its resistance. When light falls on an LDR, its

resistance changes. The light intensity reaching the LDR is inversely proportional to

its resistance. The LDR is used to detect the turbidity levels of the water sample being

tested. Due to the water sample being clear initially, more light reaches the LDR,

causing a decrease in its resistance. However, if the water sample contains coliform

bacteria, after approximately 16 hours of incubation, it turns blue. As a result, the

LDR receives less light, causing an increase in its resistance value.

Figure 3.2: Light Dependent Resistor (LDR)

### 3.2.3 Relay

A relay is an electronic device that can be switched on or off when an external

voltage (AC or DC) is applied across its control terminals. In this project, the relay is utilized to control the heating pad, which helps maintain the desired temperature

range of 35-37℃ inside the incubator. The heating pad is connected to the relay,

which is in turn connected to the ESP32. The ESP32 turns the relay on or off based

on the temperature readings obtained from the DHT11 sensor, thereby regulating the

temperature inside the incubator.

Figure 3.3: Relay

### 3.2.4. DC-DC Buck Converter

A DC-DC converter is an electronic device that can increase or decrease voltage of a

direct current power source to match a desired voltage level. In this project, a 5V

buck converter is used to step down the voltage from the 220V AC to 12V DC power

adapter to the 5V level needed to power the various components of the system.

Figure 3.4: DC-DC Buck Converter

### 3.2.5 PTC Electrical Heating Element

The incubator utilizes an electrical heating pad as its source of heat, which is

controlled by the relay. The relay is triggered on and off by the microcontroller,

depending on the temperature readings from the DHT11 sensor. The heating pad

plays a crucial role in maintaining the temperature range required for the coliform

bacteria's optimal growth in the water samples, which is between 35-37℃.

Figure 3.5: Heating Source

### 3.2.6 LED Bulb

The LED bulb is used as the lighting source. It supplies the LDR with the sufficient

light required to determine the turbidity levels of the water samples.

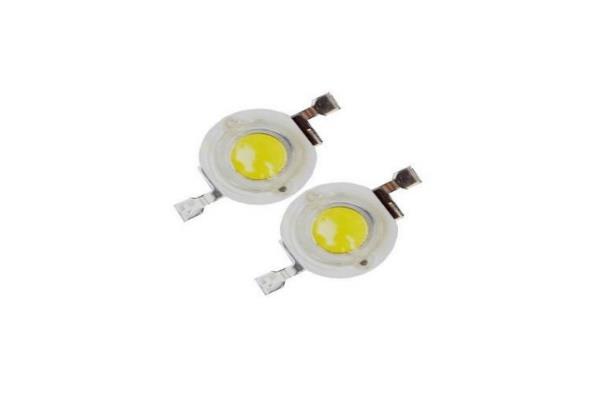
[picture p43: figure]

Figure 3.6: LED Bulb

### 3.2.7 DHT11 Temperature and Humidity Sensor

The DHT11 sensor is utilized to obtain data on the temperature and humidity levels

within the incubator. Its significance lies in ensuring that the temperature remains

within the 35-37℃ range. The ESP32 is connected to this sensor for interfacing

purposes.

Figure 3.7: DHT 11

### 3.2.8 Liquid Crystal Display (LCD)

For this project, a 20x4 (20 characters, 4 rows) LCD display is utilized to provide a

user-friendly interface for monitoring real-time data readings from various sensors.

The LCD display effectively shows temperature and humidity levels within the

incubator, as well as the resistance readings of the Light Dependent Resistors. It is

interfaced with the ESP32 microcontroller to display the data readings on the screen.

The real-time data presented on the LCD enables users to monitor the progress of the

incubation process and ensure the optimal conditions necessary for the growth of

coliform bacteria.

Figure 3.8: Liquid Crystal Display

### 3.2.9 I2C Serial Interface Adapter Module

The LCD 20x4 display used in this project is connected to the ESP32 microcontroller

using I2C communication protocol. This allows for a simpler and more efficient data

transfer between the microcontroller and the LCD display. The I2C interface reduces

the number of pins required for communication, making it easier to interface with

other components in the project.

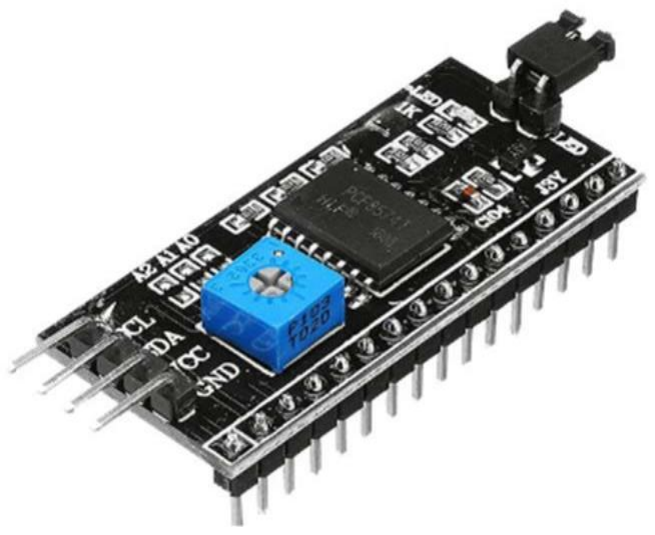
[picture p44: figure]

Figure 3.9: I2C Serial Interface Adapter Module

### 3.2.10 Incubator

The incubator is an essential tool in detecting Coliform bacteria in water samples. Its

importance lies in its ability to provide a controlled environment that promotes the

growth of Coliform bacteria, necessary for their detection. The incubator ensures

accurate and reliable results by maintaining constant temperature and humidity

conditions, reducing the risk of false negatives. Additionally, the use of an incubator

provides a standardized procedure for Coliform detection in water, allowing for

consistent comparison of results across various samples and testing centers. In

summary, the incubator is a critical component in the detection of Coliform in water,

offering a dependable and consistent method for bacteria growth and detection.

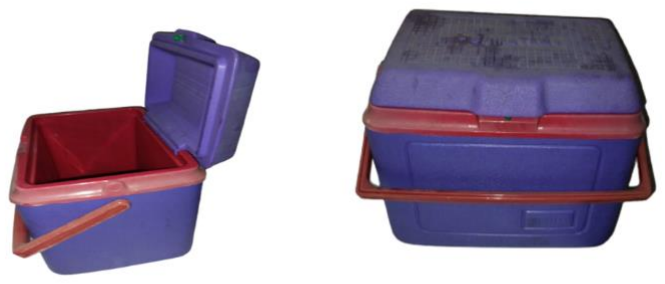
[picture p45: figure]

Figure 3.10: Incubator

### 3.2.11 Beaker

The beakers are utilized to contain the water samples for testing. They are transparent

and enable light to pass through the water sample to the LDR. Additionally, they have

markings that allow for accurate measurement of the volume of water being tested in

milliliters (ml).

Figure 3.11: Beaker

### 3.2.12 Water Detect Coliform Powder

The chemical being used for detecting coliform bacteria in water samples is a crucial

component of our project. It is the only substance capable of detecting the presence of

coliforms, which generate acids and gases through β-galactosidase enzyme activity at

their optimal growth temperature of 35-to-37-degree Celsius(°C). The chemical

works by breaking down a chromogenic or fluorogenic substrate, resulting in the

production of color or fluorescence. Specifically, the powder changes the color of water samples from a clear and transparent appearance to a dark greenish hue,

indicating the presence of coliforms. This color change is important for our project as

it allows the Light Detecting Resistors to detect a decrease in light intensity when the

water changes color, which indicates the presence of coliforms in the sample.

Figure 3.12: Water Detect Coliform Powder

### 3.2.13 Power Supply Adapter

The incubator's components are powered by a power supply adapter, which includes a

rectifying circuit that converts a 220V AC power supply to a 12V DC power supply

suitable for our components.

Figure 3.13: Power Supply Adapter

3.2.14 10k resistors

In order to convert the resistance reading of the LDR into a measurable voltage

signal, we can create a voltage divider circuit by combining the LDRs with fixed

resistors. This circuit allows us to obtain a proportional voltage output corresponding

to the LDR resistance, which can then be accurately measured by the ESP 32

Additionally, when using the DHT11 sensor, it can be utilized as a pull-up resistor.

The purpose of the pull-up resistor is to prevent the pins from floating in an

undefined state. By providing a defined state to the resistor, we ensure consistent and

reliable data transmission and reading from our respective sensors.

Figure 3.14: 10k resistors

### 3.2.15. Polyethylene foam

This consists of a thermoplastic polymer that is lightweight in nature. Its purpose is to

enhance the thermal efficiency within the incubator by providing excellent thermal

insulation characteristics. The foam is applied to both the walls and the base of the

incubator, acting as padding.

Figure 3.15: Polyethylene foam

### 3.4 Description of Software Requirements

The programming of the entire system will be done using the Arduino C/C++

language on the Arduino Integrated Development Environment (IDE), followed by

compilation and uploading to the microcontroller. The software required for this

project is outlined below.

### 3.4.1 Arduino Integrated Development Environment (IDE)

This software is open-source and streamlines the process of programming and

uploading code to the microcontroller board. It can be used on different operating

systems such as Windows, Mac OS X, and Linux. The user interface was developed

using Java and free and open-source tools like Lua Processing. Our project's Arduino

board programming is written in C++, and the IDE software translates our readable

human program codes into machine language. Before uploading to the

microcontroller board, the IDE checks the source code for errors to ensure proper

functionality.

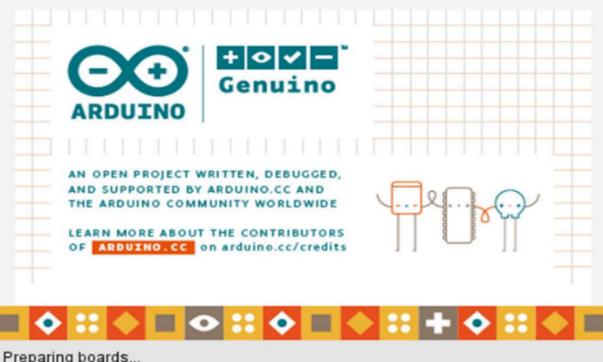
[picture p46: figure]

Figure 3.16: Arduino Integrated Development Environment (IDE)

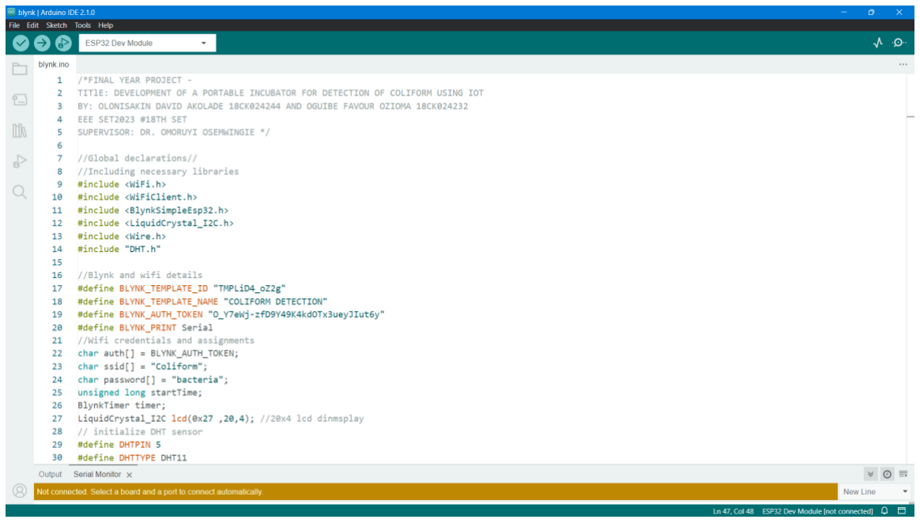
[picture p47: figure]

Figure 3.17: Arduino Integrated Development Environment (IDE) Code Snippet

### 3.4.2 Blynk

Blynk is a versatile platform that enables users to create mobile applications that

control and monitor devices over the internet. One of the key advantages of Blynk is

its user-friendly interface, which makes it easy for users to monitor and control

various IoT devices from their smartphones. In this particular project, Blynk offers a

significant role in facilitating remote monitoring of the incubator's temperature and

water quality parameters using a mobile device.

By integrating the ESP 32 with the Blynk platform, users can remotely monitor the

temperature of the incubator and the water quality parameters in real-time. Blynk also

allows users to set up alerts and notifications that can be sent to their smartphones if

the temperature or water quality parameters fall outside the acceptable range. This

feature ensures that users can respond quickly to any deviations from ideal conditions

and prevent damage to the organisms being cultured in the incubator.

In summary, Blynk's user-friendly and convenient interface makes it an ideal

platform for remotely monitoring and controlling the incubator's temperature and

water quality parameters. By using Blynk in conjunction with the ESP 32, users can

ensure that optimal conditions are maintained for the organisms being cultured in the

incubator.

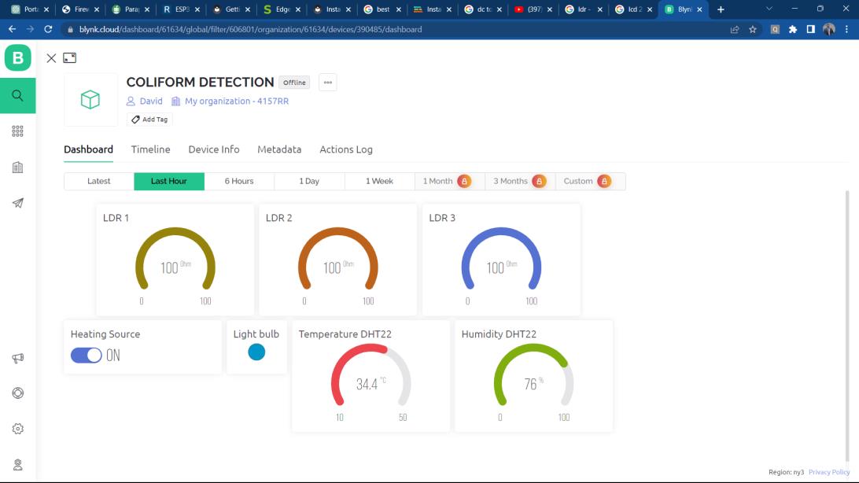
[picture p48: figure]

Figure 3.18: Blynk Application

### 3.3 Design specification

### 3.3.1 Systems Block Diagram

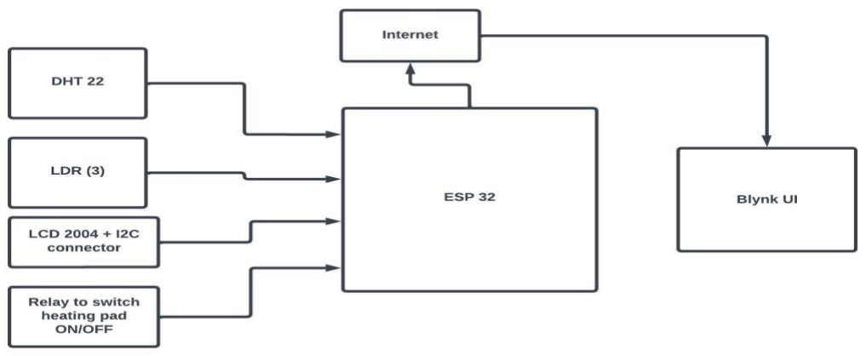
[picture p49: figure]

Figure 3.19: Systems Block Diagram

### 3.3.2 Circuit Diagram

Figure 3.20: Circuit Diagram

### 3.3.3 Systems Algorithm

The project's algorithm is the series of procedures taken to solve the problem with

code and create a working system. The following actions were conducted in the

following order according :

1. Initialize the portable incubator system.
2. Set up the light-dependent resistor (LDR) sensor and connect it to the

microcontroller (ESP32).

3. Connect the Digital Humidity and Temperature (DHT11) sensor and the

heating element to the microcontroller.

4. Configure the incubator system to maintain a temperature range of 35-37°C

for optimal coliform bacteria growth.

5. Display the resistance and temperature readings on the Liquid Crystal Display

(LCD) screen.

6. Collect water samples to be tested for the presence of coliform bacteria.
7. Place the water samples in the incubator system and close it to create a

controlled environment.

8. Activate the LDR sensor to detect changes in turbidity, indicating the

presence of coliform bacteria.

9. Continuously monitor the resistance readings from the LDR sensor.
10. If the resistance readings indicate a significant change in turbidity, record the

data.

11. Use the DHT11 sensor and heating element to maintain the appropriate

temperature during the incubation process.

12. Continuously monitor the temperature inside the incubator system.
13. Transmit the collected data from the microcontroller to the Blynk application

for real-time monitoring and analysis.

14. Ensure the data transmission to the Blynk application is successful.
15. Analyze the data in the Blynk application for coliform bacteria detection and

monitoring.

16. Provide alerts or notifications through the Blynk application if coliform

bacteria presence is detected.

17. Repeat the process for each water sample, allowing for continuous monitoring

and analysis.

### 3.3.4 Systems Flowchart

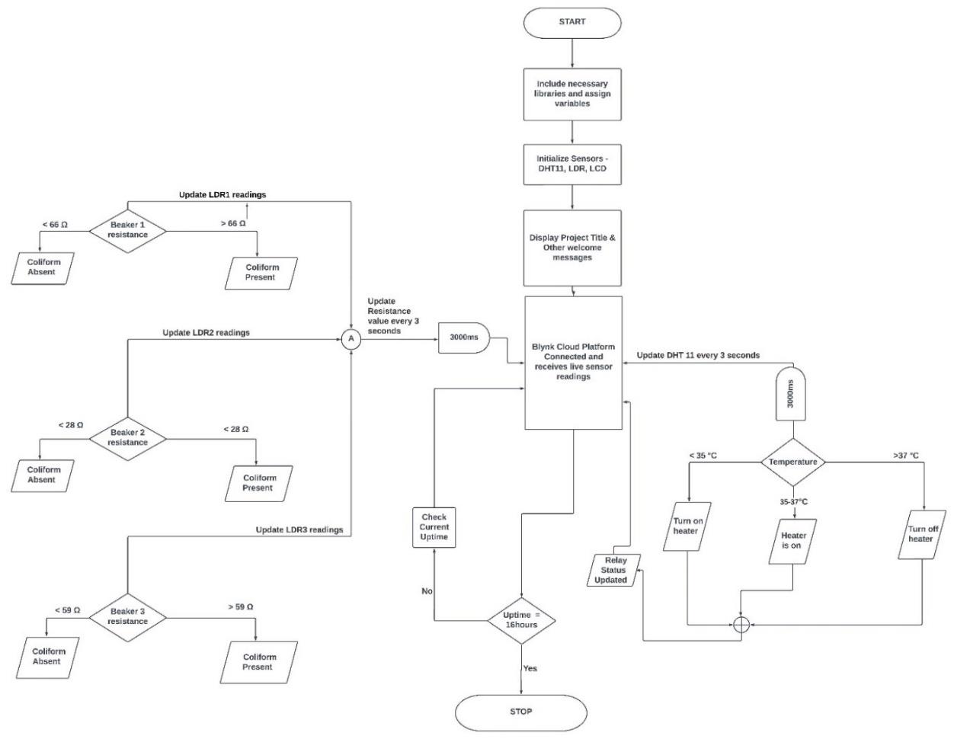
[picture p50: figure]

Figure 3.21: Systems Flowchart

### 3.3.5 Electrical Calculations

Heat transfer calculations

In order to determine the suitable power rating for the heating element necessary in

the incubator, it is crucial to take into consideration the amount of heat energy

required to elevate the temperature of both the water and air within the incubator to

the desired level. By utilizing the specific heat capacity formula,

Q = m × c × ∆θ | 3. 1

Where:

Q is the amount of energy (in joules)

m is the mass of water (in kilograms)

c is the specific heat capacity of water (in J/kg.k)

∆θ is the change in temperature (in kelvin, K)

There are three beakers in total, each containing 100ml of water, making a total of

300ml. Converting 300ml to mass gives:

Density =

Mass
Volume | 3. 2
Mass = Density × Volume | 3. 3

Density of water = 1g/cm³
or 1g/ml, therefore, mass of water in incubator = 1g/ml x

300ml = 300g or 0.3kg

The specific heat capacity of water is approximately 4190J/kg.k Assuming the initial

temperature of the water is room temperature 20°C (293k), and we want to raise it to

37°C (310k), ΔT would be 17kelvin. Therefore, the heat energy required to raise the

temperature of 100ml of water is:

Q = 0.1 kg * 4190J/kg.k * 17k = 7.123kJ

Since there are three beakers, the total heat energy required to raise the temperature

of all the water is:

Q_total = 3 x 7.123kJ = 21.369kJ

In addition to the water, it is important to factor in the heat energy needed to increase

the temperature of the air inside the incubator. To determine the quantity of heat

energy required for raising the temperature of a given volume of air, the following

equation can be employed:

Q = m x cp x ∆θ

Where:

m = mass of air

cp = Specific heat capacity of air

∆θ = change in temperature

The incubator has internal dimensions of 270mm x 140mm x 200mm. Therefore,

volume of incubator = Length x Breadth x Height = 0.27m x 0.14m x 0.2m =

0.00756m³
. We need to raise the temperature inside the incubator from 20℃ (293k)

to 35℃ (308k). ∆θ will be (308k – 293k = 15kelvin). The mass of air can be

calculated using the density of air (approximately 1.28 kg/m³
) and the volume of the

incubator:

Density =

Mass
Volume | 3. 2
Mass = Density × Volume | 3. 3

m = 1.28 kg/m³ * 0.00756m³ = 0.009677kg

The specific heat capacity of air is approximately 1005 J/kg·K. Therefore, the heat

energy required to raise the temperature of the air inside the incubator is:

Q = 0.009677kg * 1005 J/kg·K * 15 = 145.88J

The following amount of heat energy is needed overall to raise the temperature of the

water and air inside the incubator:

Qtotal = 21.369kJ + 145.88J = 21.514kJ

To calculate the power rating required for the PTC heating element, we also need to

consider the time it takes to raise the temperature. Let's assume we want to raise the

temperature in 20 minutes or 1200 seconds. Therefore, the power rating required for

the PTC heating element is gotten by using the formula

Qtotal = pt | 3. 4

P =

Qtotal
t

= 21.514kJ / 1200 = 17.9 watts ≈ 18 watts

Hence, a PTC element rated for about 18watts will be sufficient to raise the ambient

temperature in the incubator to 35-37℃ in 20 minutes. A lower rating heating

element could alternatively be used, as the polystyrene foam used to pad the walls of

the incubator will enhance insulation.

Table 3.1: Component Voltage and Current Values

Component | Voltage Draw | Current Draw
ESP 32 | 5v | 240mA
Relay | 5v | 160mA
Liquid Crystal Display (LCD) | 4.5v - 5.5v | 120mA
Heating Element | 12v | 1670mA
LED Bulb | 3.4v | 350mA
DHT 11 | 3.3v – 5.5v | 2.5mA

Hence, total current draw = (240 + 160 + 120 + 1670 + 350 + 2.5) mA = 2542.5mA

Therefore, a power adapter rated at least 3amps is needed.

### 3.5 Conclusion

This section provides a detailed overview of the construction process of this project.

It explains in detail the different components utilized, the circuitry, block diagrams,

algorithms, and flowcharts employed. Moreover, it describes the architecture and

techniques of the system, giving practical examples. The chapter also outlines the

implementation procedures, including the proposed model and the development

approach to be followed.

### 4. CHAPTER FOUR

RESULTS AND DISCUSSIONS

### 4.1 Introduction

This chapter presents the outcomes and analysis of the project, focusing on

significant discoveries and observations made during the implementation and testing

phases. The primary objective of the project was to develop an incubator system that

could detect coliform in water by controlling temperature and humidity within a

predetermined incubation period. To accomplish this, the incubator utilized several

components, such as an LDR sensor, a DHT sensor, a PTC heating element, an ESP

32 , and the Blynk IoT platform.

The chapter details the interconnection of the hardware components and provides a

step-by-step account of calibrating the LDR sensor. Accurate readings from these

sensors are crucial for drawing meaningful conclusions. It also covers the

configuration of the PTC heating element and the integration of the hardware

components with the Blynk platform.

Moreover, comprehensive testing of the individual subunits forming the complete

system was conducted to identify any design flaws that might have arisen during the

project's construction. The testing phase aimed to ensure the proper functioning of the

system while rectifying any potential errors.

### 4.2 Hardware Implementation

The interior structure of the incubator and the connectivity of all project-related

components are both crucial aspects. To ensure optimal thermal insulation, the inside

walls of the incubator were lined with polyethylene foam. This choice was made

because polyethylene foam possesses excellent properties for thermal insulation. Its

low thermal conductivity effectively inhibits heat transfer, minimizing heat loss to the

surroundings. By implementing this insulation, the energy needed to maintain the

desired temperature range is reduced, allowing for a consistent and regulated interior

temperature.

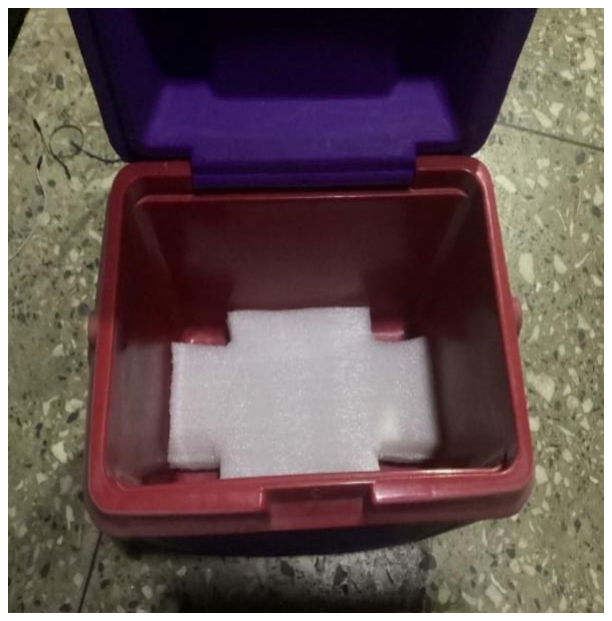
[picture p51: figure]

Figure 4.1: Inside of incubator with base padded with polyethylene foam

To provide padding for the base of the incubator, approximately four layers of foam

were applied. The foam was carefully cut along the edges to allow for the insertion of

the legs of the beaker stand.

Figure 4.2: Beaker stand

In order to expose the LDRs (Light Dependent Resistors) to the light emitted by the

LED bulb, holes were drilled into the stand. Additionally, a hole was created on the

side of the incubator to allow the wires to pass from the interior to the exterior. These

wires were then soldered to the other components through the use of a Vero board. To

ensure the desired temperature inside the incubator was maintained, the hole was

carefully sealed using hot glue applied with a glue gun.

Figure 4.3: LDR legs attached to base of beaker

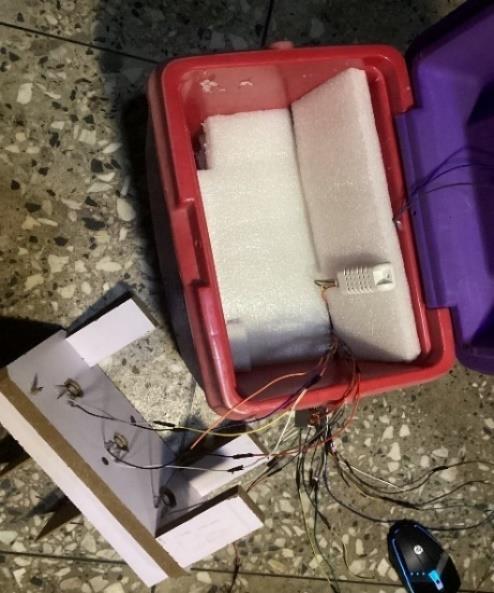
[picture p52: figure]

Figure 4.4: Internal image of incubator showing wiring to the outside

### 4.2.1 DHT 11 sensor and PTC heating element testing

The DHT sensor is of great importance as it provides accurate measurements of

temperature and humidity within the incubator. Maintaining a temperature range of

35-37℃ is essential for optimal growth of coliform bacteria in the water samples.

The DHT sensor consists of three pins: a signal pin, a Vcc pin, and a ground pin.

To establish a reliable data connection, the signal pin is connected to a pull-up

resistor and then to the ESP32 microcontroller. In the code, the DHTPIN is assigned

the value of 5, representing the specific GPIO pin number on the ESP microcontroller

to which the data pin of the DHT11 sensor is connected. This GPIO 5 pin serves the

purpose of receiving data from the DHT11 sensor.

The presence of a pull-up resistor is necessary to ensure the reliability of the received

data signal. When the DHT11 sensor is not actively transmitting data, the data line

may be left floating or uncertain, leading to potential data errors. By utilizing a pull-

up resistor, the data line is maintained at a defined, fixed voltage level, providing

stability and eliminating the impact of external disturbances.

Furthermore, the constant DHTTYPE is defined as DHT11, indicating the specific

type of sensor being used. To interact with the DHT11 sensor, an instance of the

DHT class named dht is declared using the constructor DHT dht(DHTPIN,

DHTTYPE). By passing the previously defined constants as arguments, the dht object

is properly configured to communicate with the DHT11 sensor connected to GPIO

pin 5.

In summary, this setup ensures the ESP microcontroller effectively retrieves

temperature and humidity data from the DHT11 sensor, facilitating the monitoring of

the incubator environment.

Figure 4.5: DHT pin configuration

Figure 4.6: DHT 11 to ESP32 wiring diagram

### 4.2.2 Relay and PTC heating element connection

The heating element utilized in the system is equipped with only two wires, and they

do not possess any polarity. The operation of the heating element is not reliant on the

direction of electric current flow. Instead, it operates based on its electrical resistance

characteristics. One wire of the heating element is connected to the ground, while the

other wire receives power from the relay.

In this specific case, a single-channel relay is employed, as it is solely required for

controlling the heating element. The relay consists of six pins. On one side, there is a

signal pin, a Vcc pin used to supply power to the relay, and a ground pin. On the

other side, there are a normally open pin, a normally closed pin, and in the middle, a

common contact point. These pins facilitate the relay's functionality in managing the

electrical connection to the heating element.

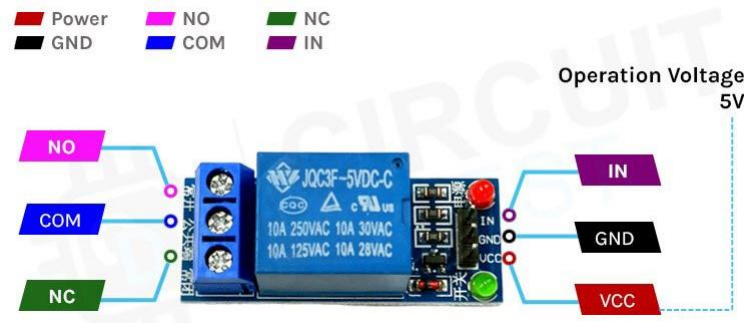
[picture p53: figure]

Figure 4.7: Single Channel relay pin-out Diagram

To power the relay, the Vcc pin is connected to the 5V supply, while the ground pin

is connected to the ground line. The objective is to keep the PTC heating element

activated until the temperature inside the incubator reaches 37℃. For this purpose,

one leg of the PTC heating element is connected to the normally closed pin of the

relay, while the other leg is connected to the ground line. Since the heating element requires a 12V supply, the 12V supply is connected to the common contact point on

the relay.

The signal pin of the relay is connected to the ESP32 microcontroller. When the DHT

sensor sends a signal to the ESP32, indicating that the temperature inside the

incubator has exceeded 37℃, the ESP32 responds by sending a high signal to the

relay. This high voltage signal triggers an internal mechanism within the relay, such

as an electromagnet or solid-state component, causing the relay to change its state.

Consequently, when the relay is triggered, it opens the circuit between the Common

(COM) and normally closed (NC) pins, effectively interrupting the power supply to

the PTC heating element and turning it off.

Once the temperature drops below 35℃, the ESP32 sends a low signal to the relay,

prompting it to close the circuit between the common point and the normally closed

pins. This action triggers the relay to turn back on, subsequently restoring power to

the heating element. This cycle ensures that the PTC heating element remains active

when the temperature is below 35℃ and is deactivated when it reaches 37℃, thereby

regulating the temperature inside the incubator.

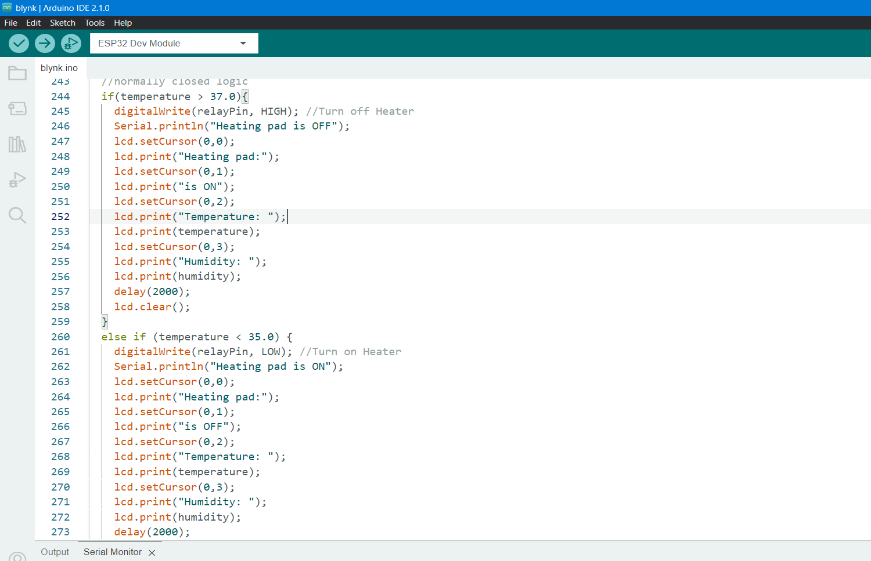
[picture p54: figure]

Figure 4.8: Image of code showing heating element conditions

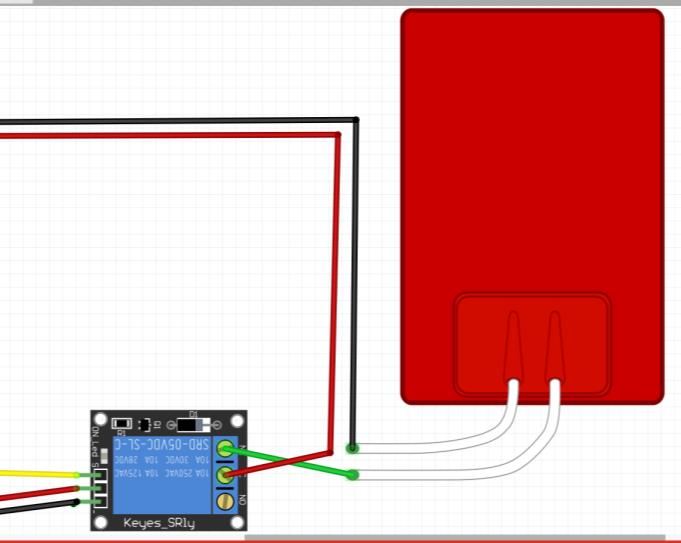
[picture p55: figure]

Figure 4.9: Relay to heater connection diagram

Figure 4.10: Image showing final soldering and wiring

### 4.3 LDR calibration and testing

The Light Dependent Resistor (LDR) plays a vital role in the project as it provides

resistance values that are essential for drawing final conclusions and inferring the

presence of coliform contamination in the tested water sample.

To obtain resistance readings from the LDR, a voltage divider circuit is employed by

connecting a known resistor in series with the LDR. This circuit setup allows for the

division of voltage across the resistors, enabling the measurement of the LDR's

resistance based on the resulting voltage values. By analyzing the resistance readings

obtained from the LDR, conclusions can be drawn regarding the potential

contamination of the water sample with coliform.

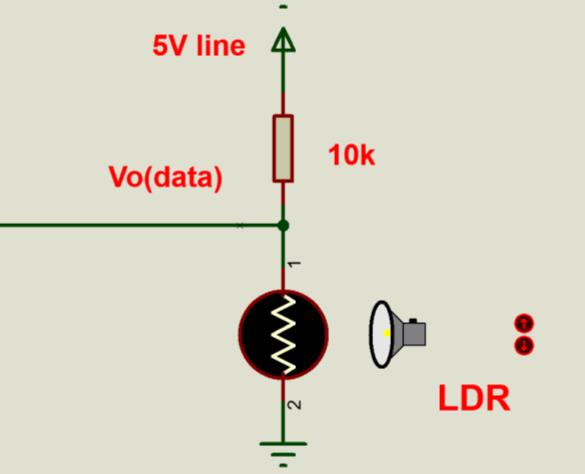
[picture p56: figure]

Figure 4.11: Voltage divider circuit for LDR

The voltage across the Light Dependent Resistor (LDR) and the known resistor

undergoes changes as the resistance of the LDR varies in response to alterations in

light intensity. In the voltage divider circuit, the junction of the LDR and the known

resistor is connected to an analog input pin on the ESP board. This analog input pin

detects the voltage at the junction and converts it into a digital value that can be read

and processed by the ESP.

By reading the voltage at the LDR and known resistor junction through the analog

input pin, it is possible to determine the state of the LDR's resistance. When the LDR

resistance is high (under low lighting conditions), the voltage across the LDR will be

higher compared to the known resistor. Conversely, in bright light conditions where

the LDR resistance is low, the voltage across the LDR will be lower relative to the

known resistor.

To convert the measured voltage into a digital value, an Analog-to-Digital Converter

(ADC) is utilized. Typically, the ESP board incorporates a built-in ADC that can

effectively convert the analog voltage into a digital value within a specific range.

### 4.3.1 Calibration and Mapping of LDRs

To capture the characteristics of each LDR, resistance readings were recorded in two

scenarios: with the LED turned on and with the LED turned off. The purpose of

obtaining the resistance reading with the LED off is to establish the maximum

resistance value for each LDR. When the LED is illuminated, all LDRs exhibit a

resistance reading of approximately 0 ohms. This process is crucial in determining an

appropriate range for the subsequent LDR readings.

Here are the approximate resistance readings obtained from the serial monitor:

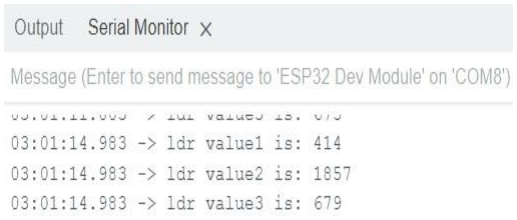
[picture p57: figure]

Figure 4.12: Serial monitor readings of LDR resistance readings while LED off

These values are mapped on a scale of 0-100 so we can visualize the values in real

time using the blynk platform.

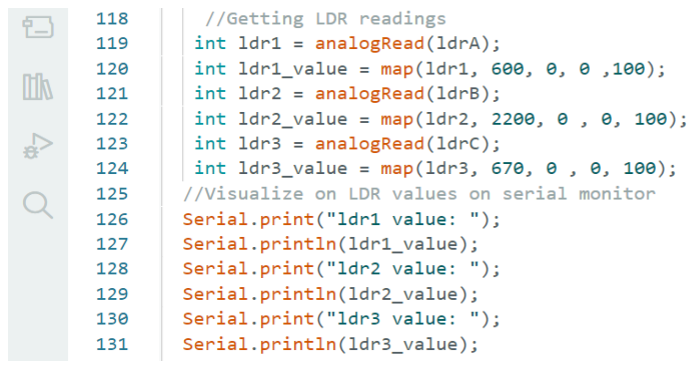
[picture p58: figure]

Figure 4.13: Code showing mapped LDR resistance values

To conduct our testing, we begin by adding 100ml of water to the pre-weighted

bottles containing the powder samples. These bottles are specifically prepared for our

testing purposes. The resulting mixture is then placed in the incubator and incubated

for a duration of 16 hours.

To validate the accuracy of our testing method and calibrate our system, we introduce

samples of coliform bacteria obtained from a microbiology laboratory into the water

samples. This ensures that our water samples are deliberately contaminated with

coliform bacteria. The presence of coliform bacteria in the water samples is indicated

by a noticeable color change, which serves as an important indicator of the bacterial

contamination we are targeting in our testing process.

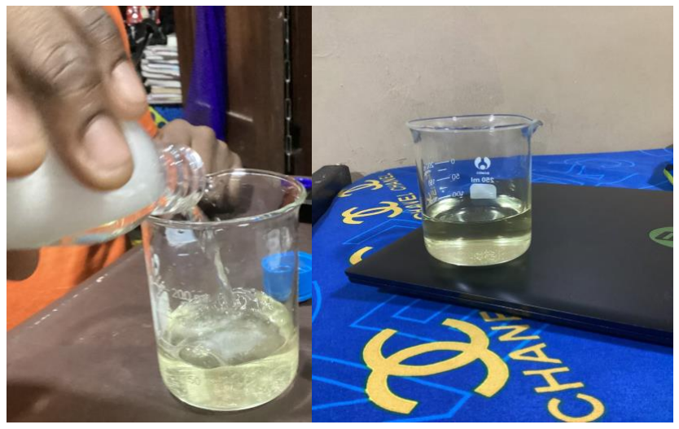
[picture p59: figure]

Figure 4.14: Water sample containing coliform bacteria mixed with water detect coliform powder

After the incubation period of 16 hours, an observable transformation takes place in

the water sample that has been infected with coliform bacteria. Initially, the color of

the infected sample is a golden hue. However, as a result of the presence of coliform

bacteria, the color of the water changes to a dark greenish shade accompanied by

significant cloudiness. On the other hand, an uninfected water sample retains its

original golden color and remains clear after the same incubation duration.

The color change in the infected sample is attributed to the enzymatic activity of

coliform bacteria, specifically an enzyme called β-galactosidase. Under the optimum

temperature range of 35 to 37 degrees Celsius (°C) required for their growth,

coliform bacteria generate acids and gases through the action of this enzyme. In the

presence of a chromogenic substrate known as indoxyl-b-D-glucuronide (IBDG), the

breakdown of this substrate by β-galactosidase leads to the production of a

fluorescent compound. In the specific case described, this fluorescence manifests as a

green coloration, thus indicating the presence of coliform bacteria in the infected

water sample.

Figure 4.15 : Water sample after 16 hours of incubation

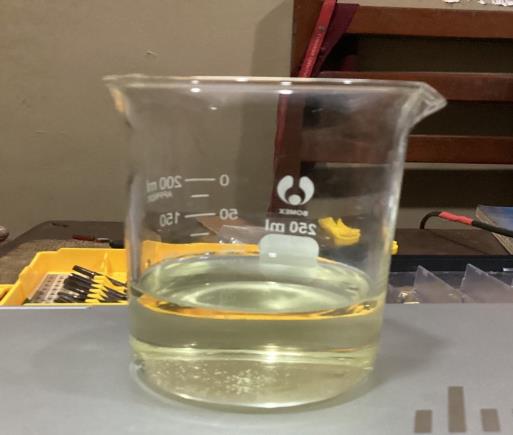
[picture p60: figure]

Figure 4.16: Color of water sample uninfected with coliform bacteria after 16 hours of incubation

The beaker holding a green, turbid water sample contaminated with coliform bacteria

was employed to establish a standard resistance range for our Light Dependent

Resistors (LDRs) when encountering coliform-contaminated water. This calibration

process took into account the sensitivity of our LDRs. Subsequently, the beaker was

successively placed on LDR 1, LDR 2, and LDR 3. The resulting resistances are

presented below.

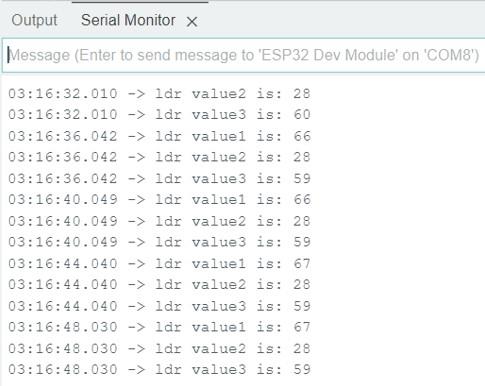
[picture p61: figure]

Figure 4.17: LDR readings when beaker with contaminated water was placed on each LDR

### 4.3.2 Final results

By utilizing the calibration of our LDR (Light Dependent Resistors), we can

determine the presence or absence of coliform bacteria in water. The LDR readings

obtained during the calibration process enable users to assess whether a specific water

sample under testing is contaminated with coliform bacteria or not. This information

provides valuable insights regarding the bacterial contamination status of the water

sample.

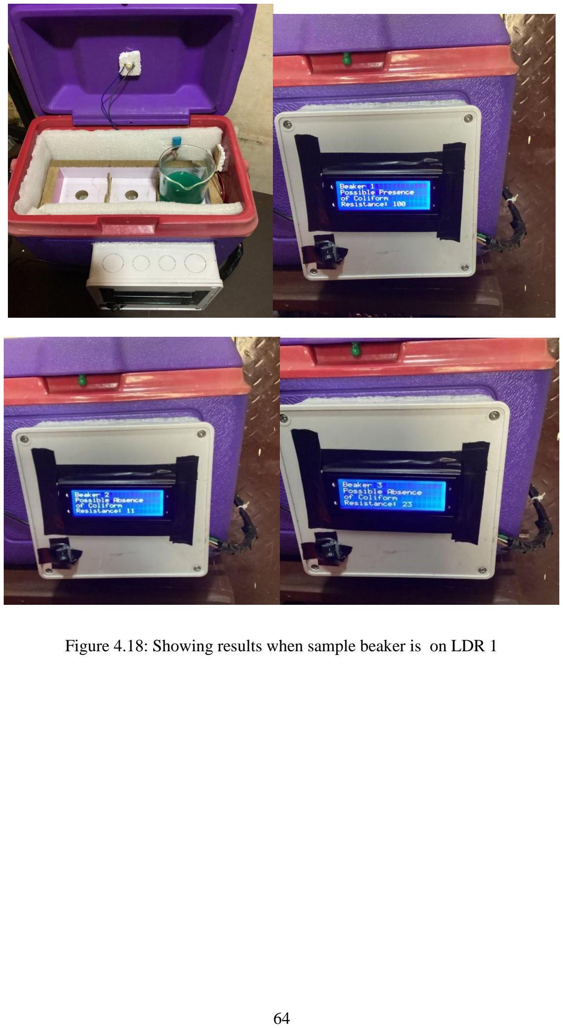
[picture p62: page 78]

Figure 4.18: Showing results when sample beaker is on LDR 1

Figure 4.19: Showing results when sample beaker is on LDR 2

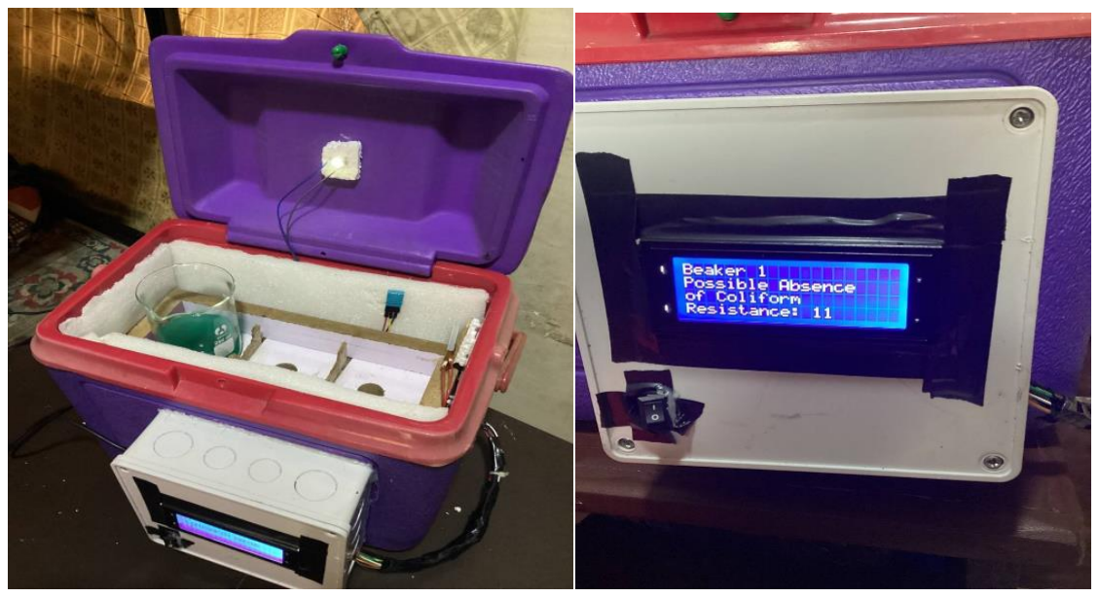
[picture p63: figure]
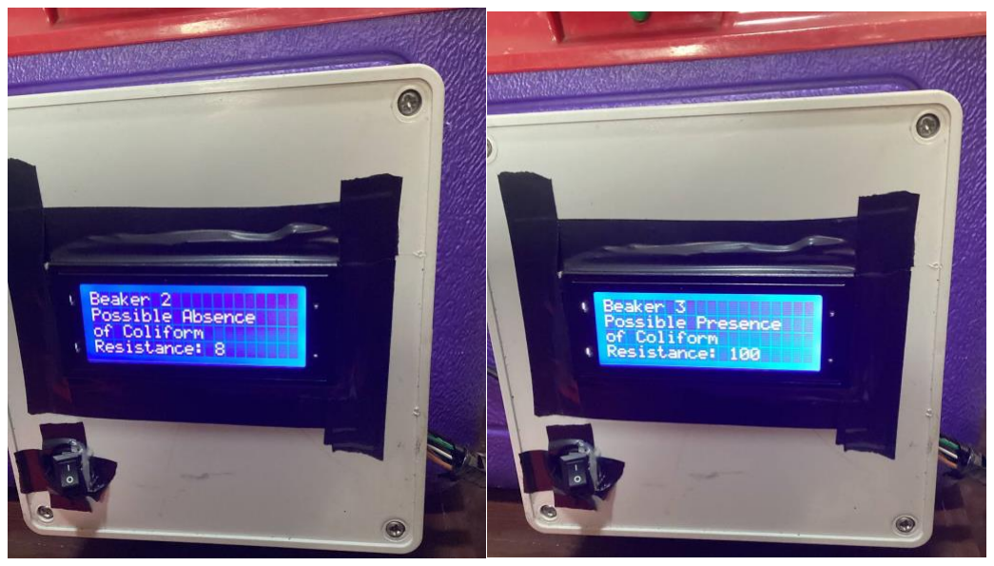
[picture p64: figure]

Figure 4.20: Showing results when sample beaker is on LDR 3

### 4.4 Bill Of Engineering Material and Evaluation (B.E.M.E)

Table 4.1: Bill Of Engineering Material and Evaluation (B.E.M.E)

S/N | COMPONENTS | QUUANTITY | UNIT PRICE (₦) | TOTAL COST (₦)
1 | Water detect coliform powder | 1 | 37,000.00 | 37,000.00
2 | AC/DC power adapter | 1 | 3,500 | 3,500.00
3 | Buck converter | 1 | 1,700 | 1,700.00
4 | ESP32 | 1 | 8,000.00 | 8,000.00
5 | LDR | 3 | 300.00 | 900.00
6 | 3.3v voltage regulator | 1 | 120.00 | 120.00
7 | Liquid Crystal Display | 1 | 4,850.00 | 4,850.00
8 | I2C module | 1 | 1,400.00 | 1,400.00
9 | 10K resistor | 4 | 10.00 | 40.00
10 | Hot glue gun | 1 | 3,240.00 | 3,240.00
11 | Cooler | 1 | 20,000 | 20,000.00
12 | DHT11 | 1 | 1,440.00 | 1,440.00
13 | PTC heating element | 1 | 3,500.00 | 3,500.00
14 | Single channel relay | 1 | 800.00 | 800.00
15 | Pattress box | 1 | 1,500 | 1,500
| | | TOTAL | 87,990

### 4.5 Summary

The project's findings are presented in this chapter. The project was assessed in

conjunction with the goals listed in Chapter One, and the operation and functionality

of the system were examined to make sure they adhered to the design standards.

Additionally, it displays a variety of images from both the testing process and the end

outcomes. There is also a Bill of Engineering Measurement and Evaluation available.

### 5. CHAPTER FIVE

CONCLUSIONS AND RECOMMENDATIONS
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

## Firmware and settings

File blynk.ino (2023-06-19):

/*FINAL YEAR PROJECT - 
TITlE: DEVELOPMENT OF A PORTABLE INCUBATOR FOR DETECTION OF COLIFORM USING IOT 
BY: OLONISAKIN DAVID AKOLADE 18CK024244 AND OGUIBE FAVOUR OZIOMA 18CK024232
EEE SET2023 #18TH SET            
SUPERVISOR: DR. OMORUYI OSEMWINGIE */

//Global declarations//
//Including necessary libraries
#include <WiFi.h>
#include <WiFiClient.h>
#include <BlynkSimpleEsp32.h>
#include <LiquidCrystal_I2C.h>
#include <Wire.h>
#include "DHT.h"

//Blynk and wifi details
#define BLYNK_TEMPLATE_ID "TMPLiD4_oZ2g"
#define BLYNK_TEMPLATE_NAME "COLIFORM DETECTION"
#define BLYNK_AUTH_TOKEN "O_Y7eWj-zfD9Y49K4kdOTx3ueyJIut6y"
#define BLYNK_PRINT Serial
//Wifi credentials and assignments
char auth[] = BLYNK_AUTH_TOKEN; 
char ssid[] = "Coliform";
char password[] = "bacteria";
unsigned long startTime;
BlynkTimer timer;
LiquidCrystal_I2C lcd(0x27 ,20,4); //20x4 lcd dinmsplay
// initialize DHT sensor
#define DHTPIN 5
#define DHTTYPE DHT11  
DHT dht(DHTPIN, DHTTYPE);
float temperature, humidity;
//setting sensor pins  to the Esp32
  int ldrA = 33 ;
  int ldrB = 35;
  int ldrC = 34;
  int relayPin = 32; 
//Functions
  void sendSensor(){ 
   float humidity = dht.readHumidity();
   float temperature = dht.readTemperature();
   int ldr1 = analogRead(ldrA);
   int ldr1_value = map(ldr1, 600, 0, 0 ,100);
   int ldr2 = analogRead(ldrB);
   int ldr2_value = map(ldr2, 2200, 0 , 0, 100);
   int ldr3 = analogRead(ldrC); 
   int ldr3_value = map(ldr3, 670, 0 , 0, 100);
   Blynk.virtualWrite(V2, ldr1_value);
   Blynk.virtualWrite(V3, ldr2_value);
   Blynk.virtualWrite(V4, ldr3_value);
   Blynk.virtualWrite(V6, humidity);
   Blynk.virtualWrite(V5, temperature);
  }
  void updateLedBlynk(){
   int status = digitalRead(relayPin);
   if (status == LOW)
   {
     Blynk.virtualWrite(V1, HIGH);
   }
   else
   {
     Blynk.virtualWrite(V1, LOW);
   }
  }

void setup(){
 //initialize serial communication at 115200 bit/s
  Serial.begin(115200);
  Serial.println("System is ON, Coliform Test");
  delay(2000);
  lcd.begin();  //initialize LCD
  dht.begin();  // initialize DHT sensor
  startTime = millis(); // record the current time in milliseconds
  pinMode(relayPin, OUTPUT);
  pinMode(DHTPIN, INPUT);
  // Display startup messages on LCD
  lcd.setCursor(0,2);
  lcd.print("PROJECT TOPIC:");
  delay(2500);
  lcd.clear();
  lcd.setCursor(0,0);
  lcd.print("DEVELOPMENT OF A");
  lcd.setCursor(0,1);
  lcd.print("PORTABLE INCUBATOR");
  lcd.setCursor(0,2);
  lcd.print("FOR DETECTION OF"); 
  lcd.setCursor(0,3);
  lcd.print("COLIFORM USING IOT");     
  delay(4000);
  lcd.clear();
  lcd.setCursor(0,0);
  lcd.print("BY");
  lcd.setCursor(0,1);
  lcd.print("OLONISAKIN DAVID");
  lcd.setCursor(0,2);
  lcd.print("AND");
  lcd.setCursor(0,3);
  lcd.print("OGUIBE FAVOUR");
  delay(4000);
  lcd.clear();
  lcd.setCursor(0,1);
  lcd.print("LOADING ....");
  delay(2000);
  lcd.setCursor(0,1);
  lcd.print("Connecting....");
  delay(2000);
  lcd.clear();
  //Setting up Blynk Application 
  Blynk.begin(auth, ssid, password);
  // Setting interval to send data to Blynk Cloud to 1000ms. It means that data will be sent every second
  timer.setInterval(1000L, sendSensor);
  timer.setInterval(1000L, updateLedBlynk);  
}

void loop() {
  Blynk.run();
  timer.run();//Initiates blynkTimer
    //Getting LDR readings
   int ldr1 = analogRead(ldrA);
   int ldr1_value = map(ldr1, 600, 0, 0 ,100);
   int ldr2 = analogRead(ldrB);
   int ldr2_value = map(ldr2, 2200, 0 , 0, 100);
   int ldr3 = analogRead(ldrC); 
   int ldr3_value = map(ldr3, 670, 0 , 0, 100);
  //Visualize on LDR values on serial monitor
  Serial.print("ldr1 value: ");
  Serial.println(ldr1_value);
  Serial.print("ldr2 value: ");
  Serial.println(ldr2_value);
  Serial.print("ldr3 value: ");
  Serial.println(ldr3_value);
  unsigned long uptime = millis() - startTime;
  int seconds = (uptime / 1000) % 60; // extract the seconds from the uptime
  int minutes = (uptime / (1000 * 60)) % 60; // extract the minutes from the uptime
  int hours = (uptime / (1000 * 60 * 60)) % 24; // extract the hours from the uptime
  lcd.setCursor(0,1);
  lcd.print("Coliform Test");
  lcd.setCursor(0, 2); // set the cursor to the top right corner
  lcd.print("Time: "); // print the label
  lcd.print(hours); // print the number of hours
  lcd.print("h ");
  lcd.print(minutes); // print the number of minutes
  lcd.print("m ");
  lcd.print(seconds); // print the number of seconds
  lcd.print("s");
  delay(4000) ;
  lcd.clear();
  lcd.setCursor(0,1);
  lcd.print("Rechecking...."); 
  delay(3000);
  lcd.clear();
  lcd.setCursor(0,1);
  lcd.print("Checking Status");   
  lcd.setCursor(0,2);
  lcd.print("in the incubator");
  delay(3000);
  sendSensor();
  updateLedBlynk();
  //UPTIME - CONDITION
  if(uptime % 20 == 0){
  lcd.setCursor(0,0);
  lcd.print("PROJECT TOPIC:");
  delay(2500);
  lcd.clear();
  lcd.setCursor(0,0);
  lcd.print("DEVELOPMENT OF A");
  lcd.setCursor(0,1);
  lcd.print("PORTABLE INCUBATOR");
  lcd.setCursor(0,2); 
  lcd.print("FOR DETECTION OF"); 
  lcd.setCursor(0,3);
  lcd.print("COLIFORM USING IOT");     
  delay(4000);
}
//<<<<Checking beakers if coliform bacteria is present or not>>>>>>>>>>>//
if (ldr1_value < 66) {
  lcd.clear();
  lcd.setCursor(0, 0);
  lcd.print("Beaker 1");
  lcd.setCursor(0, 1);
  lcd.print("Possible Absence");
  lcd.setCursor(0, 2);
  lcd.print("of Coliform");
  lcd.setCursor(0,3);
  lcd.print("Resistance: " + String(ldr1_value));
  delay(3000);
 }
else{
  lcd.clear();
  lcd.setCursor(0, 0);
  lcd.print("Beaker 1");
  lcd.setCursor(0, 1);
  lcd.print("Possible Presence");
  lcd.setCursor(0, 2);
  lcd.print("of Coliform");
  lcd.setCursor(0,3);
  lcd.print("Resistance: " + String(ldr1_value));
  delay(3000);
}
lcd.clear(); // clear the LCD after displaying the status of beaker 1
if(ldr2_value < 28){
  lcd.clear();
  lcd.setCursor(0, 0);
  lcd.print("Beaker 2");
  lcd.setCursor(0, 1);
  lcd.print("Possible Absence");
  lcd.setCursor(0, 2);
  lcd.print("of Coliform");
  lcd.setCursor(0,3);
  lcd.print("Resistance: " + String(ldr2_value));
  delay(3000);
}
else{
  lcd.clear();
  lcd.setCursor(0, 0);
  lcd.print("Beaker 2");
  lcd.setCursor(0, 1);
  lcd.print("Possible Presence");
  lcd.setCursor(0, 2);
  lcd.print("of Coliform");
  lcd.setCursor(0,3);
  lcd.print("Resistance: " + String(ldr2_value));
  delay(3000);
}
lcd.clear(); // clear the LCD after displaying the status of beaker 2

if(ldr3_value < 59){
  lcd.clear();
  lcd.setCursor(0, 0);
  lcd.print("Beaker 3");
  lcd.setCursor(0, 1);
  lcd.print("Possible Absence");
  lcd.setCursor(0, 2);
  lcd.print("of Coliform");
  lcd.setCursor(0,3);
  lcd.print("Resistance: " + String(ldr3_value));
  delay(2000);
}
else{
  lcd.clear();
  lcd.setCursor(0, 0);
  lcd.print("Beaker 3");
  lcd.setCursor(0, 1);
  lcd.print("Possible Presence");
  lcd.setCursor(0, 2);
  lcd.print("of Coliform");
  lcd.setCursor(0,3);
  lcd.print("Resistance: " + String(ldr3_value));
  delay(2000); 
}
lcd.clear(); // clear the LCD after displaying the status of beaker 2
//DHT22 sensor
  float temperature = dht.readTemperature();
  float humidity = dht.readHumidity();
  //<<<<<<<<<<<<<<<<<CONDITIONAL STATEMENTS>>>>>>>>>>>>>>>>>>>>>>
  // checking if reading from sensor was successful
  if (isnan(temperature) || isnan(humidity)) {
    Serial.println(F("Failed to read from DHT sensor!"));
    return;
  }
  // check if temperature is within desired range
  //normally closed logic
  if(temperature > 37.0){
    digitalWrite(relayPin, HIGH); //Turn off Heater
    Serial.println("Heating pad is OFF");
    lcd.setCursor(0,0);
    lcd.print("Heating pad:");
    lcd.setCursor(0,1);
    lcd.print("is OFF");
    lcd.setCursor(0, 2);
    lcd.print("Temperature:" + String(temperature) + "°C");
    lcd.setCursor(0, 3);
    lcd.print("Humidity:" + String(humidity) + "%");
    delay(3000); 
    lcd.clear();
  }
  else if (temperature < 35.0) {
    digitalWrite(relayPin, LOW); //Turn on Heater
    Serial.println("Heating pad is ON");
    lcd.setCursor(0,0);
    lcd.print("Heating pad:");
    lcd.setCursor(0,1);
    lcd.print("is ON");
    lcd.setCursor(0,2);
    lcd.print("Temperature:" + String(temperature) + "°C");
    lcd.setCursor(0, 3);
    lcd.print("Humidity:" + String(humidity) + "%");
    delay(3000); 
    lcd.clear();
  }
  
  else{
    Serial.println(F("Temperature within range."));
    lcd.setCursor(0,0);
    lcd.print("Optimal Temperature");
    lcd.setCursor(0,1);
    lcd.print("Temperature:" + String(temperature) + "°C");
    lcd.setCursor(0, 2);
    lcd.print("Humidity:" + String(humidity) + "%");
    delay(3000); 
    lcd.clear(); 
  }
//DHT22 Live temperature on Serial MOnitor
  Serial.print("temperature: ");
  Serial.println(temperature);
  Serial.print("humidity: ") ;
  Serial.println(humidity);
//condition when 16hour is reached
  if(uptime == 57600000){
    lcd.clear();
    lcd.setCursor(0,1);
    lcd.print("INCUBATION PROCESS");
    lcd.setCursor(3, 2);
    lcd.print("COMPLETE");
    lcd.clear();
    lcd.setCursor(0,1);
    lcd.print(".FINAL RESULTS.");
    lcd.clear();
    lcd.setCursor(0,1);
    lcd.print("Please Wait..");
    delay(3000);
    //Printing out final result of project analysis
    //drawing conclusion from the 16hour test
    //Check LDR1 value
    switch (ldr1_value < 66) {
      case true:
        lcd.clear();
        lcd.setCursor(0, 0);
        lcd.print("Beaker 1");
        lcd.setCursor(0, 1);
        lcd.print("Coliform ABSENT");
        lcd.setCursor(0, 2);
        lcd.print("Water is Safe");
        lcd.setCursor(0, 3);
        lcd.print("To Drink");  
        delay(3000);   
        lcd.clear(); 
        break;
      case false:
        lcd.clear();
        lcd.setCursor(0, 0);
        lcd.print("Beaker 1");
        lcd.setCursor(0, 1);
        lcd.print("Coliform PRESENT");
        lcd.setCursor(0, 2);
        lcd.print("Water is Unsafe");
        lcd.setCursor(0, 3);
        lcd.print("Don't Drink!!"); 
        delay(3000);
        lcd.clear();
        break;
    }

    // Check LDR2 value
    switch (ldr2_value < 28) {
      case true:
        lcd.clear();
        lcd.setCursor(0, 0);
        lcd.print("Beaker 2");
        lcd.setCursor(0, 1);
        lcd.print("Coliform ABSENT");
        lcd.setCursor(0, 2);
        lcd.print("Water is Safe");
        lcd.setCursor(0, 3);
        lcd.print("To Drink");
        delay(3000); 
        lcd.clear(); 
        break;
      case false:
        lcd.clear();
        lcd.setCursor(0, 0);
        lcd.print("Beaker 2");
        lcd.setCursor(0, 1);
        lcd.print("Coliform PRESENT");
        lcd.setCursor(0, 2);
        lcd.print("Water is Unsafe");
        lcd.setCursor(0, 3);
        lcd.print("Don't Drink");
        delay(3000);  
        lcd.clear();
        break;
    }

  // Check LDR3 value
  switch (ldr3_value < 59) {
    case true:
      lcd.clear();
      lcd.setCursor(0, 0);
      lcd.print("Beaker 3");
      lcd.setCursor(0, 1);
      lcd.print("Coliform ABSENT");
      lcd.setCursor(0, 2);
      lcd.print("Water is Safe");
      lcd.setCursor(0, 3);
      lcd.print("To Drink");
      delay(3000);  
      lcd.clear();
      break;
    case false:
      lcd.clear();
      lcd.setCursor(0, 0);
      lcd.print("Beaker 3");
      lcd.setCursor(0, 1);
      lcd.print("Coliform PRESENT");
      lcd.setCursor(0, 2);
      lcd.print("Water is Unsafe");
      lcd.setCursor(0, 3);
      lcd.print("Don't Drink");
      delay(3000);  
      lcd.clear();
      break;
  }
  }
}

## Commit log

2023-06-17 update of working code
    [CircuitDiagram - fritzing.fzz]
2023-06-22 just defended
    [CircuitDiagram - fritzing.fzz]
